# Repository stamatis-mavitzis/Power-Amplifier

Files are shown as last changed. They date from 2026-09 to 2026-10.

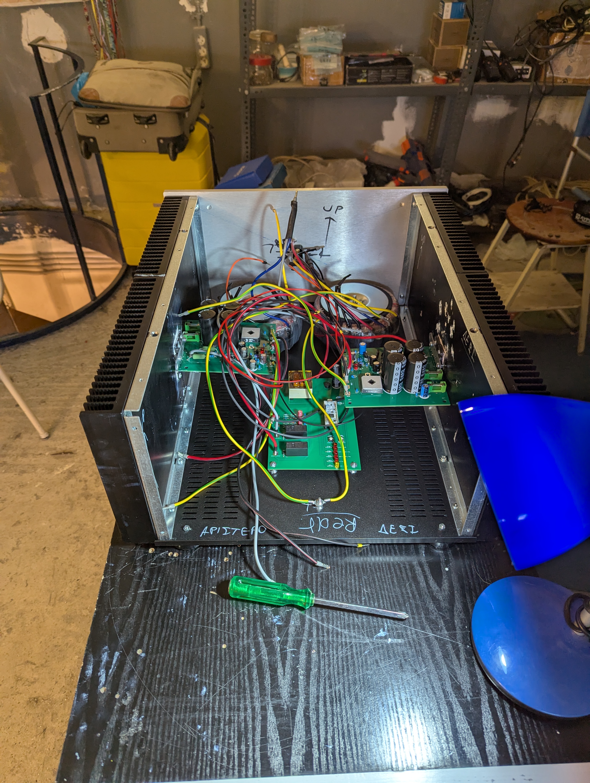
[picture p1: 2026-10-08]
Images/PXL_20261008_074426405.MP.jpg

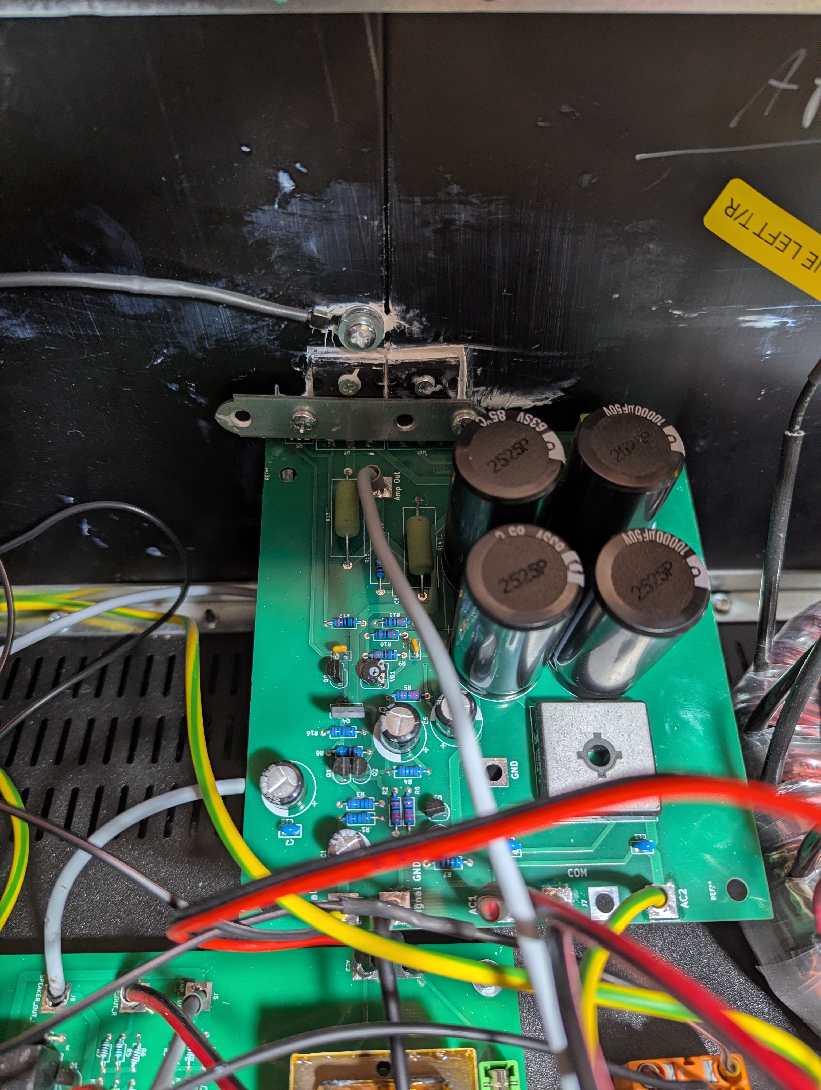
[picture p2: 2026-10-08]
Images/PXL_20261008_150713797.jpg

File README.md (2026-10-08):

<div align="center">

# Hi‑Fi Class‑AB Power Amplifier

### Stereo discrete power amplifier with dual 500 VA supplies, STM32 speaker protection, thermal monitoring, KiCad hardware, firmware, and measured prototype validation

**KiCad · Discrete Class‑AB · ≈±34.5 V Idle Rails · STM32G031K8 · Speaker Protection · Thermal Monitoring**






</div>

---

## Overview

This repository contains the design, implementation, firmware, fabrication files, and measured validation of a two-channel discrete **Hi‑Fi Class‑AB power amplifier** developed in **KiCad**.

The power-amplifier stage is based on the design principles of **Rod Elliott's Elliott Sound Products (ESP) Project 3A**. This implementation expands that reference design into a complete stereo amplifier system with:

- one dedicated **500 VA transformer per audio channel**;
- independent high-current rectification and filtering for the left and right channels;
- custom amplifier and power-supply PCBs;
- **MJL21193G / MJL21194G** complementary output devices;
- a dedicated **STM32G031K8 speaker-protection controller**;
- independent left/right DC monitoring;
- dual heatsink-temperature monitoring;
- relay-controlled speaker outputs;
- firmware for startup delay, fault handling, thermal protection, and status indication;
- measured electrical validation of the completed prototype.

The repository is intended to document the project from schematic design and PCB layout through assembly, firmware, bring-up, and bench testing.

---

## Project Status

The amplifier has progressed beyond the design-only stage.

Current status:

- amplifier PCBs assembled;
- power-supply hardware assembled;
- dual-transformer stereo supply implemented;
- STM32 protection system programmed and tested;
- left and right amplifier channels operational;
- speaker relays and protection functions tested;
- DC operating points measured;
- quiescent bias measured cold and warm;
- rail voltages measured at idle and under 8 Ω load;
- rail ripple measured under load;
- frequency-response checks completed;
- upper −3 dB point measured;
- final bench-test results recorded.

The project should therefore be described as a **built and functionally validated prototype**, not only as a planned or fabrication-ready design.

---

## Table of Contents

- [Key Features](#key-features)
- [Technical Summary](#technical-summary)
- [Measured Performance](#measured-performance)
- [System Architecture](#system-architecture)
- [Power Amplifier](#power-amplifier)
- [Power Supply](#power-supply)
- [STM32 Protection Controller](#stm32-protection-controller)
- [Protection Logic](#protection-logic)
- [Thermal Management](#thermal-management)
- [PCB Design Strategy](#pcb-design-strategy)
- [Grounding Strategy](#grounding-strategy)
- [Major Components](#major-components)
- [Test Equipment](#test-equipment)
- [Repository Structure](#repository-structure)
- [Manufacturing Files](#manufacturing-files)
- [Bring-Up and Validation](#bring-up-and-validation)
- [Measurement Limitations](#measurement-limitations)
- [Safety](#safety)
- [Design Tools](#design-tools)
- [Reference Design and Credits](#reference-design-and-credits)
- [Author](#author)

---

## Key Features

### Audio Power Stage

- Two-channel discrete **Class‑AB** architecture
- One amplifier PCB per channel
- Complementary bipolar output stage
- **MJL21193G / MJL21194G** complementary output transistor pair
- **BD139 / BD140** driver stage
- **0.33 Ω / 5 W** emitter resistors
- Through-hole power devices for serviceability and heatsink mounting
- Dedicated external heatsink for each amplifier channel
- On-board **3 A** positive- and negative-rail fuses

### Main Power Supply

- **2 × 500 VA transformers**
- One transformer dedicated to the **left channel**
- One transformer dedicated to the **right channel**
- Nominal dual low-voltage secondary windings
- Measured transformer secondary voltages of approximately **25.5–25.7 VRMS per half-secondary**
- High-current bridge rectification
- **KBPC3506WP** bridge rectifier in the power-supply design
- Four **4700 µF** reservoir capacitors on the power-supply schematic
- Measured idle rails of approximately **+34.5 V / −34.5 V**
- Measured loaded rails of approximately **±33.5 to ±33.7 V** with an 8 Ω load

### Protection and Monitoring

- **ST NUCLEO‑G031K8**
- **STM32G031K8** microcontroller
- Independent left/right amplifier-output monitoring
- Independent left/right heatsink-temperature monitoring
- 10 kΩ NTC thermistors
- Startup speaker delay
- Persistent-DC fault detection
- Overtemperature shutdown
- Sensor-fault handling
- Latched fault handling and reset
- Relay-controlled left/right speaker outputs
- Front-panel status indication

### Mechanical and Thermal Design

- Large external heatsinks
- Passive natural-convection cooling
- Power transistors positioned near PCB edges for heatsink mounting
- Electrical insulation between power-transistor tabs and heatsink where required
- Metal-chassis integration
- Star-ground implementation
- Chassis protective-earth bonding
- High-current speaker and supply wiring separated from low-level input wiring

---

## Technical Summary

| Parameter | Final implementation |
|---|---|
| Amplifier topology | Discrete Class‑AB |
| Number of channels | 2 |
| Main transformers | **2 × 500 VA**, one per channel |
| Measured secondary voltage | ≈25.5–25.7 VRMS from each outer secondary lead to center tap |
| Measured idle rails | ≈+34.5 V / −34.5 V |
| Measured rails under 8 Ω test load | ≈±33.5 to ±33.7 V |
| Output devices | **MJL21194G (NPN) / MJL21193G (PNP)** |
| Output-device package | **TO‑264, through-hole** |
| Driver devices | **BD139 / BD140** |
| Output emitter resistors | **R13 / R14 = 0.33 Ω, 5 W** |
| Amplifier rail fuses | **3 A** |
| Protection controller | ST NUCLEO‑G031K8 |
| MCU | STM32G031K8 |
| Speaker relays | 2 × Omron G2RL‑1A‑E‑DC12 |
| Relay driver | BC337 NPN |
| Temperature sensing | 2 × 10 kΩ NTC |
| Cooling | External heatsinks, passive natural convection |
| Audio inputs | RCA |
| Speaker outputs | Chassis-mounted binding terminals |
| PCB CAD | KiCad |

---

# Measured Performance

The following values were measured on the completed prototype. They are reported as **bench-test results**, not as guaranteed production specifications.

## Transformer Secondary Voltages

Measured from each AC secondary lead to the center tap:

| Measurement | Left | Right |
|---|---:|---:|
| AC1 → center tap | 25.652 VRMS | 25.628 VRMS |
| AC2 → center tap | 25.631 VRMS | 25.516 VRMS |

The measurements show good agreement between the two transformer channels.

## DC Supply Rails

### Idle

| Rail | Left | Right |
|---|---:|---:|
| Positive | +34.521 V | +34.566 V |
| Negative | −34.532 V | −34.522 V |

### Under 8 Ω Amplifier Load

| Rail | Left | Right |
|---|---:|---:|
| Positive | +33.534 V | +33.678 V |
| Negative | −33.560 V | −33.701 V |

The measured rail reduction under the recorded load condition is approximately 0.8–1.0 V compared with idle.

## Rail Ripple Under 8 Ω Load

Recorded ripple values:

| Rail | Left | Right |
|---|---:|---:|
| Positive rail | 1.5 V | 1.4 V |
| Negative rail | 1.6 V | 1.4 V |

These values are reproduced as recorded in the measurement log. They should not be interpreted as a different RMS or peak-to-peak quantity unless the oscilloscope measurement mode used during the test is also specified.

## Quiescent Bias

Bias was measured as the voltage across **R13 + R14**.

Because each emitter resistor is **0.33 Ω**, the combined resistance is **0.66 Ω**.

| Channel | Cold voltage | Approx. cold current | Warm voltage | Approx. warm current |
|---|---:|---:|---:|---:|
| Left | 41.700 mV | 63.2 mA | 52.55 mV | 79.6 mA |
| Right | 41.730 mV | 63.2 mA | 55.71 mV | 84.4 mA |

The increase from cold to warm operation is documented so that bias thermal behaviour remains traceable.

## DC Output Offset

Initial recorded DC-offset measurements:

| Channel | DC offset |
|---|---:|
| Left | −54.54 mV |
| Right | −28.203 mV |

A later no-signal measurement recorded:

| Channel | Amplifier output |
|---|---:|
| Left | +42.300 mV |
| Right | −23.764 mV |

Because these measurements were taken at different points in the test sequence, they are retained separately rather than combined into a single nominal value.

## Frequency Response and Voltage Gain

With:

- input signal: **1.2 V peak-to-peak**;
- sine-wave test;
- test frequencies: **20 Hz, 50 Hz, 100 Hz, 500 Hz, 1 kHz, 5 kHz, 10 kHz, 20 kHz**;

the recorded output was approximately:

- Left: **22.6 V peak-to-peak**
- Right: **22.6 V peak-to-peak**

This corresponds to:

- voltage gain: **18.83 V/V**
- voltage gain: **25.50 dB**

No significant amplitude reduction was recorded over the tested **20 Hz to 20 kHz** audio band.

The recorded **upper −3 dB frequency** is approximately:

**250 kHz**

The protection controller may interpret very-low-frequency content below approximately **15 Hz** as a DC-like condition. This is a **protection-system behaviour**, not the amplifier's measured low-frequency −3 dB cutoff.

## 8 Ω Loaded Signal Test

With an **8 Ω load** and **Vin = 1.2 V peak-to-peak**:

| Channel | Vout | Gain V/V | Gain dB | Approx. power into 8 Ω |
|---|---:|---:|---:|---:|
| Left | 27.2 Vpp | 22.67 | 27.11 dB | 11.56 W |
| Right | 26.6 Vpp | 22.17 | 26.91 dB | 11.06 W |

The right-channel gain is **26.91 dB** from the recorded 26.6 Vpp / 1.2 Vpp values.

This test point is **not** the maximum unclipped output-power rating of the amplifier. It only documents the specific load and signal level used during that measurement.

## Protection-System Measurements

Healthy amplifier outputs produced the following DC-sense ADC voltages:

| Channel | ADC sense voltage |
|---|---:|
| Left | 1.6014 V |
| Right | 1.5969 V |

Relay-driver base voltage with relays ON:

| Channel | Base voltage |
|---|---:|
| Left | 3.2932 V |
| Right | 3.2931 V |

Relay-coil voltage with relays ON:

| Channel | Coil voltage |
|---|---:|
| Left | 11.723 V |
| Right | 11.735 V |

NTC room-temperature readings:

| Sensor | Voltage |
|---|---:|
| NTC 1 | 1.1230 V |
| NTC 2 | 1.1225 V |

The remaining protection-system functional tests were recorded as **passed**.

---

## System Architecture

The complete amplifier is divided into three main functional paths:

1. **Audio path**
2. **Power path**
3. **Protection path**

### Audio Path

```text
RCA INPUT
    │
    ▼
┌───────────────────────┐
│  Discrete Class‑AB    │
│  Power Amplifier      │
│                       │
│  • Input stage        │
│  • Voltage gain stage │
│  • Bias network       │
│  • Driver stage       │
│  • Output stage       │
└───────────┬───────────┘
            │
            ▼
┌───────────────────────┐
│  Speaker Protection   │
│  Relay                │
└───────────┬───────────┘
            │
            ▼
       SPEAKER OUT
```

### Power Path

```text
                         230 VAC MAINS
                               │
               ┌───────────────┴───────────────┐
               ▼                               ▼
      500 VA TRANSFORMER #1           500 VA TRANSFORMER #2
           LEFT CHANNEL                    RIGHT CHANNEL
               │                               │
               ▼                               ▼
       RECTIFIER + FILTER              RECTIFIER + FILTER
               │                               │
               ▼                               ▼
        LEFT ±34 V RAILS                RIGHT ±34 V RAILS
               │                               │
               ▼                               ▼
        LEFT AMPLIFIER                  RIGHT AMPLIFIER
```

Each channel therefore has its own transformer and power-supply path, reducing shared supply impedance between the two amplifier channels.

### Protection Path

```text
Left Amp Output  ─────► DC Sense ───────┐
Right Amp Output ─────► DC Sense ───────┤
Left Heatsink NTC ────► Temp Sense ─────┤
Right Heatsink NTC ───► Temp Sense ─────┤
                                         ▼
                              ┌────────────────────┐
                              │   STM32G031K8      │
                              │                    │
                              │ • ADC acquisition  │
                              │ • Startup delay    │
                              │ • Fault logic      │
                              │ • Thermal logic    │
                              └─────────┬──────────┘
                                        │
                                  Relay drivers
                                        │
                                  ┌─────┴─────┐
                                  ▼           ▼
                              Left relay  Right relay
                                  │           │
                                  ▼           ▼
                              Left spk.   Right spk.
```

---

## Power Amplifier

The audio section uses a conventional **discrete Class‑AB power-amplifier topology** based on the principles of ESP Project 3A.

Functional stages include:

1. **Input stage** — accepts the low-level audio signal.
2. **Voltage-amplification stage** — provides the main voltage gain.
3. **Bias network** — establishes Class‑AB idle current.
4. **Driver stage** — provides base drive for the power output devices.
5. **Complementary output stage** — supplies current to the loudspeaker.

### Output Devices

| Reference | Device | Polarity | Package |
|---|---|---|---|
| Q7 | **MJL21193G** | PNP | TO‑264 |
| Q8 | **MJL21194G** | NPN | TO‑264 |

The output devices are mounted close to the PCB edge so that they can be attached directly to the external heatsink.

Electrical isolation hardware and thermal-interface material must be used where required by the mechanical installation.

### Driver Stage

The amplifier uses complementary **BD139 / BD140** driver transistors.

### Output Emitter Resistors

- **R13 = 0.33 Ω / 5 W**
- **R14 = 0.33 Ω / 5 W**

These resistors are also used as convenient measurement points for the output-stage quiescent current.

### Rail Protection

Each amplifier board includes:

- **3 A fuse in the positive rail**
- **3 A fuse in the negative rail**

These fuses protect the amplifier board but do not replace the required mains-side transformer protection.

---

## Power Supply

The final stereo implementation uses a **dual-mono-style power architecture**:

- one **500 VA transformer** for the left channel;
- one **500 VA transformer** for the right channel.

Each transformer has a center-tapped secondary arrangement and feeds its own rectifier/filter path.

Measured secondary voltages are approximately **25.5–25.7 VRMS from each outer secondary lead to the center tap**.

After rectification and reservoir filtering, the measured idle rails are approximately:

```text
+34.5 V
  0 V
−34.5 V
```

Under the recorded 8 Ω load test, the rails remained approximately **±33.5 to ±33.7 V**.

### Rectification and Filtering

The power-supply schematic uses:

- **Diotec KBPC3506WP** bridge rectifier;
- four **4700 µF** reservoir capacitors;
- local bypass capacitors;
- heavy-current connections for the DC rails and common return.

### Power-Supply Design Priorities

- short transformer-to-rectifier wiring;
- short rectifier-to-reservoir-capacitor paths;
- adequate conductor cross-section;
- deliberate star grounding;
- high-current speaker returns separated from input ground;
- secure protective-earth bonding;
- mains-rated switchgear, wiring, insulation, and fuse protection;
- independent left/right channel supply paths.

---

## STM32 Protection Controller

Speaker protection is implemented with an **ST NUCLEO‑G031K8** carrying the **STM32G031K8** microcontroller.

The controller supervises both amplifier channels and only connects the loudspeakers when the monitored conditions are safe.

### ADC Inputs

The controller monitors:

| Signal | MCU pin / ADC input |
|---|---|
| TEMP1 | PA0 / A0 |
| TEMP2 | PA1 / A1 |
| DC_LEFT | PA4 / A2 |
| DC_RIGHT | PA5 / A3 |

The firmware uses ADC averaging to improve measurement stability.

### Protection Timing and Thermal Thresholds

Current firmware configuration includes:

- startup delay: **3 s**
- periodic protection sampling
- overtemperature trip: approximately **100 °C**
- thermal reset threshold: approximately **90 °C**
- latched fault handling where applicable
- manual fault-reset support

### Controlled Outputs

The controller operates:

- left speaker relay;
- right speaker relay;
- status and fault LEDs;
- relay drivers through BC337 transistors.

---

## Protection Logic

### Startup Delay

At power-up, the loudspeakers remain disconnected while the MCU initializes and checks the monitored conditions.

```text
POWER ON
   │
   ▼
MCU INITIALIZATION
   │
   ▼
ADC + GPIO INITIALIZATION
   │
   ▼
VERIFY SENSOR / DC CONDITIONS
   │
   ▼
3 s STARTUP DELAY
   │
   ▼
ENABLE SPEAKER RELAYS
```

If a fault exists, the speaker relays remain disabled.

### DC Protection

The left and right amplifier outputs are independently monitored through conditioned ADC inputs.

A persistent abnormal positive or negative DC component causes the controller to disable the associated speaker connection.

```text
ABNORMAL DC
     │
     ▼
STM32 FAULT DECISION
     │
     ▼
RELAY DRIVER OFF
     │
     ▼
SPEAKER DISCONNECTED
```

The healthy operating point of the DC-sense channels is approximately **1.6 V**, allowing the circuit to detect excursions in either direction.

### Very-Low-Frequency Behaviour

The implemented protection logic may classify signals below approximately **15 Hz** as DC-like.

This should not be confused with the amplifier's audio-band frequency response.

### Temperature Protection

Each channel uses a **10 kΩ NTC thermistor** attached to the thermal system.

```text
LEFT HEATSINK  ──► NTC ──► ADC
RIGHT HEATSINK ──► NTC ──► ADC
```

The controller can disconnect the loudspeakers when the thermal trip threshold is reached.

### Relay Drive

The STM32 does not energize the relay coils directly.

Each channel uses:

```text
STM32 GPIO
    │
    ▼
Base resistor
    │
    ▼
BC337 NPN
    │
    ▼
12 V relay coil
    │
    └── Flyback diode
```

Measured relay-coil voltage in the ON state is approximately **11.7 V**.

### Speaker Relays

Two **Omron G2RL‑1A‑E‑DC12** relays are used:

- one for the left channel;
- one for the right channel.

---

## Thermal Management

The amplifier is designed for passive cooling using external chassis heatsinks.

The thermal design includes:

- one external heatsink per amplifier channel;
- direct mounting of the TO‑264 power transistors;
- electrical insulation where required;
- thermal compound / thermal interface material;
- NTC sensing;
- firmware-based overtemperature protection;
- natural-convection airflow;
- no fan dependency.

The output-stage bias was measured both cold and after thermal stabilization to document thermal drift.

---

## PCB Design Strategy

The PCB layout was developed with audio performance, current handling, serviceability, and manufacturability in mind.

### High-Current Paths

High-current paths include:

- rectifier connections;
- reservoir-capacitor charging loops;
- ± rail distribution;
- output-stage supply paths;
- speaker-output routing;
- speaker-return current;
- relay contacts.

These paths should be kept short and wide.

### Small-Signal Paths

Sensitive nodes include:

- RCA input;
- input-stage circuitry;
- feedback network;
- bias-related nodes;
- low-level signal ground.

These are kept away from rectifier, relay-coil, transformer, and speaker-current paths as much as practical.

### Serviceability

Through-hole components are used extensively so that stressed devices, connectors, relays, drivers, and power transistors can be replaced during repair or development.

---

## Grounding Strategy

The final system uses a deliberate **star-ground approach**.

Both transformer center taps are brought to the central high-current ground reference, together with the appropriate power-supply returns.

The grounding strategy distinguishes between:

```text
SENSITIVE SIGNAL GROUND
         │
         ▼
CENTRAL / STAR REFERENCE
         ▲
         │
HIGH-CURRENT POWER GROUND
```

Design goals:

- prevent rectifier charging current from flowing through input-signal ground;
- keep feedback references electrically quiet;
- keep speaker return as a high-current path;
- avoid long shared ground traces;
- minimize hum and channel interaction;
- keep protection-controller current from disturbing the analog signal reference.

The metal chassis protective earth is treated separately from the audio star-ground function and must remain securely bonded for safety.

---

## Major Components

| Function | Selected component / specification |
|---|---|
| NPN output transistor | **MJL21194G** |
| PNP output transistor | **MJL21193G** |
| Driver transistors | **BD139 / BD140** |
| Output emitter resistors | **0.33 Ω / 5 W** |
| Amplifier rail fuses | **3 A** |
| Main transformers | **2 × 500 VA**, one per channel |
| Main bridge rectifier | **Diotec KBPC3506WP** |
| Reservoir capacitors | **4 × 4700 µF** on the power-supply schematic |
| Protection development board | **ST NUCLEO‑G031K8** |
| MCU | **STM32G031K8** |
| Speaker relays | **Omron G2RL‑1A‑E‑DC12** |
| Relay driver | **BC337** |
| Temperature sensors | **10 kΩ NTC** |
| Audio input | RCA |
| Speaker output | Chassis-mounted binding terminals |
| Cooling | External passive heatsinks |

---

## Test Equipment

The completed amplifier was tested using the following bench instruments:

| Instrument | Model | Use |
|---|---|---|
| Oscilloscope | **UNI‑T UPO1202** | Waveform, amplitude, ripple, frequency-response and output measurements |
| Function / signal generator | **OWON DGE1030** | Sine-wave test-signal generation |
| Digital multimeter | **OWON XDM2041** | DC rails, bias, offsets, relay voltages, sensor voltages and continuity checks |

Measurement results in this README should be interpreted together with the stated load, signal amplitude, and test condition.

---

## Repository Structure

```text
Power-Amplifier/
│
├── Firmware/
│   └── STM32/
│
├── Images/
│
├── KiCad/
│
├── Libraries/
│
├── Manufacturing/
│
├── PDF/
│
├── Schematics/
│
└── README.md
```

### Directory Overview

| Path | Contents |
|---|---|
| `Firmware/STM32/` | STM32 source, configuration, project files, and protection-controller firmware |
| `Images/` | Project photographs, PCB renders, diagrams, and screenshots |
| `KiCad/` | Editable KiCad schematic and PCB project files |
| `Libraries/` | Project-specific KiCad symbols and footprints |
| `Manufacturing/` | Gerber and drill outputs for PCB fabrication |
| `PDF/` | PDF exports and project documentation |
| `Schematics/` | Exported schematic drawings |
| `README.md` | Main project overview and measured validation summary |

---

## Manufacturing Files

The fabrication package contains the files required by a typical PCB manufacturer.

### Gerber Outputs

Typical exported layers include:

- copper;
- solder mask;
- silkscreen;
- board outline / `Edge.Cuts`;
- other fabrication layers required by the board.

### Drill Outputs

The project distinguishes between:

- **PTH** — plated through holes;
- **NPTH** — non-plated mechanical holes, where present.

Gerber files and drill files are both required for a complete PCB manufacturing package.

---

## Bring-Up and Validation

The completed hardware was commissioned using a staged validation procedure.

### 1. Visual and Assembly Inspection

- verify transistor orientation and pinout;
- verify MJL21193G / MJL21194G mounting;
- verify insulation from heatsink where required;
- verify electrolytic polarity;
- verify diode and relay orientation;
- inspect solder joints and high-current connections.

### 2. Unpowered Electrical Checks

- continuity;
- rail-to-ground short checks;
- transistor junction checks;
- ground-path verification;
- output-stage connection verification.

### 3. Power-Supply Validation

- verify transformer secondaries;
- verify bridge-rectifier polarity;
- measure positive and negative rails;
- compare left and right channels;
- measure rail behaviour under load.

### 4. Controlled Amplifier Power-Up

- loudspeakers disconnected initially;
- monitor DC offset;
- monitor bias voltage;
- monitor transistor temperature;
- verify no uncontrolled rail current.

### 5. Protection Validation

- startup delay;
- DC monitoring;
- relay operation;
- NTC sensing;
- thermal handling;
- sensor-fault behaviour;
- fault indication;
- reset behaviour.

### 6. Signal Validation

- apply a known sine-wave input;
- observe the amplifier output on the oscilloscope;
- test with a suitable resistive load;
- verify operation across the audio-frequency range;
- progressively increase signal level while monitoring rails and temperature.

---

## Measurement Limitations

The current measurement set documents successful functional operation and several important electrical characteristics.

The following values have **not** been established as formal amplifier specifications and should not be claimed without additional controlled measurements:

- THD / THD+N;
- signal-to-noise ratio;
- channel separation / crosstalk;
- maximum continuous output power;
- maximum unclipped output voltage at clipping;
- full thermal-rise curve versus continuous output power;
- damping factor;
- slew rate.

Because no additional measurements are currently available, this README reports only the values that were actually recorded or that can be directly calculated from those recorded values.

---

## Safety

> This project interfaces with **230 VAC mains voltage** and contains high-current circuitry and large energy-storage capacitors. Incorrect construction or testing can cause electric shock, fire, equipment damage, or component failure.

Important safety requirements include:

- correctly rated mains fuse protection;
- protective-earth bonding to the metal chassis;
- mains-rated switch and wiring;
- suitable insulation;
- correct conductor cross-section;
- strain relief;
- secure transformer mounting;
- adequate creepage and clearance;
- insulated exposed mains connections;
- safe transistor/heatsink insulation;
- awareness that reservoir capacitors retain stored energy after shutdown.

**Never service, modify, or probe the mains section while the unit is energized.**

---

## Design Tools

| Tool / source | Purpose |
|---|---|
| **KiCad** | Schematic capture, PCB design, footprints, and fabrication outputs |
| **STM32CubeMX** | STM32 peripheral and project configuration |
| **STM32CubeIDE** | STM32 firmware development, programming, and debugging |
| **Mouser Electronics** | Component sourcing |
| **Manufacturer datasheets** | Electrical, thermal, package, and footprint verification |
| **Git / GitHub** | Version control and repository documentation |

---

## Reference Design and Credits

The core amplifier topology is based on:

**Rod Elliott — Elliott Sound Products (ESP), Project 3A Power Amplifier**

Reference:

https://sound-au.com/project3a.htm

Credit for the original amplifier topology belongs to **Rod Elliott / Elliott Sound Products**.

This repository documents the project-specific implementation around that topology, including:

- PCB implementation;
- component selection;
- dual 500 VA transformer architecture;
- power-supply integration;
- STM32 protection controller;
- DC monitoring;
- temperature monitoring;
- relay control;
- firmware;
- grounding;
- chassis integration;
- fabrication files;
- prototype assembly;
- measured validation.

---

## Engineering Goals

The project was developed around the following objectives:

- reliable discrete Class‑AB amplification;
- independent left/right power delivery;
- speaker protection against persistent DC;
- temperature monitoring and shutdown;
- low-noise PCB layout;
- deliberate grounding;
- practical current handling;
- serviceable construction;
- sourceable components;
- reproducible PCB fabrication;
- embedded protection firmware;
- measured bench validation;
- clear engineering documentation.

---

## Author

**Stamatis Mavitzis**  
Electrical & Computer Engineering

Designed in **KiCad**.

---

<div align="center">

### Hi‑Fi Power Amplifier · Engineering Project

*Discrete Class‑AB audio amplification, dual 500 VA power supplies, STM32 protection, PCB design, firmware, manufacturing files, and measured prototype validation.*

</div>

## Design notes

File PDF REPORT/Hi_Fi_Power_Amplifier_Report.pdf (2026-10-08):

# Hi-Fi Power Amplifier

## Final Design, Protection and Measurement Report

### Discrete Class-AB Stereo Power Amplifier with STM32-Based Loudspeaker Protection

Author: | Stamatis Mavitzis
Reference topology: Rod Elliott Project 3A
PCB design: | KiCad
Protection MCU: | STM32G031K8
Final main PSU: | Two dedicated 500 VA transformers
Report edition: | Final measurement edition
Date: | October 2026

### Engineering Construction, Commissioning and Verification Report

# Contents

Abstract | v
1 Project Overview and Final Configuration | 1
2 Power Amplifier Design and Operation | 3
3 Main Power Supply, Grounding and Thermal Design | 5
4 STM32 Loudspeaker Protection Controller | 7
5 Construction and Commissioning | 9

i

Hi-Fi Power Amplifier | Final Engineering Report
6 Measurement Equipment and Method | 10
7 Final Measurement Results | 11
8 Discussion of Results | 16
9 Troubleshooting and Engineering Corrections | 18
10 Conclusion | 19
A Instrumentation Record | 20
B Design Source Files | 21
C Original Measurement Log (Transcribed) | 22

ii

iii

# List of Tables

1.1 Final system configuration | | 2
6.1 Measurement instruments used for final verification | | 10
7.1 Measured transformer secondary voltages | | 11
7.2 Measured DC rail voltages | | 11
7.3 Recorded rail ripple under 8 W load | | 12
7.4 Measured bias voltage and calculated quiescent current | | 12
7.5 Measured initial amplifier output DC offset | | 13
7.6 Measured audio-band frequency response | | 13
7.7 Calculated quantities from the recorded 8 W loaded output test | | 14
7.8 Measured protection-controller voltages | | 15
C.1 Recorded transformer and supply voltages | | 22
C.2 Original bias and DC observations | | 23
C.3 Original controller voltage entries | | 23

iv

# Abstract

This report documents the design, construction, protection system, commissioning and final available measurements of a stereo discrete Class-AB audio power amplifier derived from Rod Elliott’s Project 3A. The completed system uses two identical amplifier channels, each supplied from its own 500 VA, 24–0–24 VRMS transformer and local rectifier/filter section. A separate STM32G031K8-based controller supervises both amplifier outputs, two heatsink NTC sensors and the loudspeaker relays.

The final measurement record includes transformer secondary voltages, positive and negative DC rails at idle and under an 8 W load, supply ripple, cold and warm quiescent-current readings, DC offset, audio-band frequency response, upper −3 dB bandwidth, a defined 8 W loaded output operating point, and protection-controller voltages. The measured audio-band response from 20 Hz to 20 kHz remained at 22.6 Vpp for a recorded 1.2 Vpp input, corresponding to 18.83 V/V or 25.50 dB. The measured upper −3 dB frequency was approximately 250 kHz.

No additional measurements are available. Therefore this report deliberately does not invent maximum unclipped output power, THD, SNR, damping factor, or other unrecorded quantities. Where a numerical result is derived from a recorded measurement, it is explicitly identified as calculated rather than directly measured.

v

# Chapter 1

# Project Overview and Final Configuration

## 1.1 Project Objective

The objective of the project was to implement a complete stereo Hi-Fi power amplifier rather than only an isolated amplifier circuit. The final system integrates the analogue power stage, high-current power supply, thermal management, grounding, PCB construction and a dedicated loudspeaker-protection controller.

The analogue amplifier is based on Rod Elliott’s Project 3A and uses a conventional discrete Class-AB topology with global negative feedback. The protection controller is physically and functionally separate from the audio signal path. It monitors DC conditions and temperature and controls normally-open loudspeaker relays.

## 1.2 Final Hardware Architecture

The final main-power arrangement is dual-mono at transformer level: one 500 VA, 24–0– 24 VRMS transformer is dedicated to the left channel and a second identical transformer is dedicated to the right channel. Each amplifier channel therefore has its own high-current AC source and rectified DC rails. The centre-tap/power-ground returns are brought to the system star-ground arrangement.

This final configuration supersedes the earlier single-transformer concept that appeared in preliminary design notes. The measured left and right transformer secondary values in Chapter 7 confirm the two-channel supply arrangement.

Table 1.1: Final system configuration.

Item | Final implementation
Amplifier | Discrete stereo Class-AB, Project 3A-derived
Main transformers | Two 500 VA transformers, one per channel
Secondary voltage | Nominal 24–0–24 VRMS per transformer
Rectification | High-current bridge rectifier per channel supply
Filter capacitance | Two 4700 µF capacitors in parallel per rail, 9400 µF effective per rail
Output devices | MJL21193G (PNP) and MJL21194G (NPN)
Drivers | BD139 / BD140
Emitter resistors | 0.33 W each (R13, R14)
Protection MCU | STM32G031K8 on NUCLEO-G031K8
Temperature sensing | Two 10 kW NTC thermistors
Speaker relays | Normally-open 12 V coils
Cooling | Passive heatsinks, no fan

## 1.3 System Signal and Power Paths

The audio path is

Input → Power Amplifier → Protection Relay → Loudspeaker.

The main energy path is

Mains → Transformer → Bridge Rectifier → Filter Capacitors → ±VS → Amplifier.

The protection controller operates in parallel with the audio path. It senses the slowly varying/DC component of each output and the two heatsink sensors, but it does not process the audio signal itself.

# Chapter 2

# Power Amplifier Design and Operation

## 2.1 Topology

Each channel contains an input network, differential input stage, voltage-amplification stage, bias/driver circuitry and a complementary high-current output stage. Global negative feedback returns a fraction of the output to the inverting input so that the amplifier corrects the difference between the requested and actual output:

Verror = Vinput − Vfeedback.

The differential stage provides the error signal, the voltage-amplification stage develops the required internal voltage swing, and the driver/output devices provide the load current required by the loudspeaker.

## 2.2 Nominal Closed-Loop Gain

The nominal feedback network is approximately

R5 = 22 kΩ, R4 = 1 kΩ.

The ideal non-inverting closed-loop gain is therefore
Av ≈ 1 + | R5 R4 = 23,

or
Av,dB = 20 log10(23) ≈ 27.2 dB.

This is a design value, not a substitute for measured gain. The final measured values are reported separately in Chapter 7.

## 2.3 Class-AB Bias

The two emitter resistors are R13 = R14 = 0.33 Ω.

When the voltage is measured across both resistors together,

R13 + R14 = 0.66 Ω,

and the corresponding quiescent current is calculated as

IQ =

VR13+R14
0.66 Ω .

A 50 mA nominal reference would correspond to approximately

VR13+R14 = 33 mV.

The actual final cold and warm values were higher than this nominal reference and are reported without alteration in Section 7.4.

## 2.4 Output Stage and Load Current

The final output pair is MJL21193G (PNP) and MJL21194G (NPN), manufactured by onsemi. The output devices are driven by BD139/BD140 transistors and are heatsink mounted.

For a resistive load,

IRMS =

VRMS
RL

, Pout =

V

2
RMS
RL

A 4 W load requires twice the current of an 8 W load at the same output voltage, so it is a more severe test of the transistors, emitter resistors, PCB copper, supply and thermal system. No quantitative 4 W output-power measurement is available in the final record, so no measured 4 W power claim is made.

## 2.5 Output Stability Network

The output includes an RC Zobel/Boucherot network to present a more predictable high-frequency load. This is important because a loudspeaker and its cable are reactive rather than purely resistive, and the global-feedback amplifier must remain stable when driving practical loads.

# Chapter 3

# Main Power Supply, Grounding and Thermal Design

## 3.1 Rectified Rail Voltage

For a nominal 24 VRMS half-secondary,
Vpeak = 24√
2 ≈ 33.94 V.

The real no-load value can be slightly higher because of transformer regulation, while loaded rails fall because of winding resistance, rectifier loss, capacitor ESR, wiring and capacitor discharge between charging peaks.

The final recorded idle rails were approximately ±34.5 V, in good agreement with the expected range for the selected transformer voltage.

## 3.2 Smoothing Capacitors and Ripple

Two 4700 µF capacitors are paralleled on each rail, giving

Crail = 9400 µF.

At 50 Hz mains frequency, full-wave rectification produces a principal charging/ripple frequency of approximately 100 Hz. A first-order estimate is

∆V ≈

I
fC ,

although the real waveform depends on the pulsed charging current and the audio load.

## 3.3 Grounding Strategy

The amplifier contains both low-level signal references and high-current return paths. The design therefore distinguishes signal ground, amplifier power ground, loudspeaker return, rectifier/filter return, protection-controller ground and protective earth.

High-current loudspeaker and capacitor-charging currents are returned to the main power-ground/star region instead of being allowed to flow through the input reference path. The metal chassis is bonded to protective earth independently of any audio-ground strategy.

## 3.4 Thermal Management

The output transistors are mounted to external passive heatsinks with appropriate electrical insulation and thermal interface material. The relevant thermal path can be expressed as

TJ = TA + PD (RθJC + RθCS + RθSA).

The warm quiescent-current data show a clear increase relative to the cold condition, which is why final bias should always be assessed after thermal stabilisation rather than only at switch-on.

# Chapter 4

# STM32 Loudspeaker Protection Controller

## 4.1 Functions

The STM32G031K8-based controller provides the following functions:

- approximately 3 s startup delay;
- left and right DC-output monitoring;
- two NTC temperature channels;
- sensor-plausibility/fault detection;
- relay control for left and right loudspeaker outputs;
- status/fault LED indication.

The normally-open relay arrangement is fail-safe with respect to loss of relay drive: if controller power or GPIO drive disappears, the loudspeaker is disconnected.

## 4.2 DC-Sense Interface

The power-amplifier output cannot be connected directly to a 0 V–3.3 V ADC input. The implemented sensing network attenuates and biases the amplifier output. Its approximate static relationship is
VADC ≈ 1.597 + 0.03226VAMP,

where VAMP is the slowly varying/DC component of the amplifier output.

Therefore a healthy amplifier output close to 0 V should appear near 1.6 V at the ADC, while positive or negative persistent DC shifts the ADC voltage above or below this centre value.

The sensing network also includes analogue low-pass filtering. This is essential because the controller should respond to persistent DC rather than the instantaneous audio waveform. The final measurement notes record that signals below approximately 15 Hz are treated by the protection system as DC-like input. This system behaviour limited the possibility of measuring a lower -3 dB cutoff below that region.

## 4.3 Temperature Monitoring

Each heatsink uses a 10 kW NTC thermistor. The resistance decreases with increasing temperature and can be approximated by

R(T) = R25 exp [︃
B

(︃

1
T

−

1

T25

)︃]︃ .

The firmware uses an approximate 100 °C over-temperature trip threshold. Sensor values outside the configured plausible range are also treated as faults so that a disconnected thermistor cannot be interpreted as a safe temperature.

## 4.4 Relay Drivers

Each 12 V relay coil is driven by a BC337 low-side transistor. The STM32 GPIO therefore supplies only the transistor base current, not the relay-coil current. Flyback diodes across the coils absorb the inductive current when the drivers switch off.

The final measured relay-driver and coil voltages are presented in Section 7.9.

# Chapter 5

# Construction and Commissioning

## 5.1 Pre-Power Verification

Before first power-up, polarity-sensitive components and transistor pinouts were checked, the supply rails were checked for shorts to ground, heatsink insulation was verified, and the speaker output was kept disconnected. The bridge rectifier and electrolytic capacitor polarities were treated as critical checks because an error in this area can cause immediate high-current failure.

## 5.2 Progressive Power-Up

Commissioning was performed progressively: supply verification, no-load amplifier operation, bias adjustment, DC-offset checks, protection-board testing and finally loaded testing. This approach reduces the chance that a single wiring or component error can damage the output stage or loudspeaker.

## 5.3 Troubleshooting During Development

The construction required several debugging iterations involving output-stage connections, driver bias, fuse operation, floating protection inputs and grounding. The final working configuration was obtained by verifying transistor health, checking DC operating points, grounding the audio input during diagnosis, correcting protection behaviour for floating DC-sense inputs and rechecking the amplifier after each hardware change.

The troubleshooting process is part of the engineering result: successful operation was not inferred only from schematic correctness or firmware compilation but verified on the assembled hardware.

# Chapter 6

# Measurement Equipment and Method

## 6.1 Laboratory Instruments

The final measurement campaign used the following main instruments:

Table 6.1: Measurement instruments used for final verification.

Instrument | Model | Main use in this project
Oscilloscope | UNI-T UPO1202 | Output waveform, peak-to-peak voltage, frequency response, ripple and clipping observation
Signal generator | OWON DGE1030 | Sine-wave excitation for gain and frequency-response tests
Digital multimeter | OWON XDM2041 | DC rails, offset, bias voltage, ADC/relay voltages and general commissioning

## 6.2 Measurement Conventions

Peak-to-peak and RMS quantities are not interchangeable. For a sinusoidal waveform,

VRMS =

Vpp
2

√
2

Voltage gain is calculated using like-for-like amplitude definitions:

Av =

Vout

Vin

, Av,dB = 20 log10(Av).

When output power is derived from a recorded sinusoidal voltage across a resistive load,

Pout =

V

2
RMS
RL

Derived values in this report are calculated only from recorded measurements; they are not additional measurements.

# Chapter 7

# Final Measurement Results

## 7.1 Transformer Secondary Measurements

The two dedicated transformers were measured from each outer secondary lead to the centre tap.

Table 7.1: Measured transformer secondary voltages.

Measurement | Left channel Right channel
AC1 to centre tap | 25.652 VRMS | 25.628 VRMS
AC2 to centre tap | 25.631 VRMS | 25.516 VRMS
Calculated outer-to-outer sum 51.283 VRMS | 51.144 VRMS

The outer-to-outer values above are calculated by summing the two measured half-secondary magnitudes; they were not separately recorded as direct measurements.

## 7.2 DC Rails at Idle and Under an 8 Ohm Load

Table 7.2: Measured DC rail voltages.

Condition | Left channel Right channel
Positive rail, idle | 34.521 V | 34.566 V
Negative rail, idle | −34.532 V | −34.522 V
Positive rail, 8 W load | 33.534 V | 33.678 V
Negative rail, 8 W load | −33.560 V | −33.701 V

The calculated positive-rail sag was 0.987 V (2.86 %) for the left channel and 0.888 V (2.57 %) for the right channel. The negative-rail magnitude decreased by 0.972 V (2.81 %) on the left and 0.821 V (2.38 %) on the right.

## 7.3 Rail Ripple Under Load

The recorded ripple values under the 8 W load condition were:

Table 7.3: Recorded rail ripple under 8 W load.

Rail | Left channel Right channel
Positive rail | 1.5 V | 1.4 V
Negative rail | 1.6 V | 1.4 V

The original measurement sheet records only the ripple magnitude in volts and does not separately state whether the displayed oscilloscope quantity was peak-to-peak or another amplitude statistic. The values are therefore reproduced exactly without relabelling them as Vpp or VRMS.

## 7.4 Quiescent Current and Thermal Stabilisation

The measured voltage across R13+R14 was converted to quiescent current using

IQ =

VR13+R14
0.66 Ω .

Table 7.4: Measured bias voltage and calculated quiescent current.

Cold | Warm / stabilised
Channel | VR13+R14 | IQ | VR13+R14 | IQ
Left | 41.700 mV 63.18 mA 52.55 mV 79.62 mA
Right | 41.730 mV 63.23 mA 55.71 mV 84.41 mA

The warm current increased by approximately 26.0 % on the left channel and 33.5 % on the right relative to the cold readings. Both final warm values are above the earlier 50 mA nominal reference. Because no additional adjustment measurement is available, the report records the stabilised values as built rather than replacing them with the nominal design target.

## 7.5 DC Offset

The initial DC-offset measurements were:

Table 7.5: Measured initial amplifier output DC offset.

Channel Initial DC offset

Left | −54.54 mV
Right | −28.203 mV

These are small compared with the supply rails and do not represent a dangerous loudspeaker DC condition.

A later no-signal measurement in the same record produced 42.300 mV on the left channel and −23.764 mV on the right. Because the two measurement sets were taken under different undocumented timing/operating conditions, they are treated as separate snapshots rather than averaged together.

## 7.6 Audio-Band Frequency Response and Gain

The recorded frequency-response test used

Vin = 1.2 Vpp.

At every recorded frequency from 20 Hz through 20 kHz, both channels produced 22.6 Vpp.

Table 7.6: Measured audio-band frequency response.

Frequency Left output Right output

20 Hz | 22.6 Vpp | 22.6 Vpp
50 Hz | 22.6 Vpp | 22.6 Vpp
100 Hz | 22.6 Vpp | 22.6 Vpp
500 Hz | 22.6 Vpp | 22.6 Vpp
1 kHz | 22.6 Vpp | 22.6 Vpp
5 kHz | 22.6 Vpp | 22.6 Vpp
10 kHz | 22.6 Vpp | 22.6 Vpp
20 kHz | 22.6 Vpp | 22.6 Vpp

The measured voltage gain over this sweep is therefore

Av =

22.6
1.2

= 18.83 V/V,

which corresponds to
Av,dB = 20 log10(18.83) = 25.50 dB.

The response is flat to the resolution of the recorded data across the complete 20 Hz–20 kHz audio band.

## 7.7 Upper -3 dB Bandwidth

The measured upper −3 dB frequency was approximately

fH = 250 kHz.

For the 22.6 Vpp mid-band reference, the −3 dB voltage level is

V−3 dB = 0.707 × 22.6 ≈ 15.98 Vpp.

The lower −3 dB cutoff was not established. The system-level measurement was limited by the protection controller, which interprets frequencies below approximately 15 Hz as DC-like input. However, the measured 20 Hz point showed no attenuation relative to the rest of the recorded audio-band sweep.

## 7.8 8 Ohm Loaded Output Operating Point

With an 8 W load and 1.2 Vpp input, the recorded outputs were 27.2 Vpp on the left channel and 26.6 Vpp on the right.

Table 7.7: Calculated quantities from the recorded 8 W loaded output test.

Quantity | Left | Right
Measured output | 27.2 Vpp | 26.6 Vpp
Calculated gain | 22.67 V/V | 22.17 V/V
Calculated gain | 27.11 dB | 26.91 dB
Calculated output | 9.617 VRMS | 9.405 VRMS
Calculated power into 8 W | 11.56W | 11.06W

The raw record lists 27.23 dB for the right-channel loaded gain. Recalculation from its recorded 26.6 Vpp output and 1.2 Vpp input gives 26.91 dB; the recalculated value is used here while the original entry is transcribed in Appendix C.

This was a defined loaded operating point, not a recorded maximum-unclipped-output test. Consequently, 11.56W and 11.06W are powers at the measured test point and must not be interpreted as the maximum capability of the amplifier.

## 7.9 Protection Controller Measurements

Table 7.8: Measured protection-controller voltages.

Measurement | Left / Channel 1 Right / Channel 2
Healthy DC-sense ADC voltage | 1.6014 V | 1.5969 V
Relay-driver base voltage, ON | 3.2932 V | 3.2931 V
Relay-coil voltage, ON | 11.723 V | 11.735 V
NTC channel at room temperature | 1.1230 V | 1.1225 V

The healthy ADC readings are centred very close to the predicted approximately 1.6 V value of the DC-sense network. Relay-driver base voltages are essentially the STM32 3.3 V logic level, and the relay coils receive approximately 11.7 V in the energised state.

The measurement record states that all other protection-system tests passed. This includes the functional fault and relay behaviour exercised during commissioning. Detailed numerical timing and trip-point traces were not separately preserved, so only the pass result is claimed here.

# Chapter 8

# Discussion of Results

## 8.1 Power-Supply Performance

The measured transformer half-secondary values are around 25.5 VRMS–25.7 VRMS, slightly above the nominal 24 VRMS rating as expected under light loading. The resulting idle DC rails of approximately ±34.5 V are consistent with this secondary voltage after rectification and filtering.

Under the recorded 8 W load test, the rail magnitude fell only about 2.4 %–2.9 %. The left/right and positive/negative rails also remained closely symmetrical. This indicates good supply stiffness at the specific test operating point.

## 8.2 Bias Behaviour

The cold quiescent current was about 63 mA on both channels, showing good channel-to-channel agreement immediately after startup. The warm values increased to approximately 80 mA and 84 mA. The increase confirms the importance of thermal stabilisation when setting a Class-AB bias network.

The report does not claim that these warm currents are an optimum universal bias target; they are simply the final measured stabilised values. No later adjustment measurement is available.

## 8.3 Gain and Frequency Response

The audio-band sweep showed no recorded change in output amplitude between 20 Hz and 20 kHz. The measured sweep gain of 25.50 dB is somewhat below the simple nominal feedback-network estimate of about 27.2 dB. The separate loaded 8 W operating point gave gains around 27 dB. Because the test conditions were not identical, these results are presented as separate measurement sets rather than forced into a single number.

The upper −3 dB point at approximately 250 kHz is far above the audio band and shows substantial high-frequency bandwidth. The lower cutoff cannot be claimed because the protection system prevents a clean system-level test below approximately 15 Hz; nevertheless, the 20 Hz result remained at the mid-band level.

## 8.4 DC Offset and Speaker Safety

All recorded normal-operation output offsets are in the tens of millivolts, far below the dangerous multi-volt DC conditions the protection controller is designed to detect. The measured DC-sense ADC centres also agree closely with the analytical approximately 1.597 V healthy value, supporting correct biasing of the protection inputs.

## 8.5 What the Available Data Do Not Establish

Because no further measurements can be performed, the following quantities are intentionally not reported as measured performance specifications:

- maximum unclipped continuous output power;
- quantitative 4 W maximum output power;
- total harmonic distortion (THD or THD+N);
- signal-to-noise ratio and residual noise floor;
- damping factor / output impedance;
- slew rate;
- channel crosstalk;
- exact lower −3 dB cutoff;
- detailed thermal trip curve versus heatsink temperature.

This limitation does not invalidate the measurements that were obtained; it only defines the boundary of what can be claimed from the available evidence.

# Chapter 9

# Troubleshooting and Engineering Corrections

## 9.1 Output-Stage Debugging

During commissioning, one amplifier channel required extensive diagnosis of driver/output-stage connections, fuse operation and DC operating points. Output transistors and drivers were checked independently, and the amplifier was repeatedly tested with the input grounded so that a floating input could not be mistaken for an internal amplifier fault.

The final hardware operated correctly after the relevant connection and bias issues were resolved. This experience reinforced the importance of checking the exact pinout of each semiconductor against its datasheet rather than relying on package appearance.

## 9.2 Protection-Input Debugging

Floating protection-controller DC-sense inputs initially produced an apparent DC-fault condition because the ADC nodes sat near their internally biased centre even when no amplifier source was connected. Firmware/logic handling was adjusted so that the practical system no longer produced the false fault observed during commissioning.

## 9.3 Grounding and Load Diagnosis

A hum/oscillation symptom was observed with one particular 4 W loudspeaker but not with an 8 W resistor or other speakers. This indicated that the symptom was load/system-specific rather than a universal no-load amplifier failure. High-current grounding, speaker wiring and reactive-load behaviour were therefore treated separately from basic DC stability.

# Chapter 10

# Conclusion

The project resulted in a complete working stereo Class-AB amplifier system with inde-pendent high-current transformers for the two channels and an STM32-based loudspeaker-protection controller. The final system architecture addresses not only voltage gain but also power delivery, grounding, thermal behaviour, startup sequencing and fault isolation.

The recorded main-supply measurements show approximately ±34.5 V idle rails with only a few percent sag at the documented 8 W operating point. Quiescent-current measurements are closely matched when cold and rise after warm-up to approximately 79.6 mA and 84.4 mA. Normal output DC offsets remained in the tens of millivolts.

The measured 20 Hz–20 kHz sweep was flat at 22.6 Vpp output for 1.2 Vpp input, corresponding to 25.50 dB gain under that measurement condition. The upper −3 dB point was approximately 250 kHz. A separate 8 W loaded test at 1.2 Vpp input produced 27.2 Vpp left and 26.6 Vpp right, corresponding to calculated powers of approximately 11.56W and 11.06W at that specific operating point.

The protection-controller ADC, relay-driver, relay-coil and NTC readings were all consistent with normal operation, and the remaining protection tests were recorded as passed. These results verify the functional operation of the assembled amplifier and protection system within the scope of the measurements that were actually captured.

No maximum-power, distortion or noise specification is invented in this final report. The documented measurements are the complete final measurement set available for this build.

# Appendix A

# Instrumentation Record

The principal instruments used to obtain the final results were:

- UNI-T UPO1202 digital oscilloscope, used for waveform, amplitude, frequency-response and ripple observation;
- OWON DGE1030 signal generator, used as the sine-wave source;
- OWON XDM2041 digital multimeter, used for DC rails, bias, offset and protection-controller voltage measurements.

These model numbers are included so that the measurement environment can be reproduced or compared against future verification work.

# Appendix B

# Design Source Files

The final project source set associated with this report includes KiCad design files for the power amplifier, power supply and related system boards. The design authority for component connections and PCB implementation remains the KiCad project files, while this report documents system operation and the final available verification data.

Relevant supplied source filenames include:

- power_amplifier.kicad_sch;
- Power Amplifier Rod Elliot Project 3A.kicad_pcb;
- Power Amplifier Rod Elliot Project 3A.kicad_sch;
- power_supply.kicad_sch.

# Appendix C

# Original Measurement Log (Transcribed)

This appendix provides a readable transcription of the values supplied in the original three-page measurement sheet. Units, channel assignments, and test conditions are preserved; the derived and corrected values are discussed in Chapter 7. The original worksheet is supplied separately in the source package, not embedded as an image.

## C.1 Transformer and Supply Measurements

Table C.1: Recorded transformer and supply voltages.

Measurement | Left | Right
Transformer AC1 to centre tap (V RMS) | 25.652 | 25.628
Transformer AC2 to centre tap (V RMS) | 25.631 | 25.516
Positive rail at idle (V DC) | 34.521 | 34.566
Negative rail at idle (V DC) | -34.532 -34.522
Positive rail, 8-ohm load (V DC) | 33.534 | 33.678
Negative rail, 8-ohm load (V DC) | -33.560 -33.701
Positive rail ripple, 8-ohm load (V, recorded) | 1.5 | 1.4
Negative rail ripple, 8-ohm load (V, recorded) | 1.6 | 1.4

## C.2 Bias and DC Offset Log

Table C.2: Original bias and DC observations.

Measurement | Left | Right
R13 + R14 cold (mV) | 41.700 | 41.730
R13 + R14 warm/stabilised (mV) | 52.55 | 55.71
Initial DC offset (mV) | -54.54 -28.203
Output with no signal input (mV) | 42.300 -23.764
C.3 | Frequency Response and Loaded Test Log

The source log specifies an input of 1.2 Vpp and the following eight frequency points, at each of which both outputs were reported as 22.6 Vpp: 20, 50, 100, 500, 1000, 5000, 10000, and 20 000 Hz. It reports an upper −3 dB point of 250 kHz and notes that the protection system interprets input frequencies below about 15 Hz as DC.

With an 8 W load and a recorded 1.2 Vpp input, the log states 27.2 Vpp (left) and 26.6 Vpp (right). The original recorded gain entries were 27.11 dB and 27.23 dB, respectively. The right-channel gain is recomputed in the main text from the recorded input/output voltages; the original entry is preserved here as written.

## C.4 Protection-Controller Log

Table C.3: Original controller voltage entries.

Measurement | Left | Right
Healthy DC-sense ADC input (V) | 1.6014 1.5969
Relay-driver base, relay ON (V) | 3.2932 3.2931
Relay coil, relay ON (V) | 11.723 11.735
NTC channel voltage at room temperature (V) 1.1230 1.1225

The original sheet states: “ALL OTHER PROTECTION SYSTEM TEST ARE PASSED.” No individual measurements, event timestamps, or waveforms were supplied for those additional tests. This summary is therefore retained as an operator-reported result rather than independently quantified evidence.

# Bibliography

[1] Rod Elliott, Project 3A - 60-100 W Power Amplifier, Elliott Sound Products.
[2] STMicroelectronics, STM32G031K8 Datasheet and Reference Documentation.
[3] onsemi, MJL21193G PNP Audio Power Transistor Datasheet.
[4] onsemi, MJL21194G NPN Audio Power Transistor Datasheet.

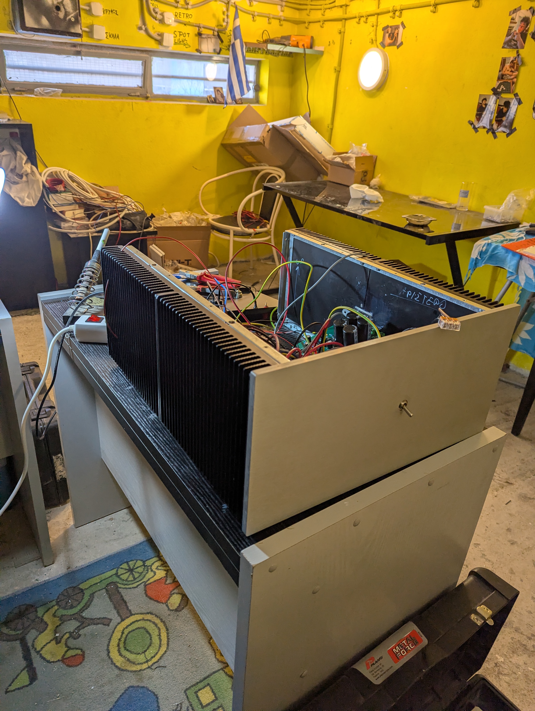
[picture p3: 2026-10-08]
Images/PXL_20261008_083112835.MP.jpg

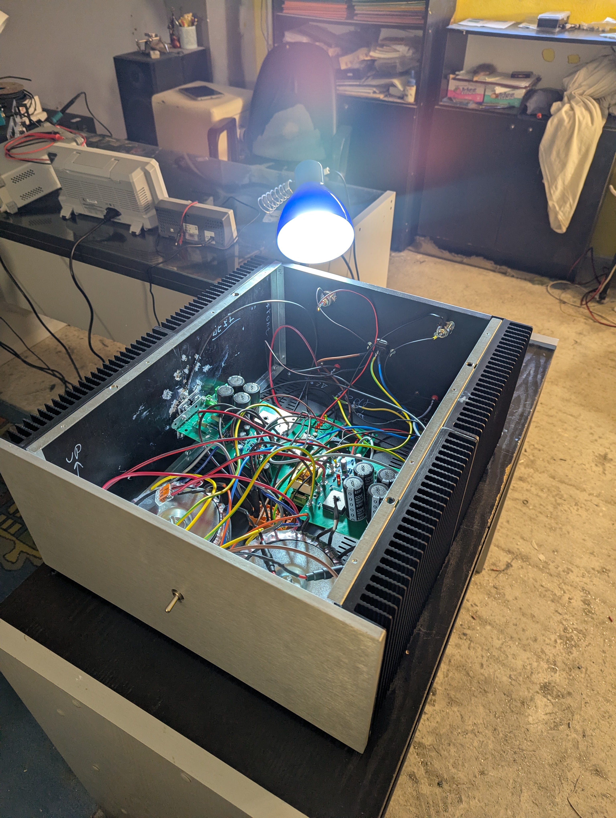
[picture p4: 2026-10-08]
Images/PXL_20261008_091902993.MP.jpg

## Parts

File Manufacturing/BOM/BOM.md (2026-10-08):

# Power Amplifier Bill of Materials

This BOM is generated from the KiCad **power amplifier** and **power supply** schematics. It represents one complete channel board, with an additional quantity column for a stereo build using two identical boards.

## Scope

- Included: `power_amplifier.kicad_sch` and `power_supply.kicad_sch`.
- Cross-checked against: `Power Amplifier Rod Elliot Project 3A.kicad_pcb`.
- Excluded: preamplifier, STM32 protection controller, chassis hardware, transformers, heatsinks, external RCA/speaker terminals, and cabling.
- Power/ground symbols and KiCad power flags are excluded from the BOM.

## BOM

| Category | Description | Value / Part | Qty / Channel | Qty Stereo | References / Board | Footprint | Notes |
|---|---|---:|---:|---:|---|---|---|
| Resistor | Through-hole resistor | 0R33 | 2 | 4 | R13, R14 | `Resistor_THT:R_Axial_Power_L25.0mm_W9.0mm_P30.48mm` |  |
| Resistor | Through-hole resistor | 10 | 1 | 2 | R15 | `Resistor_THT:R_Axial_DIN0516_L15.5mm_D5.0mm_P20.32mm_Horizontal` |  |
| Resistor | Through-hole resistor | 1K | 4 | 8 | R1, R3, R4, R16 | `Resistor_THT:R_Axial_DIN0207_L6.3mm_D2.5mm_P10.16mm_Horizontal` |  |
| Resistor | Through-hole resistor | 220 | 1 | 2 | R12 | `Resistor_THT:R_Axial_DIN0207_L6.3mm_D2.5mm_P10.16mm_Horizontal` |  |
| Resistor | Through-hole resistor | 22K | 3 | 6 | R2, R5, R8 | `Resistor_THT:R_Axial_DIN0207_L6.3mm_D2.5mm_P10.16mm_Horizontal` |  |
| Resistor | Through-hole resistor | 3K3 | 3 | 6 | R9, R10, R11 | `Resistor_THT:R_Axial_DIN0207_L6.3mm_D2.5mm_P10.16mm_Horizontal` |  |
| Resistor | Through-hole resistor | 560 | 2 | 4 | R6, R7 | `Resistor_THT:R_Axial_DIN0207_L6.3mm_D2.5mm_P10.16mm_Horizontal` |  |
| Capacitor | Through-hole capacitor | 100n | 5 | 10 | C7, C8, C12, C13, C18 | `Capacitor_THT:C_Disc_D5.0mm_W2.5mm_P2.50mm` |  |
| Capacitor | Through-hole capacitor | 100p | 3 | 6 | C2, C4, C6 | `Capacitor_THT:C_Disc_D5.0mm_W2.5mm_P2.50mm` |  |
| Capacitor | Polarized electrolytic capacitor | 100u | 4 | 8 | C3, C5, C10, C11 | `Capacitor_THT:CP_Radial_D13.0mm_P5.00mm` | Capacitor voltage rating is not specified in the schematic. |
| Capacitor | Polarized electrolytic capacitor | 4.7u | 1 | 2 | C1 | `Capacitor_THT:CP_Radial_D10.0mm_P3.50mm` | Capacitor voltage rating is not specified in the schematic. |
| Capacitor | Polarized electrolytic capacitor | 4700u | 4 | 8 | C14, C15, C16, C17 | `Capacitor_THT:CP_Radial_D25.0mm_P10.00mm_SnapIn` | Current power-supply schematic value is 4700 µF; voltage rating is not specified in the source. |
| Trimmer | 2 kΩ vertical trimmer potentiometer | 2K | 1 | 2 | VR1 | `Potentiometer_THT:Potentiometer_Runtron_RM-065_Vertical` |  |
| Transistor | Small-signal BJT | BC546 | 4 | 8 | Q1, Q2, Q3, Q9 | `Package_TO_SOT_THT:TO-92_Inline` |  |
| Transistor | Driver / bias-stage BJT | BD139 MJE15034 | 1 | 2 | Q5 | `Package_TO_SOT_THT:TO-126-3_Vertical` | KiCad value contains alternative transistor names; the assigned footprint is TO-126. Choose one device and verify its pinout/package before assembly. |
| Transistor | Driver / bias-stage BJT | BD140 MJE15035 | 2 | 4 | Q4, Q6 | `Package_TO_SOT_THT:TO-126-3_Vertical` | KiCad value contains alternative transistor names; the assigned footprint is TO-126. Choose one device and verify its pinout/package before assembly. |
| Transistor | Power output BJT | MJL21193G | 1 | 2 | Q7 | `Package_TO_SOT_THT:TO-264-3_Vertical` |  |
| Transistor | Power output BJT | MJL21194G | 1 | 2 | Q8 | `Package_TO_SOT_THT:TO-264-3_Vertical` |  |
| LED / Diode | 5 mm through-hole LED | LED | 1 | 2 | D1 | `LED_THT:LED_D5.0mm` | LED color is not specified in the schematic. |
| Bridge Rectifier | KBPC3506WP bridge rectifier | Diotec KBPC3506WP | 1 | 2 | BR1 | `Diode_THT:Diode_Bridge_28.6x28.6x7.3mm_P18.0mm_P11.6mm` |  |
| Fuse | 3 A fuse position with PCB 5×20 mm holder footprint | 3A | 2 | 4 | F1, F2 | `Fuse:Fuseholder_Cylinder-5x20mm_Stelvio-Kontek_PTF78_Horizontal_Open` | Fit a 3 A fuse in the 5×20 mm PCB fuse holder. |
| Wire Connection | PCB solder-wire connection | +35V | 2 | 4 | J3, J10 | `Connector_Wire:SolderWire-0.127sqmm_1x01_D0.48mm_OD1mm` | This is a solder-wire PCB connection, not a separate plug/socket component. |
| Wire Connection | PCB solder-wire connection | -35V | 2 | 4 | J4, J11 | `Connector_Wire:SolderWire-0.127sqmm_1x01_D0.48mm_OD1mm` | This is a solder-wire PCB connection, not a separate plug/socket component. |
| Wire Connection | PCB solder-wire connection | AUDIO IN | 1 | 2 | J1 | `Connector_Wire:SolderWire-6sqmm_1x01_D3.5mm_OD7mm` | This is a solder-wire PCB connection, not a separate plug/socket component. |
| Wire Connection | PCB solder-wire connection | COM | 1 | 2 | J7 | `Connector_Wire:SolderWire-6sqmm_1x01_D3.5mm_OD7mm` | This is a solder-wire PCB connection, not a separate plug/socket component. |
| Wire Connection | PCB solder-wire connection | GND | 2 | 4 | J2, Jw1 | `Connector_Wire:SolderWire-6sqmm_1x01_D3.5mm_OD7mm` | This is a solder-wire PCB connection, not a separate plug/socket component. |
| Wire Connection | PCB solder-wire connection | GND | 1 | 2 | J9 | `Connector_Wire:SolderWire-0.127sqmm_1x01_D0.48mm_OD1mm` | This is a solder-wire PCB connection, not a separate plug/socket component. |
| Wire Connection | PCB solder-wire connection | SPEAKER OUT | 1 | 2 | J5 | `Connector_Wire:SolderWire-6sqmm_1x01_D3.5mm_OD7mm` | This is a solder-wire PCB connection, not a separate plug/socket component. |
| Wire Connection | PCB solder-wire connection | V+ | 1 | 2 | J6 | `Connector_Wire:SolderWire-6sqmm_1x01_D3.5mm_OD7mm` | This is a solder-wire PCB connection, not a separate plug/socket component. |
| Wire Connection | PCB solder-wire connection | V- | 1 | 2 | J8 | `Connector_Wire:SolderWire-6sqmm_1x01_D3.5mm_OD7mm` | This is a solder-wire PCB connection, not a separate plug/socket component. |

## Validation Notes

- Schematic component count per channel board: **59** populated schematic items (excluding power symbols/flags).
- Stereo schematic count: **118** items before separating fuse inserts from holders or adding off-board hardware.
- PCB reference check: the PCB contains duplicate annotated reference(s): `J7`. The BOM follows the schematic quantity, not the duplicated PCB reference.
- The PCB also contains **4** unannotated `REF**` footprint(s); these are not included because they are not defined as schematic BOM items.
- `Q4/Q6` are labelled `BD140 MJE15035` and `Q5` is labelled `BD139 MJE15034` in KiCad. Those fields contain alternatives, while the assigned footprints are TO-126; verify the exact chosen transistor and pinout before ordering/assembly.
- Capacitor voltage ratings and most resistor power ratings are not encoded in the current schematics, so they are intentionally not invented in this BOM.
- `F1` and `F2` use PCB 5×20 mm fuse-holder footprints with a schematic value of 3 A; the physical build needs both the holders and appropriate 3 A fuse inserts.

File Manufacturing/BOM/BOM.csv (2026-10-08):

Section | Category | Description | Value / Part | Qty per channel board | Qty stereo (2 boards) | References per board | Footprint | Notes
Power Amplifier | Resistor | Through-hole resistor | 0R33 | 2 | 4 | R13, R14 | Resistor_THT:R_Axial_Power_L25.0mm_W9.0mm_P30.48mm
Power Amplifier | Resistor | Through-hole resistor | 10 | 1 | 2 | R15 | Resistor_THT:R_Axial_DIN0516_L15.5mm_D5.0mm_P20.32mm_Horizontal
Power Amplifier | Resistor | Through-hole resistor | 1K | 4 | 8 | R1, R3, R4, R16 | Resistor_THT:R_Axial_DIN0207_L6.3mm_D2.5mm_P10.16mm_Horizontal
Power Amplifier | Resistor | Through-hole resistor | 220 | 1 | 2 | R12 | Resistor_THT:R_Axial_DIN0207_L6.3mm_D2.5mm_P10.16mm_Horizontal
Power Amplifier | Resistor | Through-hole resistor | 22K | 3 | 6 | R2, R5, R8 | Resistor_THT:R_Axial_DIN0207_L6.3mm_D2.5mm_P10.16mm_Horizontal
Power Amplifier | Resistor | Through-hole resistor | 3K3 | 3 | 6 | R9, R10, R11 | Resistor_THT:R_Axial_DIN0207_L6.3mm_D2.5mm_P10.16mm_Horizontal
Power Amplifier | Resistor | Through-hole resistor | 560 | 2 | 4 | R6, R7 | Resistor_THT:R_Axial_DIN0207_L6.3mm_D2.5mm_P10.16mm_Horizontal
Power Amplifier + Power Supply | Capacitor | Through-hole capacitor | 100n | 5 | 10 | C7, C8, C12, C13, C18 | Capacitor_THT:C_Disc_D5.0mm_W2.5mm_P2.50mm
Power Amplifier | Capacitor | Through-hole capacitor | 100p | 3 | 6 | C2, C4, C6 | Capacitor_THT:C_Disc_D5.0mm_W2.5mm_P2.50mm
Power Amplifier | Capacitor | Polarized electrolytic capacitor | 100u | 4 | 8 | C3, C5, C10, C11 | Capacitor_THT:CP_Radial_D13.0mm_P5.00mm | Capacitor voltage rating is not specified in the schematic.
Power Amplifier | Capacitor | Polarized electrolytic capacitor | 4.7u | 1 | 2 | C1 | Capacitor_THT:CP_Radial_D10.0mm_P3.50mm | Capacitor voltage rating is not specified in the schematic.
Power Supply | Capacitor | Polarized electrolytic capacitor | 4700u | 4 | 8 | C14, C15, C16, C17 | Capacitor_THT:CP_Radial_D25.0mm_P10.00mm_SnapIn | Current power-supply schematic value is 4700 µF; voltage rating is not specified in the source.
Power Amplifier | Trimmer | 2 kΩ vertical trimmer potentiometer | 2K | 1 | 2 | VR1 | Potentiometer_THT:Potentiometer_Runtron_RM-065_Vertical
Power Amplifier | Transistor | Small-signal BJT | BC546 | 4 | 8 | Q1, Q2, Q3, Q9 | Package_TO_SOT_THT:TO-92_Inline
Power Amplifier | Transistor | Driver / bias-stage BJT | BD139 MJE15034 | 1 | 2 | Q5 | Package_TO_SOT_THT:TO-126-3_Vertical | KiCad value contains alternative transistor names; the assigned footprint is TO-126. Choose one device and verify its pinout/package before assembly.
Power Amplifier | Transistor | Driver / bias-stage BJT | BD140 MJE15035 | 2 | 4 | Q4, Q6 | Package_TO_SOT_THT:TO-126-3_Vertical | KiCad value contains alternative transistor names; the assigned footprint is TO-126. Choose one device and verify its pinout/package before assembly.
Power Amplifier | Transistor | Power output BJT | MJL21193G | 1 | 2 | Q7 | Package_TO_SOT_THT:TO-264-3_Vertical
Power Amplifier | Transistor | Power output BJT | MJL21194G | 1 | 2 | Q8 | Package_TO_SOT_THT:TO-264-3_Vertical
Power Amplifier | LED / Diode | 5 mm through-hole LED | LED | 1 | 2 | D1 | LED_THT:LED_D5.0mm | LED color is not specified in the schematic.
Power Supply | Bridge Rectifier | KBPC3506WP bridge rectifier | Diotec KBPC3506WP | 1 | 2 | BR1 | Diode_THT:Diode_Bridge_28.6x28.6x7.3mm_P18.0mm_P11.6mm
Power Amplifier | Fuse | 3 A fuse position with PCB 5×20 mm holder footprint | 3A | 2 | 4 | F1, F2 | Fuse:Fuseholder_Cylinder-5x20mm_Stelvio-Kontek_PTF78_Horizontal_Open | Fit a 3 A fuse in the 5×20 mm PCB fuse holder.
Power Amplifier + Power Supply | Wire Connection | PCB solder-wire connection | +35V | 2 | 4 | J3, J10 | Connector_Wire:SolderWire-0.127sqmm_1x01_D0.48mm_OD1mm | This is a solder-wire PCB connection, not a separate plug/socket component.
Power Amplifier + Power Supply | Wire Connection | PCB solder-wire connection | -35V | 2 | 4 | J4, J11 | Connector_Wire:SolderWire-0.127sqmm_1x01_D0.48mm_OD1mm | This is a solder-wire PCB connection, not a separate plug/socket component.
Power Amplifier | Wire Connection | PCB solder-wire connection | AUDIO IN | 1 | 2 | J1 | Connector_Wire:SolderWire-6sqmm_1x01_D3.5mm_OD7mm | This is a solder-wire PCB connection, not a separate plug/socket component.
Power Supply | Wire Connection | PCB solder-wire connection | COM | 1 | 2 | J7 | Connector_Wire:SolderWire-6sqmm_1x01_D3.5mm_OD7mm | This is a solder-wire PCB connection, not a separate plug/socket component.
Power Amplifier | Wire Connection | PCB solder-wire connection | GND | 2 | 4 | J2, Jw1 | Connector_Wire:SolderWire-6sqmm_1x01_D3.5mm_OD7mm | This is a solder-wire PCB connection, not a separate plug/socket component.
Power Supply | Wire Connection | PCB solder-wire connection | GND | 1 | 2 | J9 | Connector_Wire:SolderWire-0.127sqmm_1x01_D0.48mm_OD1mm | This is a solder-wire PCB connection, not a separate plug/socket component.
Power Amplifier | Wire Connection | PCB solder-wire connection | SPEAKER OUT | 1 | 2 | J5 | Connector_Wire:SolderWire-6sqmm_1x01_D3.5mm_OD7mm | This is a solder-wire PCB connection, not a separate plug/socket component.
Power Supply | Wire Connection | PCB solder-wire connection | V+ | 1 | 2 | J6 | Connector_Wire:SolderWire-6sqmm_1x01_D3.5mm_OD7mm | This is a solder-wire PCB connection, not a separate plug/socket component.
Power Supply | Wire Connection | PCB solder-wire connection | V- | 1 | 2 | J8 | Connector_Wire:SolderWire-6sqmm_1x01_D3.5mm_OD7mm | This is a solder-wire PCB connection, not a separate plug/socket component.

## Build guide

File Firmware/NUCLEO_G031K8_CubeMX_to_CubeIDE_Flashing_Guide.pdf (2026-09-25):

# STM32 NUCLEO-G031K8 Protection Controller

# From Standalone STM32CubeMX Configuration to STM32CubeIDE Build and Flash

### Exact project workflow for protection_controller

Target: NUCLEO-G031K8 / STM32G031K8T6 Power Amplifier Speaker Protection Controller
25 September 2026

### PHASE A - STM32CubeMX

Select the MCU, assign pins, configure ADC/GPIO, set the 64 MHz clock, choose STM32CubeIDE as the generator, then generate the project.

### PHASE B - STM32CubeIDE

Open the generated project, add the protection firmware, build it, then flash the Nucleo through the onboard ST-LINK USB interface.

NUCLEO-G031K8 Protection Controller - CubeMX to CubeIDE

Power Amplifier Project | Page 2

# 1. What we actually did

The important point is that we did not begin by writing firmware inside STM32CubeIDE. We first built the microcontroller hardware configuration in the standalone STM32CubeMX application and saved it as protection_controller.ioc. CubeMX defined the pins, ADC, GPIO behaviour, clocks, generated HAL initialization code, and created an STM32CubeIDE-compatible project. Only after that generation step did we move to CubeIDE to add the protection logic, compile, debug, and program the board.

Core principle: The .ioc file is the hardware configuration source of truth. If a pin or peripheral configuration must change, change it in CubeMX and regenerate; do not manually fight the generated initialization code in CubeIDE.

## 1.1 Final target

Item | Final project value
Development board | ST NUCLEO-G031K8
Microcontroller | STM32G031K8T6 (CubeMX project header may show STM32G031K8Tx)
CubeMX project name | protection_controller
Project location | C:\STProjects
Generated toolchain | STM32CubeIDE
Firmware package shown in saved project | STM32Cube_FW_G0 V1.6.3
CPU clock | 64 MHz
Programming interface | Onboard ST-LINK over USB, SWD
Flash image | Debug/protection_controller.elf

## 1.2 End-to-end workflow

1. Open standalone STM32CubeMX and create a new MCU project for STM32G031K8T6 / STM32G031K8Tx.
2. Configure the four ADC inputs, two buttons, two relay outputs, and status LED outputs.
3. Configure the system clock to 64 MHz using HSI16 and the PLL.
4. In Project Manager, select STM32CubeIDE as the toolchain and generate code.
5. Open the generated protection_controller project in STM32CubeIDE.
6. Add the custom protection .c and .h modules and connect them to main.c inside USER CODE regions.
7. Build the project and confirm a clean compile.
8. Connect the NUCLEO-G031K8 by USB to the onboard ST-LINK, then Run/Debug the STM32 C/C++ application.
9. Confirm that programming and verification succeed, then reset/power-cycle to run the firmware from internal Flash.

# 2. Phase A - Configure the MCU in standalone STM32CubeMX

This section reproduces the part that happened before CubeIDE. This is the step that turns a blank STM32 target into a generated project with the correct clocks, ADC channels, GPIO directions, pull resistors, startup states, and HAL initialization code.

## 2.1 Start a new MCU project - use the MCU selector

1. Launch STM32CubeMX as a standalone application.
2. Choose New Project, then MCU/MPU Selector.
3. Search for STM32G031K8T6. CubeMX may identify the project device generically as STM32G031K8Tx; this matches the saved protection_controller.ioc shown in the screenshots.
4. Create the project. Do not start by writing a bare main.c in CubeIDE; the purpose of CubeMX is to create the hardware initialization first.
5. Save the project as protection_controller.ioc.

## 2.2 Pinout & Configuration page

The saved project screenshots show the standalone CubeMX Pinout & Configuration workspace. GPIO and ADC1 are the important peripherals for this controller. We did not need an RTOS, networking stack, USB middleware, or other middleware package for the protection logic.

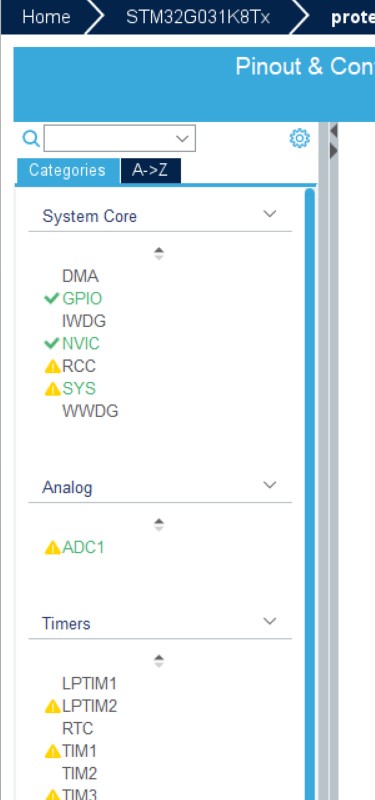
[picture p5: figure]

GPIO and ADC1 are the relevant hardware categories.

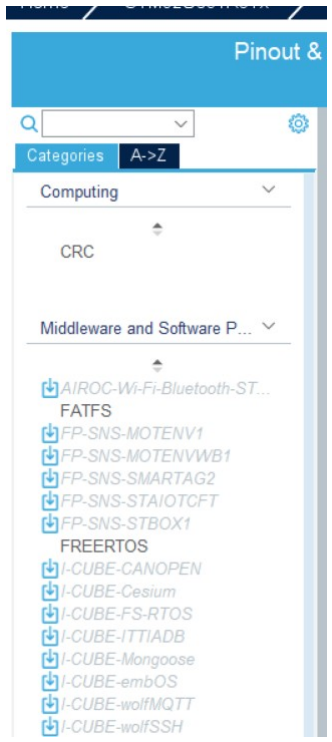
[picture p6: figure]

No middleware or RTOS is required for this project.

## 2.3 Final pin assignment

The following mapping is the final configuration we settled on. It includes the later corrections: the right relay is on PA9, PB9 is the TEMP2 failure LED, and PA15/D2 is intentionally not used.

MCU pin | CubeMX function | Project signal | Direction / startup
PA0 | ADC1_IN0 | TEMP1 | Analog input
PA1 | ADC1_IN1 | TEMP2 | Analog input
PA4 | ADC1_IN4 | DC_LEFT | Analog input
PA5 | ADC1_IN5 | DC_RIGHT | Analog input
PA8 | GPIO_Output | RELAY_L_CTRL | Output, initial LOW
PA9 | GPIO_Output | RELAY_R_CTRL | Output, initial LOW
PB8 | GPIO_Output | TEMP1_FAIL_LED | Output, initial LOW
PB9 | GPIO_Output | TEMP2_FAIL_LED | Output, initial LOW
PA11 | GPIO_Output | DC_FAULT_LED | Output, initial LOW
PA12 | GPIO_Output | WAIT_LED | Output, initial LOW
PB4 | GPIO_Output | OVERHEAT_LED | Output, initial LOW
PB0 | GPIO_Input | MUTE_ENABLE / ENABLE_MUTE | Input with pull-up; active LOW button
PB1 | GPIO_Input | FAULT_RESET | Input with pull-up; active LOW button
PA13 | SYS_SWDIO | ST-LINK debug | Reserved for SWD
PA14 | SYS_SWCLK | ST-LINK debug | Reserved for SWD
PA15 / D2 | Unused | Do not use | Nucleo D2 pin has the board jumper-to-GND consideration

Fail-safe startup: The relay-control GPIOs were configured to start LOW. That keeps the loudspeaker relays de-energised while the MCU is resetting and before the protection firmware has decided that conditions are safe.

## 2.4 How to assign each GPIO in CubeMX

1. On the package drawing, click the required pin and choose the function (for example GPIO_Output, GPIO_Input, or ADC1_IN0).
2. For outputs, open System Core > GPIO and select the row for that pin. Set Output Level = Low, GPIO mode = Output Push Pull, and normally use No pull unless the external circuit requires otherwise.
3. For PB0 and PB1, choose GPIO_Input and set Pull-up. The buttons therefore read logic 1 normally and logic 0 when pressed to ground.
4. Assign a clear User Label. CubeMX uses these labels to generate pin macros in main.h. The labels should match the project signal names shown in the table.
5. Leave PA13/PA14 available for SWD by setting System Core > SYS > Debug = Serial Wire.
6. Do not assign PA15/D2 to the protection logic in this design.

## 2.5 ADC1 configuration

Four analogue inputs are required: two NTC temperature channels and two DC-sense channels. The final ADC setup was deliberately simple and software controlled rather than free-running.

ADC setting | Value used | Reason
Resolution | 12-bit | 0 to 4095 raw code range for sensor and DC measurements.

ADC setting | Value used | Reason
Data alignment | Right aligned | Natural integer ADC values for the firmware.
Channels | IN0, IN1, IN4, IN5 | TEMP1, TEMP2, DC_LEFT, DC_RIGHT.
Conversion trigger | Software start | Firmware decides when each measurement occurs.
Continuous conversion | Disabled | No uncontrolled free-running conversions.
DMA continuous requests | Disabled | Measurements are handled directly by the firmware.
Scan / sequence behaviour | Single software-controlled conversions | The firmware reads the required channels as part of its sampling routine.
Common sampling time 1 | 160.5 ADC clock cycles | Long sampling period chosen for the divider/NTC sensing networks.
Common sampling time 2 | 160.5 ADC clock cycles | Same conservative sampling time for the other channel group.
ADC clock | SYSCLK source shown as 64 MHz; synchronous /2 in ADC setup | Effective ADC conversion clock about 32 MHz in the final setup.

Important: If the .ioc file is reopened later, the ADC and GPIO settings should be changed there and the project regenerated. Generated functions such as MX_ADC1_Init() and MX_GPIO_Init() should remain CubeMX-owned.

# 3. Clock configuration in CubeMX

The protection controller does not need an external crystal for its main CPU clock. We used the STM32 internal 16 MHz HSI oscillator and the PLL to generate a 64 MHz system clock.

## 3.1 Exact clock path

Clock stage | Setting | Result
HSI RC | 16 MHz internal oscillator | 16 MHz
PLL source | HSI | 16 MHz into PLL
PLL M | /1 | 16 MHz
PLL N | x8 | 128 MHz VCO-related stage
PLL R | /2 | 64 MHz PLL clock
System Clock Mux | PLLCLK | SYSCLK = 64 MHz
AHB prescaler | /1 | HCLK = 64 MHz
APB prescaler | /1 | PCLK = 64 MHz
Cortex / SysTick / FCLK | Derived from 64 MHz HCLK | 64 MHz
ADC kernel source | SYSCLK | 64 MHz shown on clock tree; ADC divider applied in ADC configuration

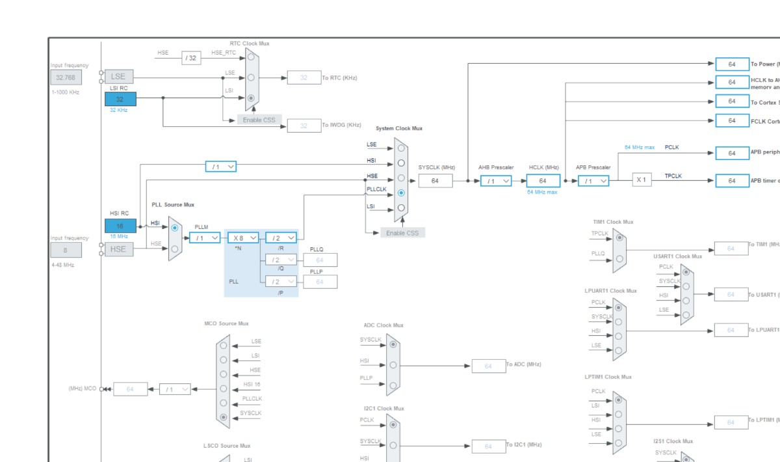
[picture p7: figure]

Figure 1 - Saved STM32CubeMX clock tree for protection_controller. HSI16 feeds the PLL and the system runs at 64 MHz.

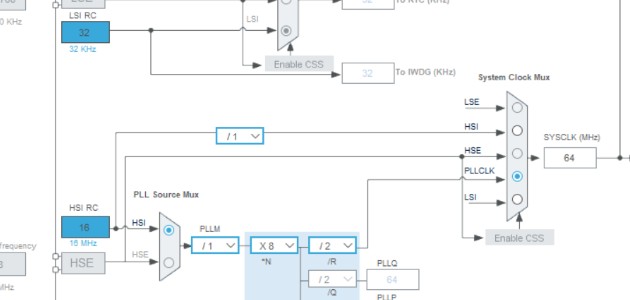
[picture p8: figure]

Figure 2 - PLL detail: HSI /1, x8, /2, with PLLCLK selected as SYSCLK.

## 3.2 What to verify before leaving Clock Configuration

- SYSCLK must read 64 MHz.
- HCLK must read 64 MHz.
- APB peripheral clock must read 64 MHz.
- The system clock source selector must be on PLLCLK.
- There should be no unresolved red clock error in the clock tree.
- Do not change the CPU frequency later in CubeIDE without updating timing-dependent assumptions; regenerate through CubeMX instead.

# 4. Project Manager - the step that hands the project to CubeIDE

This is the key bridge between the two applications. We configured everything in CubeMX first, then told CubeMX to generate an STM32CubeIDE project. The screenshot below is from the saved protection_controller.ioc and confirms the project-generation settings.

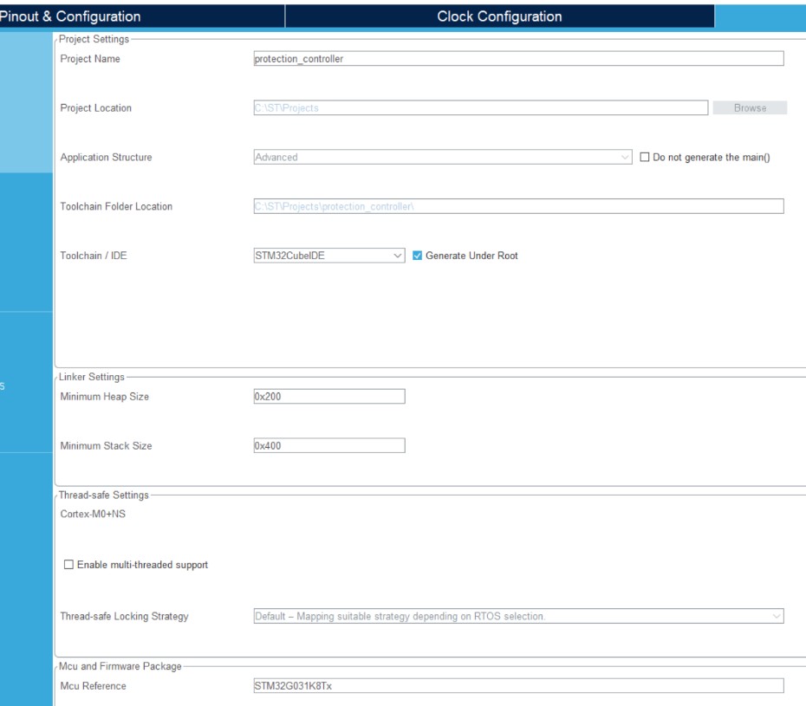
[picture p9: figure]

Figure 3 - Project Manager settings from the saved standalone CubeMX project.

## 4.1 Exact Project Manager values shown in the saved project

Field | Value
Project Name | protection_controller
Project Location | C:\STProjects
Application Structure | Advanced
Do not generate the main() | Not checked - CubeMX generates main.c
Toolchain Folder Location | C:\STProjects\protection_controller\
Toolchain / IDE | STM32CubeIDE
Generate Under Root | Checked
Minimum Heap Size | 0x200
Minimum Stack Size | 0x400

Field | Value
MCU Reference | STM32G031K8Tx
Firmware Package | STM32Cube_FW_G0 V1.6.3 in the saved screenshot
Use latest available version | Checked in the saved project
Default firmware location | Enabled

## 4.2 Generate the CubeIDE project

1. Save the .ioc file.
2. Click GENERATE CODE in the upper-right corner of STM32CubeMX.
3. CubeMX creates the project folder C:\STProjects\protection_controller\ together with Core, Drivers, the .ioc file, startup files, linker script, and CubeIDE project metadata.
4. When generation finishes, open the generated project in STM32CubeIDE. At this point the generated project already knows the MCU, HAL package, pin setup, ADC setup, and clock setup.
5. Keep protection_controller.ioc in the project. It is the file to reopen when hardware configuration changes are needed.

Why this matters: CubeIDE did not invent the pinout or clocks. CubeMX generated those parts first. CubeIDE was then used as the C/C++ editor, compiler, debugger, and flashing front end.

# 5. Phase B - Open the generated project in STM32CubeIDE

## 5.1 Generated project structure

After code generation, the STM32CubeIDE project contained the standard STM32 HAL structure. We then added the protection-controller modules into the generated Core folders.

protection_controller/
+-- protection_controller.ioc
+-- Core/
| | +-- Inc/
| | | | +-- main.h | [generated by CubeMX]
| | | | +-- protection.h | [our code]
| | | | +-- protection_config.h | [our code]
| | | | +-- protection_io.h | [our code]
| | | | +-- protection_pins.h | [our code]
| | | | +-- sensors.h | [our code]
| | +-- Src/
| | | +-- main.c | [generated + USER CODE calls]
| | | +-- protection.c | [our code]
| | | +-- protection_io.c | [our code]
| | | +-- sensors.c | [our code]
+-- Drivers/
| | +-- CMSIS/
| | +-- STM32G0xx_HAL_Driver/
+-- Debug/ | [created when building]
+-- protection_controller.elf

## 5.2 What each custom file does

File | Purpose
protection_config.h | Timing constants, ADC thresholds, temperature trip/reset values, averaging and debounce constants.
protection_pins.h | Project-level logical pin mapping/helpers used by the protection modules.
sensors.c / sensors.h | ADC acquisition, sensor validation, temperature/DC measurement handling.
protection_io.c / .h | Relay outputs, LED outputs, button input handling.
protection.c / protection.h | Main protection state machine: startup delay, fault latch, DC persistence, thermal checks, reset rules, mute/enable behaviour.
main.c | Generated application entry point. It initializes HAL/clock/GPIO/ADC, then calls our protection module.

## 5.3 Preserve CubeMX USER CODE sections

The generated main.c can be regenerated later. Therefore our additions must go inside CubeMX USER CODE regions so they survive regeneration.

/* USER CODE BEGIN Includes */ #include "protection.h"
/* USER CODE END Includes */

int main(void)
{
HAL_Init();

SystemClock_Config();

MX_GPIO_Init();
MX_ADC1_Init();

/* USER CODE BEGIN 2 */
Protection_Init();
/* USER CODE END 2 */

/* USER CODE BEGIN WHILE */ while (1)
{
/* USER CODE END WHILE */

/* USER CODE BEGIN 3 */
Protection_Task();
HAL_Delay(5);
}
/* USER CODE END 3 */
}

Do not move hardware initialization into our modules: SystemClock_Config(), MX_GPIO_Init(), and MX_ADC1_Init() are generated from the .ioc file. Our application code starts after those functions have configured the MCU.

## 5.4 Important protection constants used in the project

Constant | Value | Meaning
STARTUP_DELAY_MS | 3000 ms | Relays remain disconnected for 3 seconds after startup.
SAMPLE_INTERVAL_MS | 10 ms | Protection measurements are processed periodically.
BUTTON_DEBOUNCE_MS | 30 ms | Debounce interval for front-panel buttons.
ADC_AVERAGE_SAMPLES | 8 | ADC readings are averaged to reduce noise.
TEMP_TRIP_ADC | 261U | Approximate overtemperature trip point (~100 degC in the project calibration).
TEMP_RESET_ADC | 342U | Approximate reset-allowed temperature (~90 degC), providing hysteresis.

## 5.5 Build the firmware

1. In Project Explorer, select protection_controller.
2. Use Project > Build Project, Ctrl+B, or the hammer/build icon.
3. Watch the Console and Problems views. Resolve all compile/link errors before connecting the amplifier hardware.
4. A successful Debug build creates Debug/protection_controller.elf. This ELF file contains the program that CubeIDE sends to the MCU.

# 6. Phase C - Flash the NUCLEO-G031K8 through onboard ST-LINK

## 6.1 Hardware connection for the first programming test

The NUCLEO-G031K8 contains its own ST-LINK programmer/debugger. No external ST-LINK probe and no separate USB-to-serial adapter are required.
1. Leave the Nucleo disconnected from the protection PCB for the first flash if desired. It is safe to program the complete Nucleo development board with its I/O pins otherwise unconnected.
2. Connect a USB data cable from the PC to the Nucleo onboard ST-LINK USB connector.
3. The USB connection powers the Nucleo logic and provides the SWD programming/debug connection.
4. You do not need to hold BOOT0 or connect external programming wires for this normal ST-LINK/SWD method.
5. PA13 and PA14 must remain available as SWDIO and SWCLK. This is why SYS > Debug = Serial Wire is important in CubeMX.

Board-specific caution: PA15 corresponds to the Nucleo D2 position in this project context and was deliberately left unused because of the D2-to-GND jumper arrangement. Do not assign it to a protection output without first changing/understanding the board jumper configuration.

## 6.2 Start the flash from CubeIDE

1. Build the project first so Debug/protection_controller.elf is up to date.
2. With the Nucleo connected by USB, choose Run > Run As > STM32 C/C++ Application. Debug > Debug As > STM32 C/C++ Application can also be used when breakpoints/variable inspection are required.
3. CubeIDE launches the ST-LINK GDB server and STM32CubeProgrammer components automatically.
4. The connection uses SWD. In the successful session the SWD frequency was 4000 kHz and the board target voltage reported about 3.25 V.
5. CubeIDE erases/programs the required internal Flash sectors, writes the ELF image to the STM32 internal Flash at the normal application base around 0x08000000, and performs verification.
6. After verification, the MCU resets and begins executing the protection firmware.

## 6.3 What the successful programming session looked like

ST-LINK GDB server
Board | : NUCLEO-G031K8
Target | : STM32G03x / STM32G04x family
Target VDD : about 3.25 V
Interface | : SWD
SWD freq | : 4000 kHz

STM32CubeProgrammer
Flash | : 64 KB
Application : protection_controller.elf
Base | : 0x08000000
Result | : Download / programming verified successfully

## 6.4 After flashing

- The program is stored in the STM32 internal Flash; it remains there after the USB cable is removed.
- Pressing reset or powering the board again starts the flashed firmware automatically.
- The board does not need to remain attached to CubeIDE to operate.
- For standalone amplifier operation, install the programmed Nucleo on the protection PCB and power it using the intended board power arrangement.
- Before connecting valuable loudspeakers, verify ADC inputs, relay behaviour, fault LEDs, temperature sensing, and DC-fault handling with controlled tests.

# 7. What happens when the firmware starts

Once the MCU resets after programming, the generated HAL initialization executes first, followed by our protection state machine. The intended sequence is fail-safe: speakers begin disconnected and are only connected when the checks pass.
1. HAL and the 64 MHz system clock are initialized.
2. GPIOs are initialized. Relay control outputs begin LOW, so both speaker relays are OFF.
3. ADC1 is initialized for the temperature and DC-sense inputs.
4. Protection_Init() resets the protection state, timers, fault latches, and outputs.
5. The 3-second startup delay begins; WAIT indication is used while the speakers are intentionally disconnected.
6. Both temperature channels are checked for valid sensor readings. A missing/invalid sensor causes a fault and the relays remain OFF.
7. Left and right DC-sense inputs are monitored. A sustained dangerous DC condition raises a latched DC fault and disconnects the speakers.
8. Temperature is monitored continuously. Around the configured trip threshold (~100 degC), an overtemperature fault disconnects the relays. Reset is allowed only after cooling to around the reset threshold (~90 degC).
9. The ENABLE/MUTE button can intentionally control the connected state, while FAULT_RESET is accepted only when the monitored conditions are safe.

## 7.1 Fail-safe signal summary

Condition | Relay state | Indicator / action
Reset / MCU boot | OFF | Outputs start in safe LOW state.
Startup delay | OFF | WAIT indication active.
Normal, sensors valid, no DC, temperature safe | ON | Normal operation.
TEMP1 invalid | OFF | TEMP1_FAIL_LED; fault latched/handled.
TEMP2 invalid | OFF | TEMP2_FAIL_LED; fault latched/handled.
Dangerous left or right DC | OFF | DC_FAULT_LED; speakers isolated.
Overtemperature | OFF | OVERHEAT_LED; reset blocked until cooled.
Manual mute / disable | OFF | Relays intentionally de-energised.

# 8. Rebuild-from-zero checklist

Use this checklist if the project ever needs to be reconstructed on another PC or after deleting the generated project. It deliberately separates CubeMX work from CubeIDE work.

## A. CubeMX - before opening CubeIDE

☐ Create MCU project for STM32G031K8T6 / STM32G031K8Tx.
☐ Name it protection_controller and save the .ioc.
☐ Set SYS Debug = Serial Wire.
☐ Enable PA0=ADC1_IN0, PA1=ADC1_IN1, PA4=ADC1_IN4, PA5=ADC1_IN5.
☐ ADC: 12-bit, right aligned, software-triggered single conversions, continuous/DMA off, 160.5-cycle sampling.
☐ Outputs: PA8 relay L, PA9 relay R, PB8 TEMP1 fail, PB9 TEMP2 fail, PA11 DC fault, PA12 WAIT, PB4 overheat. ☐ Set all protection outputs to initial LOW; use push-pull outputs.
☐ Inputs: PB0 mute/enable and PB1 fault reset, both pull-up.
☐ Do not use PA15/D2.
☐ Clock: HSI16 -> PLL /1 x8 /2 -> SYSCLK 64 MHz; AHB /1, APB /1.
☐ Project Manager: Advanced structure, toolchain STM32CubeIDE, Generate Under Root checked, main() generated. ☐ Click GENERATE CODE.

## B. CubeIDE - after CubeMX has generated the project

☐ Open/import C:\STProjects\protection_controller\ in STM32CubeIDE. ☐ Add the custom headers under Core/Inc and sources under Core/Src.
☐ Include protection.h in main.c inside USER CODE Includes.
☐ Call Protection_Init() after MX_GPIO_Init() and MX_ADC1_Init().
☐ Call Protection_Task() repeatedly in the main loop with the 5 ms loop delay used in the project. ☐ Build and confirm Debug/protection_controller.elf is created.
☐ Connect NUCLEO-G031K8 to the PC by the onboard ST-LINK USB connector.
☐ Run as STM32 C/C++ Application (SWD).
☐ Confirm target detection, programming, and verification succeed.
☐ Reset/power-cycle and verify the firmware starts with both relays disconnected.

# 9. Troubleshooting

Symptom | Likely check / fix
CubeIDE cannot see the Nucleo | Use a USB data cable, reconnect the onboard ST-LINK USB connector, verify ST-LINK appears in the OS, then retry.
ST-LINK connects but cannot program | Make sure PA13/PA14 are not repurposed; set SYS Debug = Serial Wire in CubeMX and regenerate.
Firmware builds but wrong pins switch | Do not patch main.h manually. Open protection_controller.ioc, correct the CubeMX pin assignment/user labels, and regenerate.
Relay energises briefly during reset | Confirm relay GPIO initial output level is LOW in CubeMX and check the external transistor/relay driver polarity.
Buttons behave backwards | PB0/PB1 use pull-ups and are active LOW; pressed = 0.
ADC readings unstable | Verify the sensing-divider wiring/ground, 160.5-cycle sampling time, averaging, and the expected 0-3.3 V ADC range.
Temperature fault appears immediately | Check both NTC sensors and their 10 kOhm divider/pull-up networks; firmware intentionally treats invalid sensors as unsafe.
Flashing succeeds but code seems not to run | Press reset, ensure the correct Debug/protection_controller.elf was built, and check that execution did not remain halted at a debugger breakpoint.
Regeneration deletes hand edits | Keep application changes only in CubeMX USER CODE sections and in separate custom .c/.h files.
PA15/D2 does not behave as expected | Leave it unused for this design unless the Nucleo D2 jumper arrangement is intentionally changed and re-verified.

## 9.1 The most important recovery rule

If hardware configuration is wrong: Return to protection_controller.ioc in STM32CubeMX, fix the pin/peripheral/clock setting there, save, regenerate, rebuild in CubeIDE, and flash again. This keeps the generated HAL code consistent with the hardware design.

# Appendix A - Reference screenshots from the saved CubeMX project

These screenshots were supplied from the actual protection_controller.ioc project and are included as visual references for the standalone CubeMX configuration used before CubeIDE.

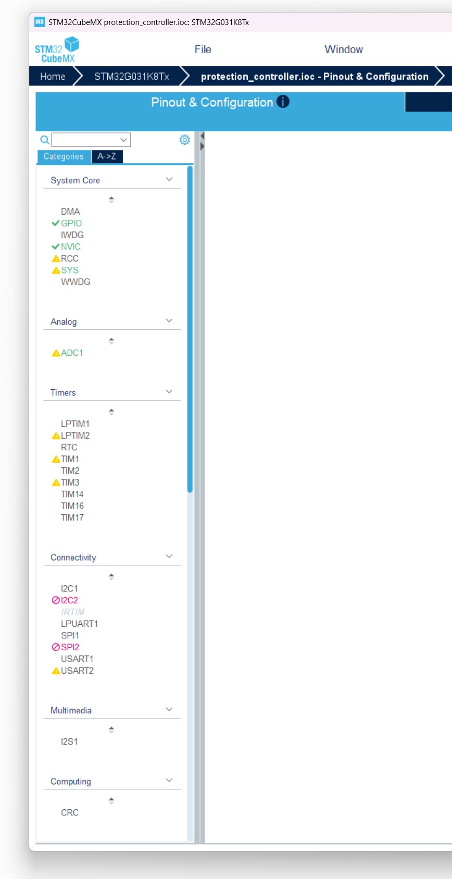
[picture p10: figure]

A1 - Pinout & Configuration categories; GPIO and ADC1 are present in the project.

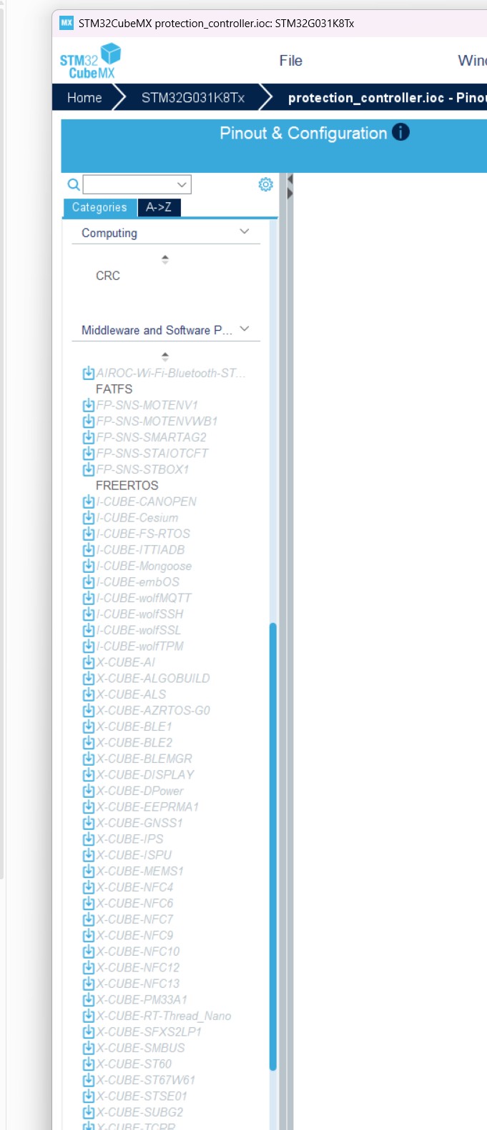
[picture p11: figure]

A2 - Middleware list. No RTOS or middleware package was required for the protection controller.

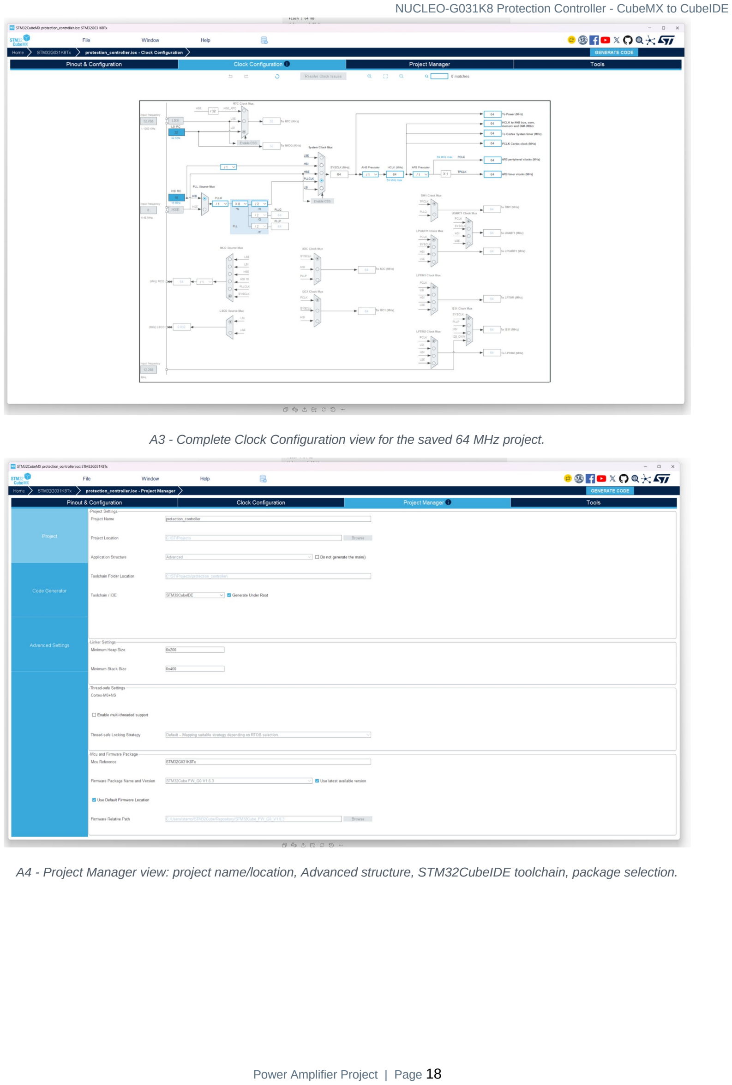
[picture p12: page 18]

A3 - Complete Clock Configuration view for the saved 64 MHz project.

A4 - Project Manager view: project name/location, Advanced structure, STM32CubeIDE toolchain, package selection.

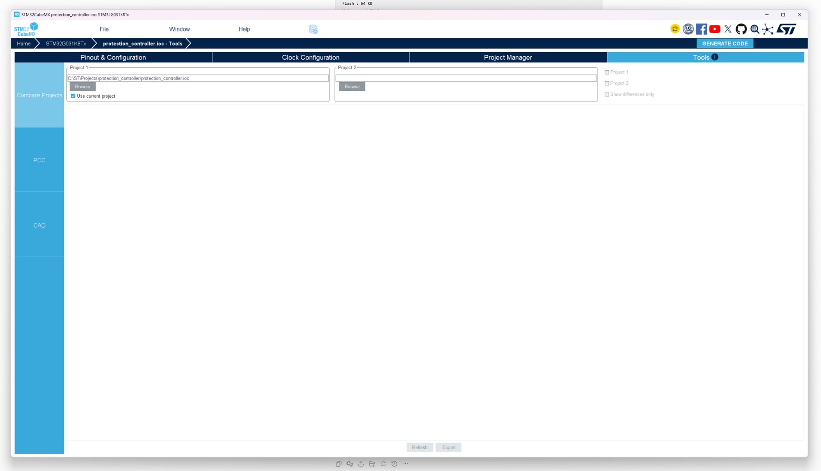
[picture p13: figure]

A5 - CubeMX Tools page showing the current protection_controller.ioc project path.

# Appendix B - One-page configuration cheat sheet

Category | Exact setting
Target | NUCLEO-G031K8 / STM32G031K8T6; CubeMX file target STM32G031K8Tx
ADC | PA0 IN0 TEMP1; PA1 IN1 TEMP2; PA4 IN4 DC_LEFT; PA5 IN5 DC_RIGHT; 12-bit; 160.5 cycles; software controlled
Relays | PA8 RELAY_L_CTRL; PA9 RELAY_R_CTRL; push-pull; initial LOW
LEDs | PB8 TEMP1_FAIL; PB9 TEMP2_FAIL; PA11 DC_FAULT; PA12 WAIT; PB4 OVERHEAT
Buttons | PB0 MUTE_ENABLE and PB1 FAULT_RESET; input pull-up; active LOW
Debug | SYS = Serial Wire; PA13 SWDIO; PA14 SWCLK
Avoid | PA15 / Nucleo D2 is unused in this design
Clock | HSI16 -> PLL /1 x8 /2 -> 64 MHz; AHB /1; APB /1
CubeMX project | protection_controller; C:\STProjects; Advanced; STM32CubeIDE; Generate Under Root
CubeIDE custom files | protection.*, protection_config.h, protection_io.*, protection_pins.h, sensors.*
main.c | MX_GPIO_Init(); MX_ADC1_Init(); then Protection_Init(); main loop Protection_Task(); HAL_Delay(5);
Build/flash | Build -> Debug/protection_controller.elf -> onboard ST-LINK USB -> SWD 4000 kHz -> program/verify -> reset

Remember: CubeMX defines the hardware. CubeIDE builds and flashes the generated project plus our application logic. Keeping that separation is what makes the project reproducible.

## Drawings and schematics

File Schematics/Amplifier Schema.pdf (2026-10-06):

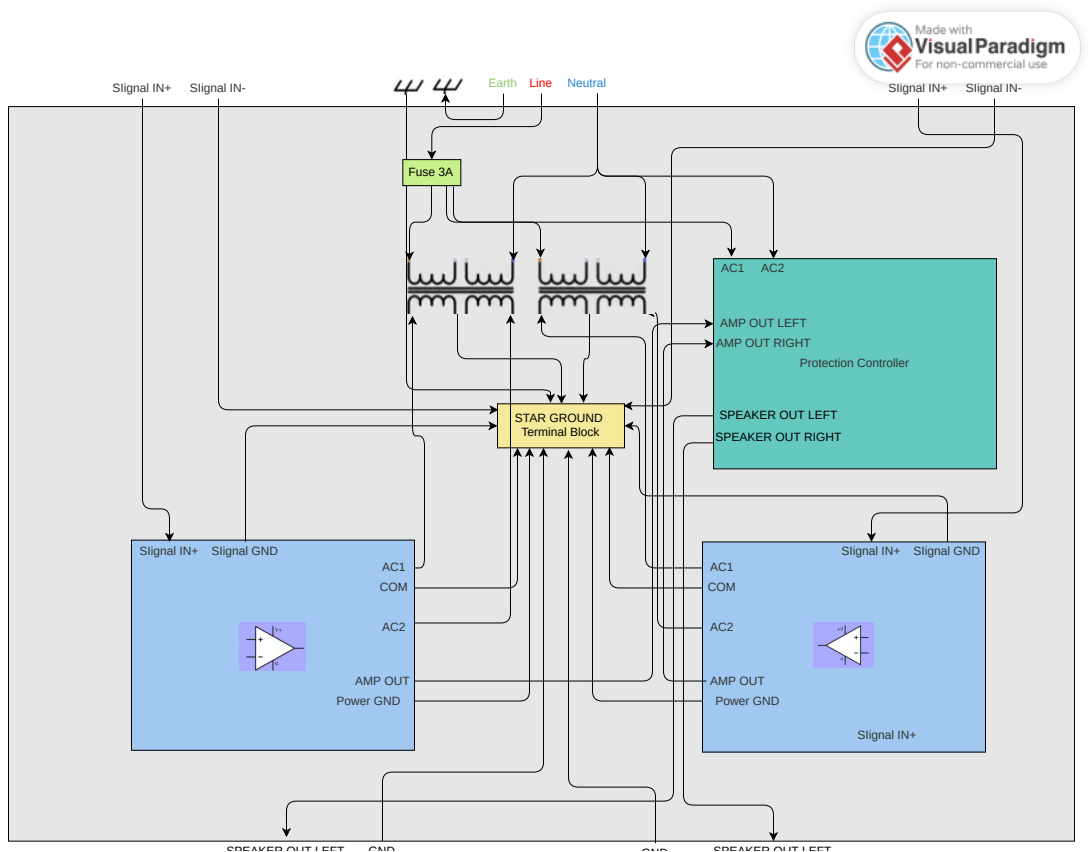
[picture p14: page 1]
Fuse 3A; STAR GROUND Terminal Block; COM; Protection Controller; AMP OUT; Power GND; SIignal IN+; SIignal IN-; SIignal IN+ SIignal GND; SIignal GND; SPEAKER OUT LEFT; GND

Earth Line Neutral

AMP OUT LEFT
AMP OUT RIGHT

SPEAKER OUT LEFT
SPEAKER OUT RIGHT

SPEAKER OUT LEFT | GND | GND | SPEAKER OUT LEFT

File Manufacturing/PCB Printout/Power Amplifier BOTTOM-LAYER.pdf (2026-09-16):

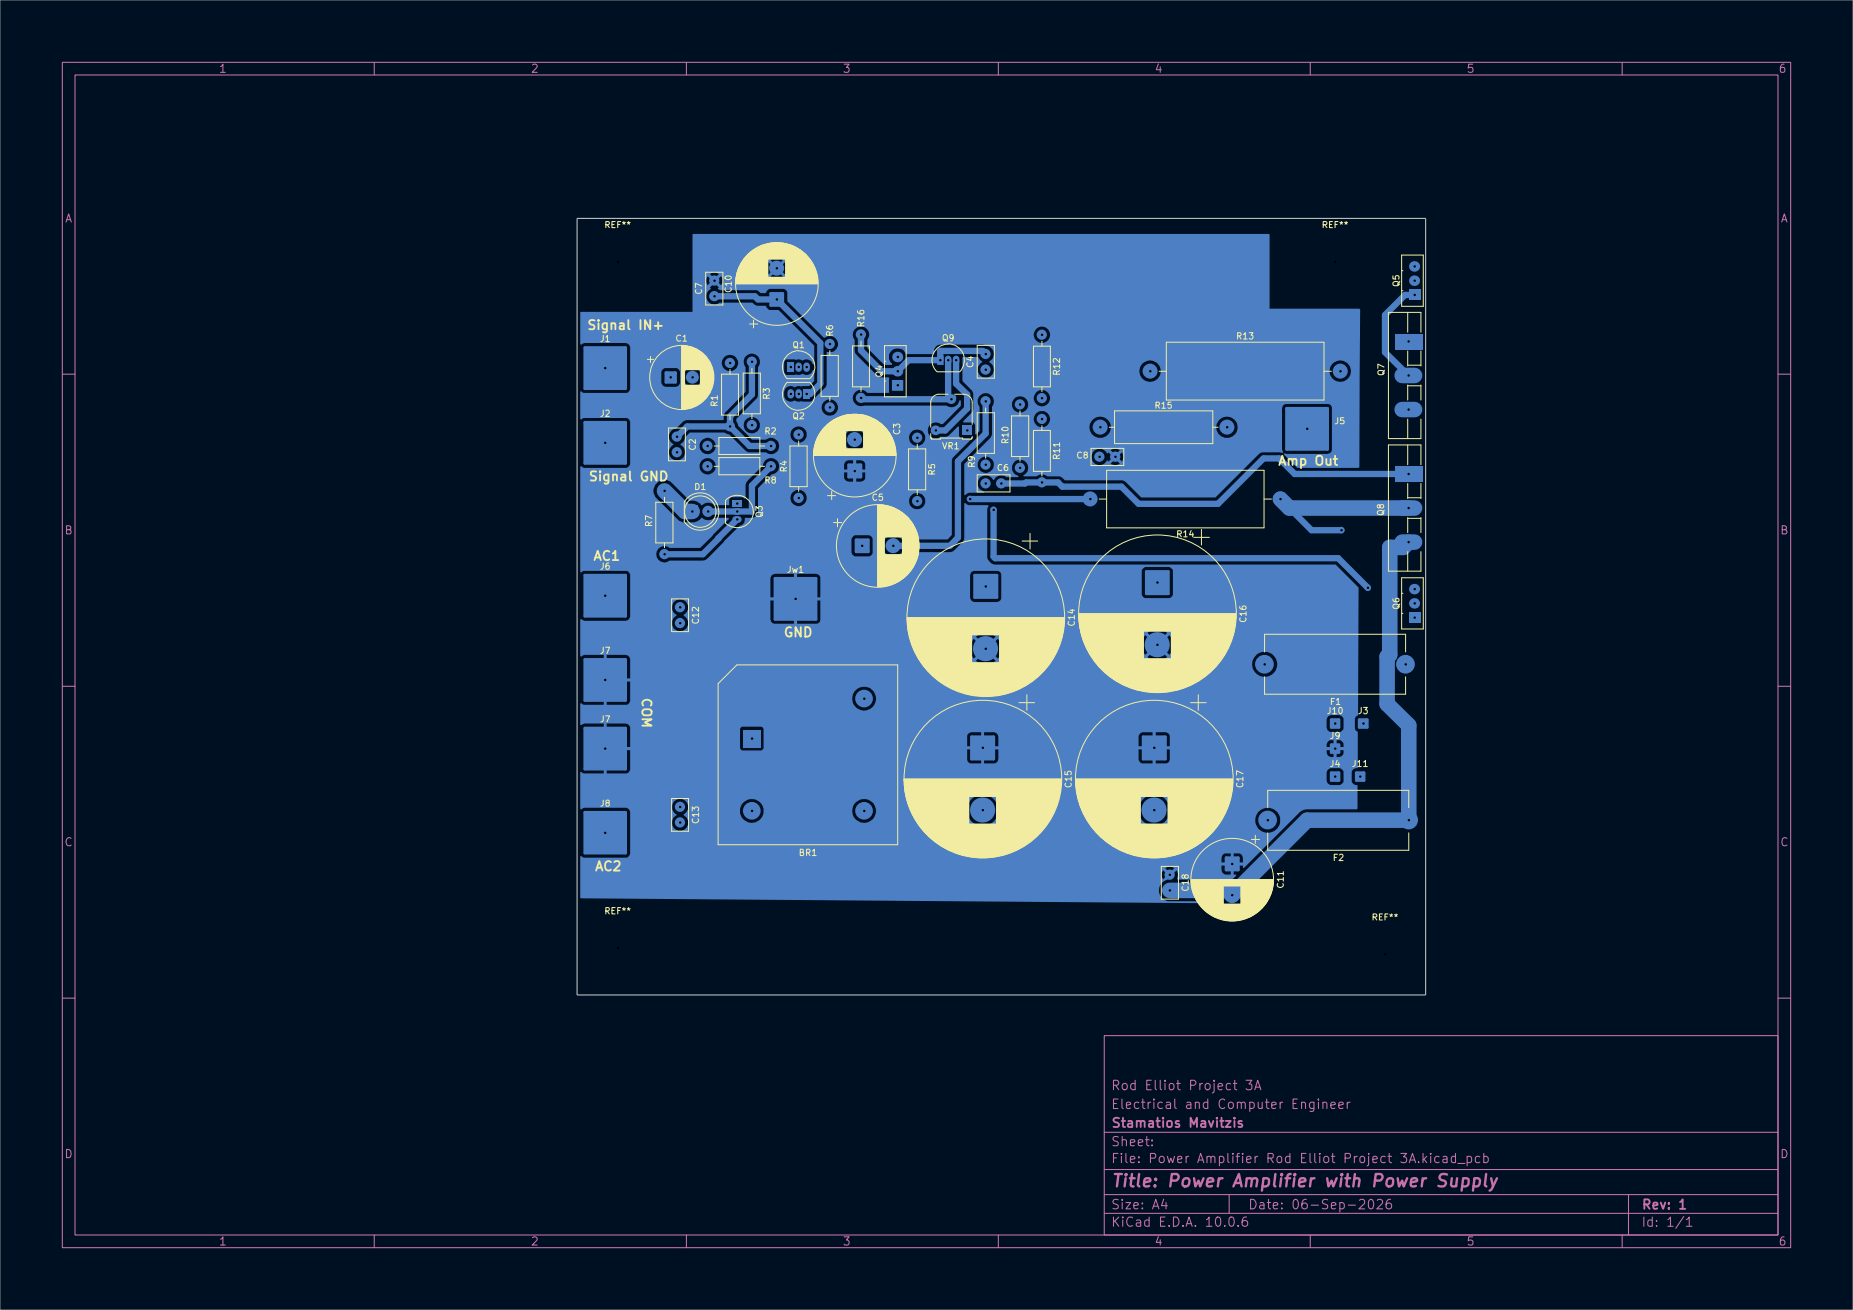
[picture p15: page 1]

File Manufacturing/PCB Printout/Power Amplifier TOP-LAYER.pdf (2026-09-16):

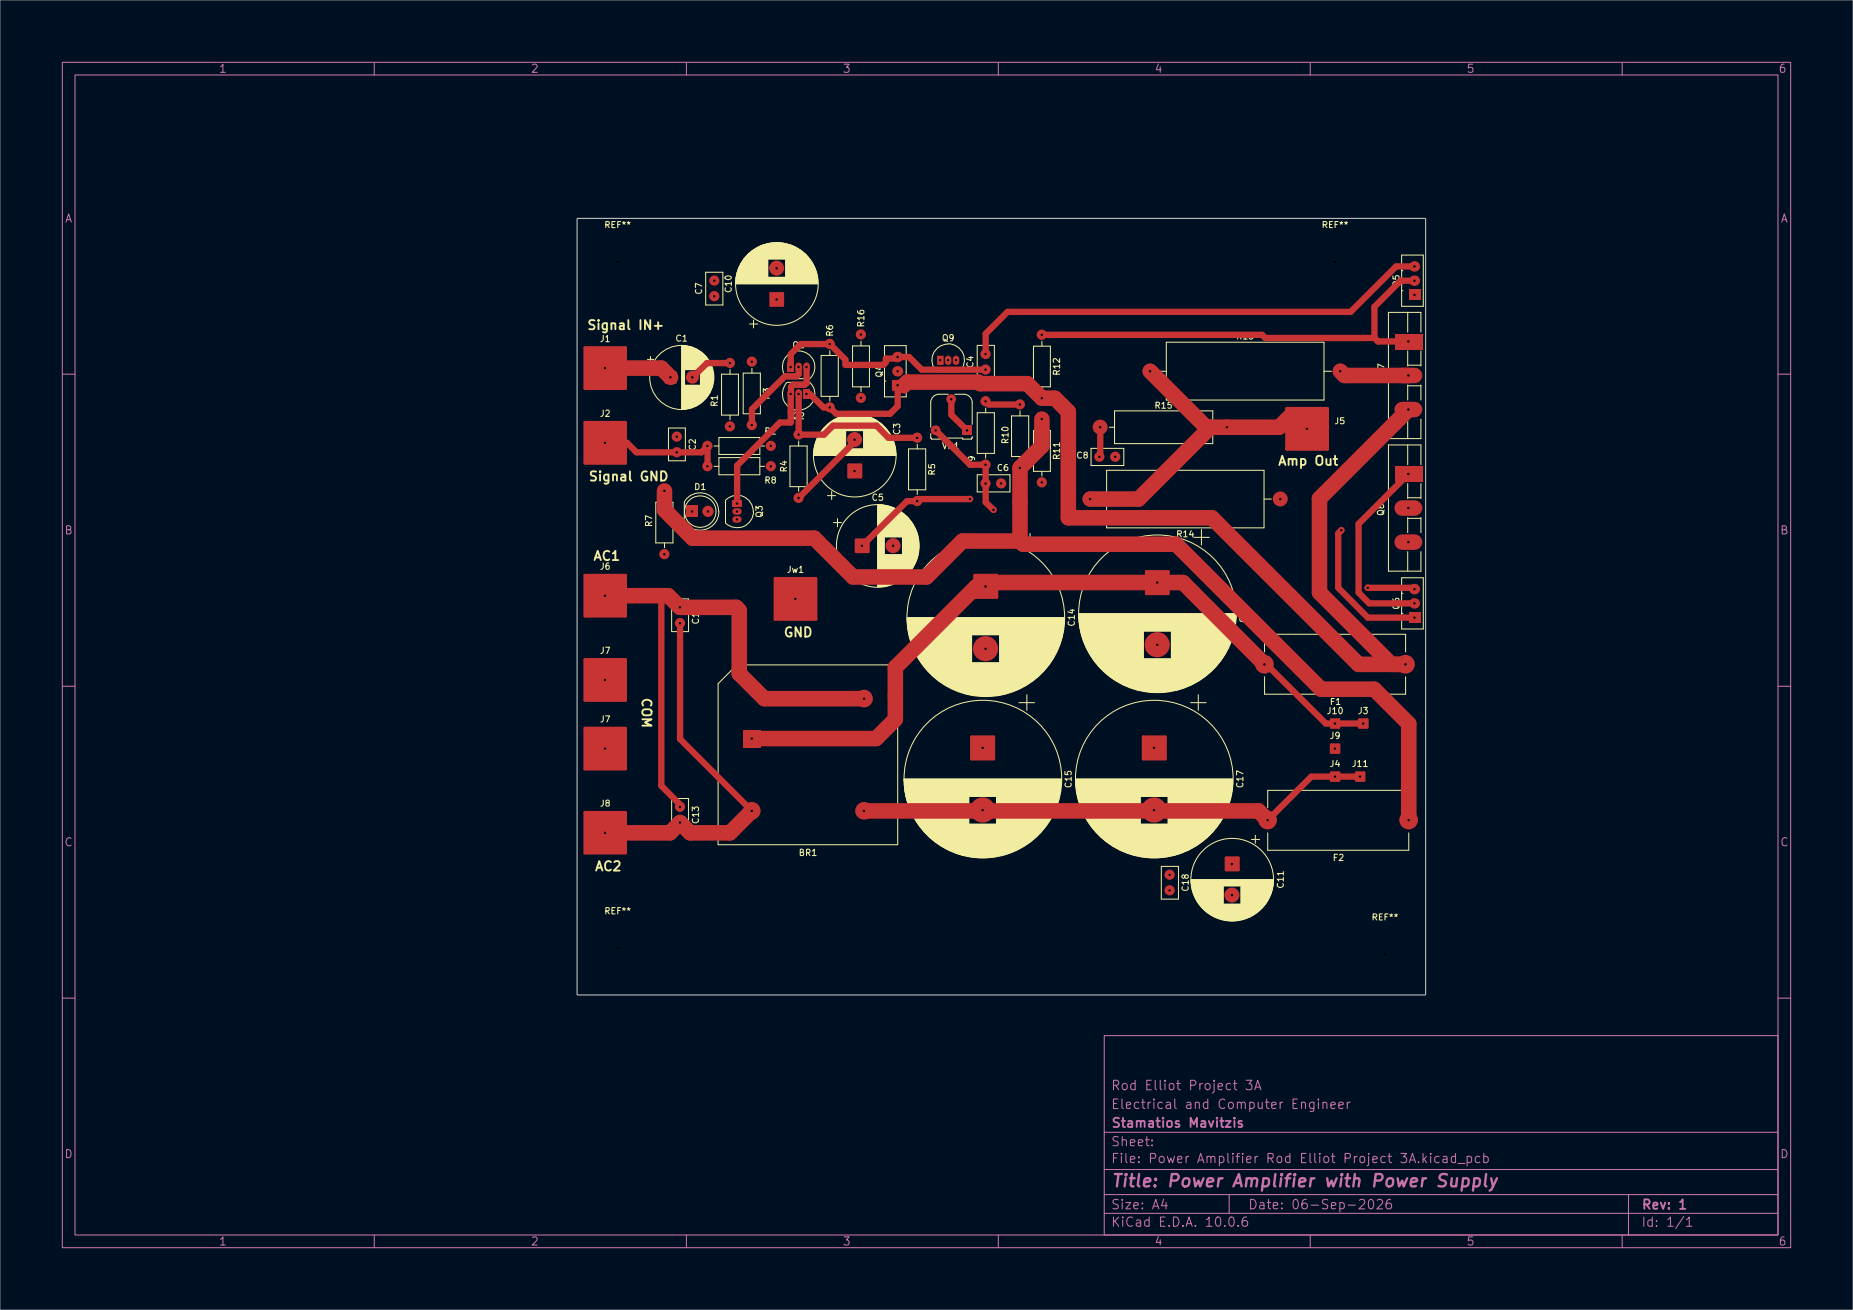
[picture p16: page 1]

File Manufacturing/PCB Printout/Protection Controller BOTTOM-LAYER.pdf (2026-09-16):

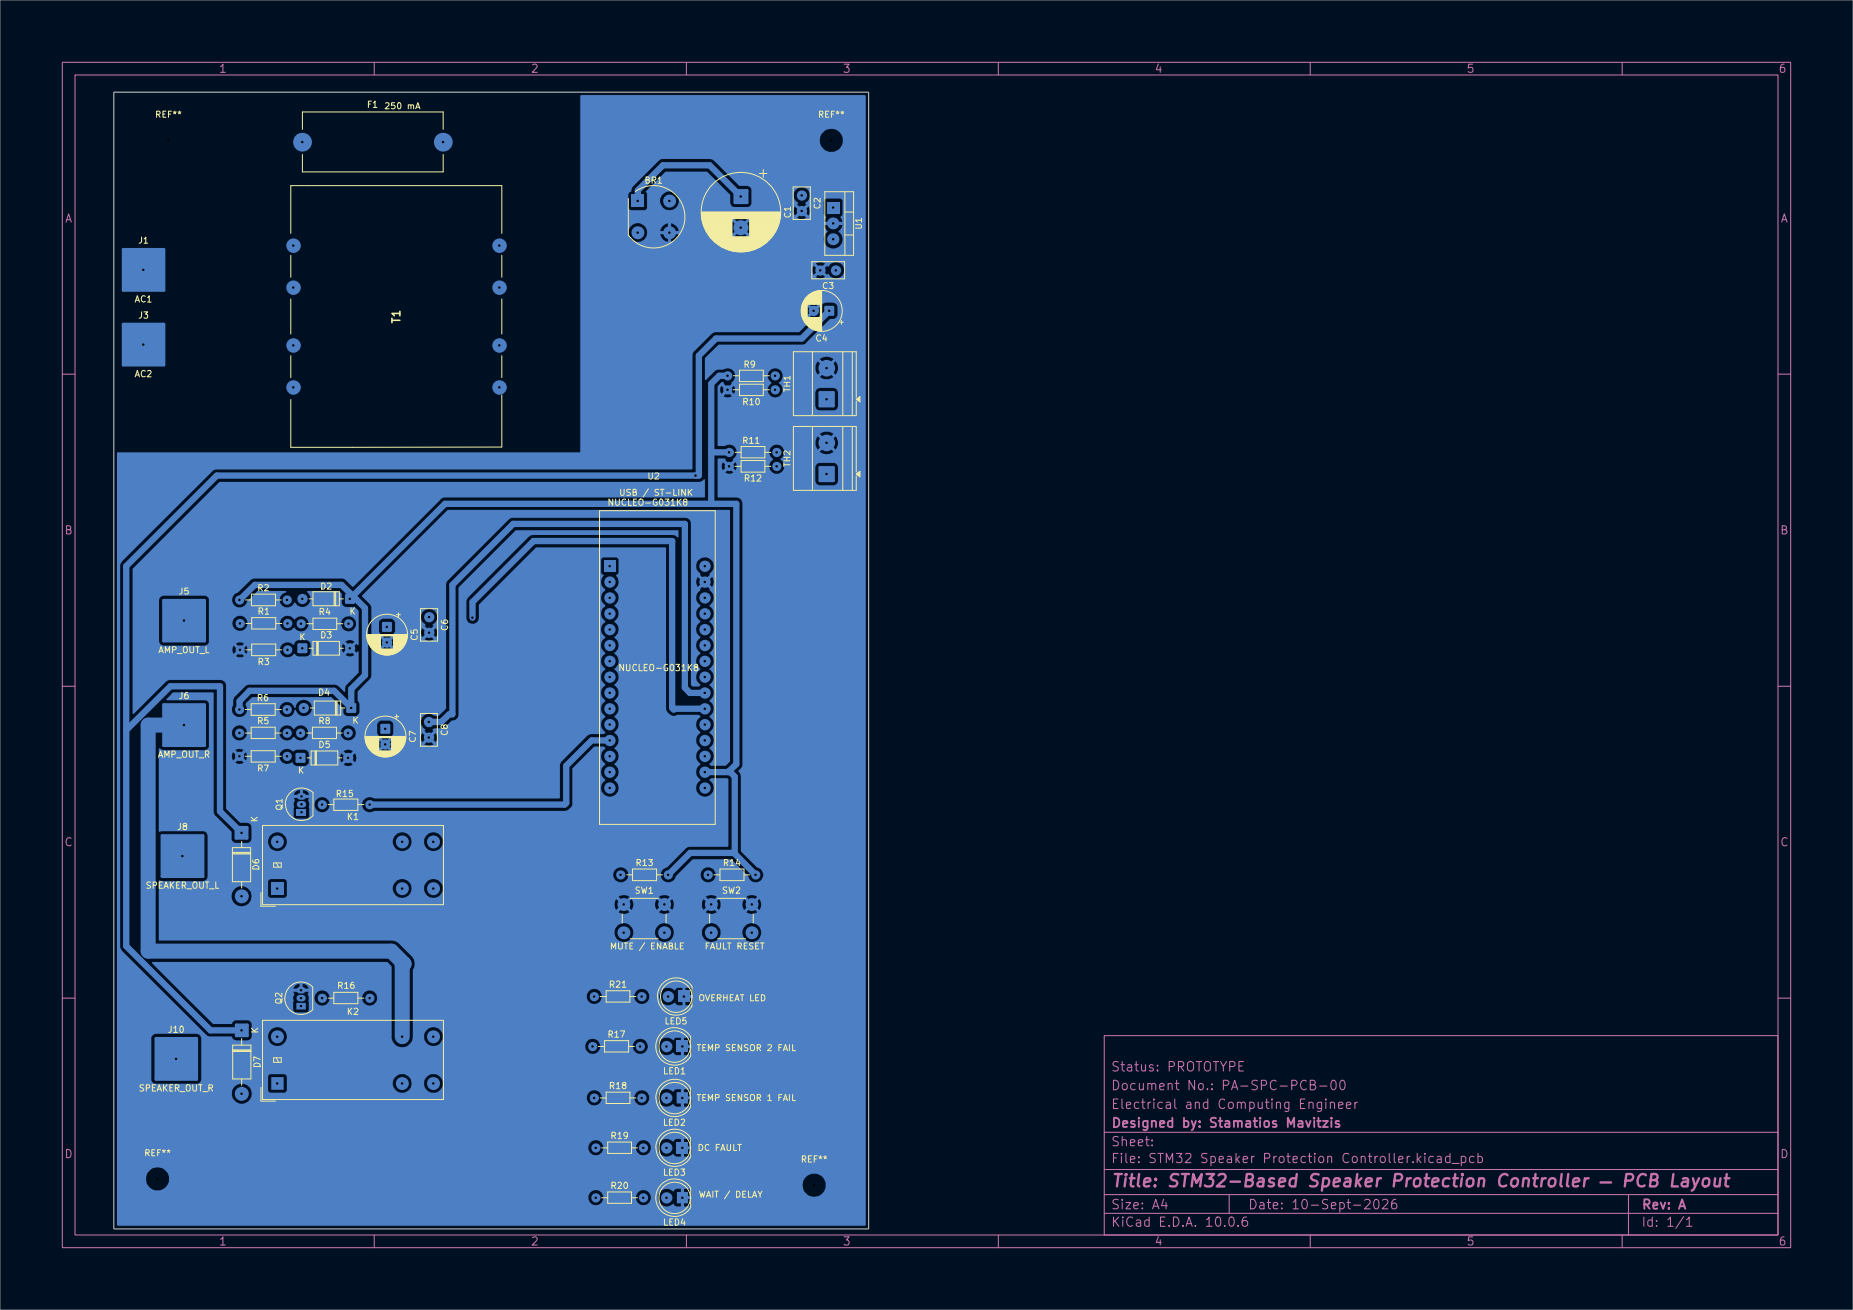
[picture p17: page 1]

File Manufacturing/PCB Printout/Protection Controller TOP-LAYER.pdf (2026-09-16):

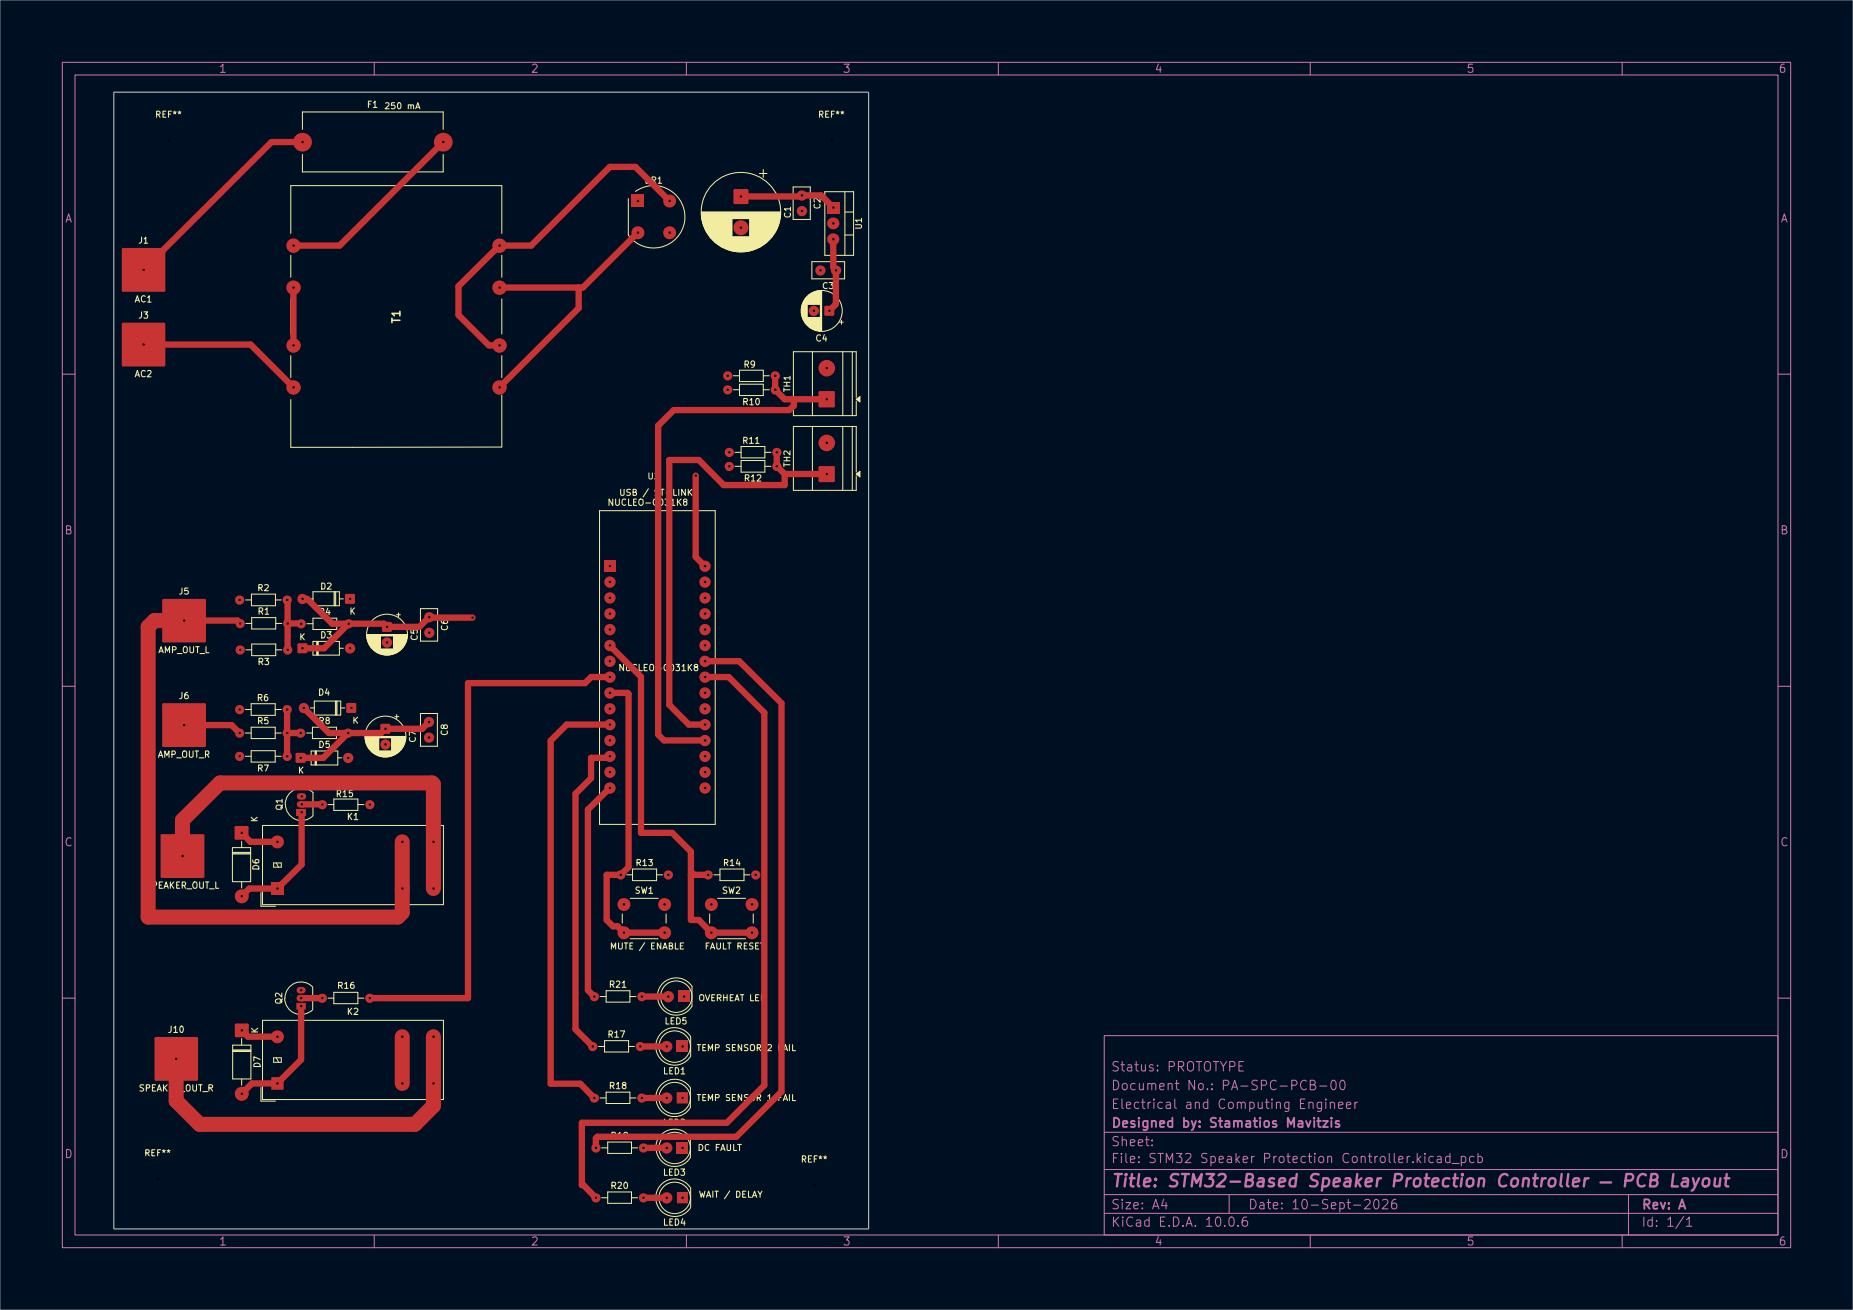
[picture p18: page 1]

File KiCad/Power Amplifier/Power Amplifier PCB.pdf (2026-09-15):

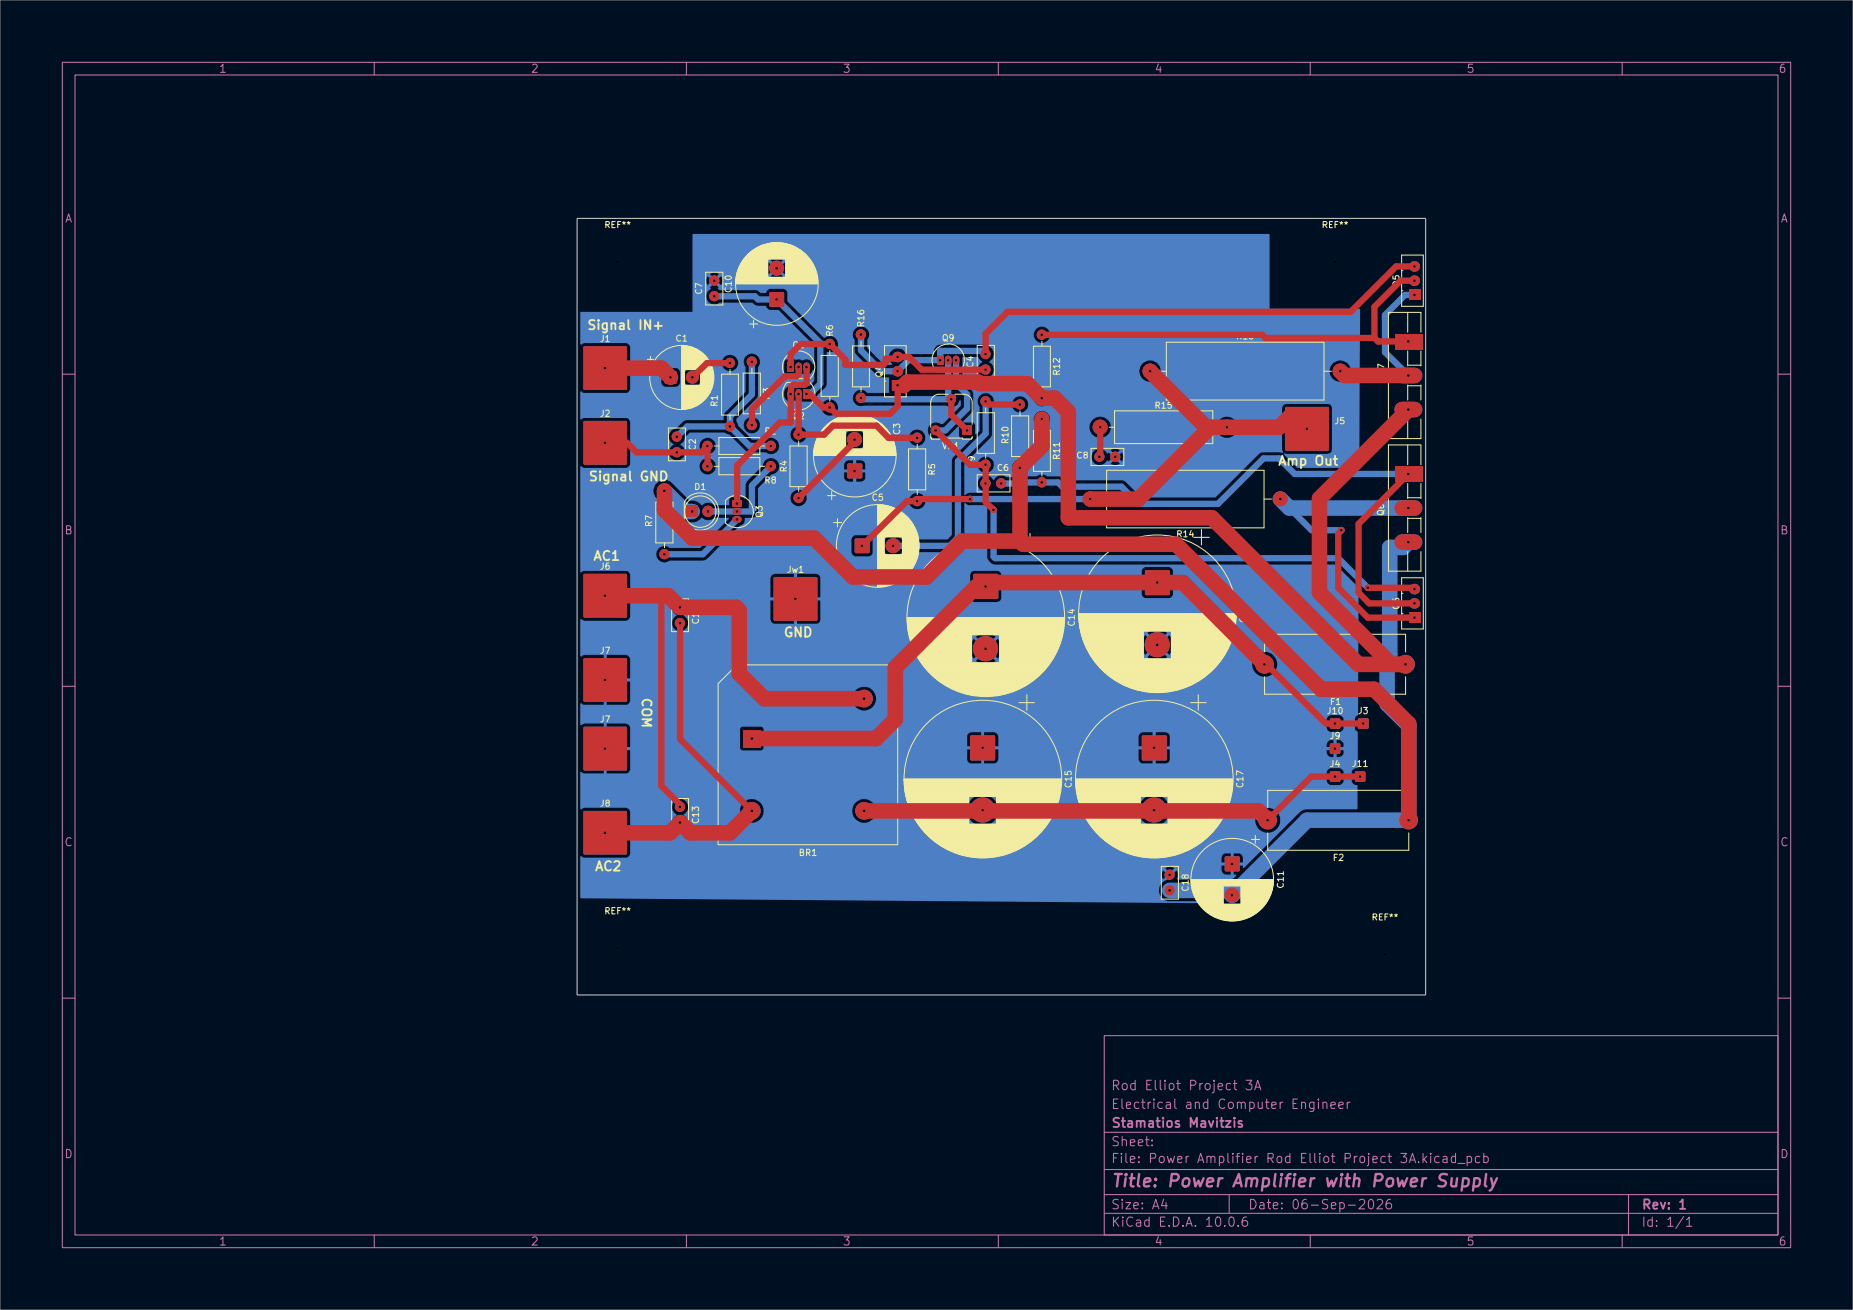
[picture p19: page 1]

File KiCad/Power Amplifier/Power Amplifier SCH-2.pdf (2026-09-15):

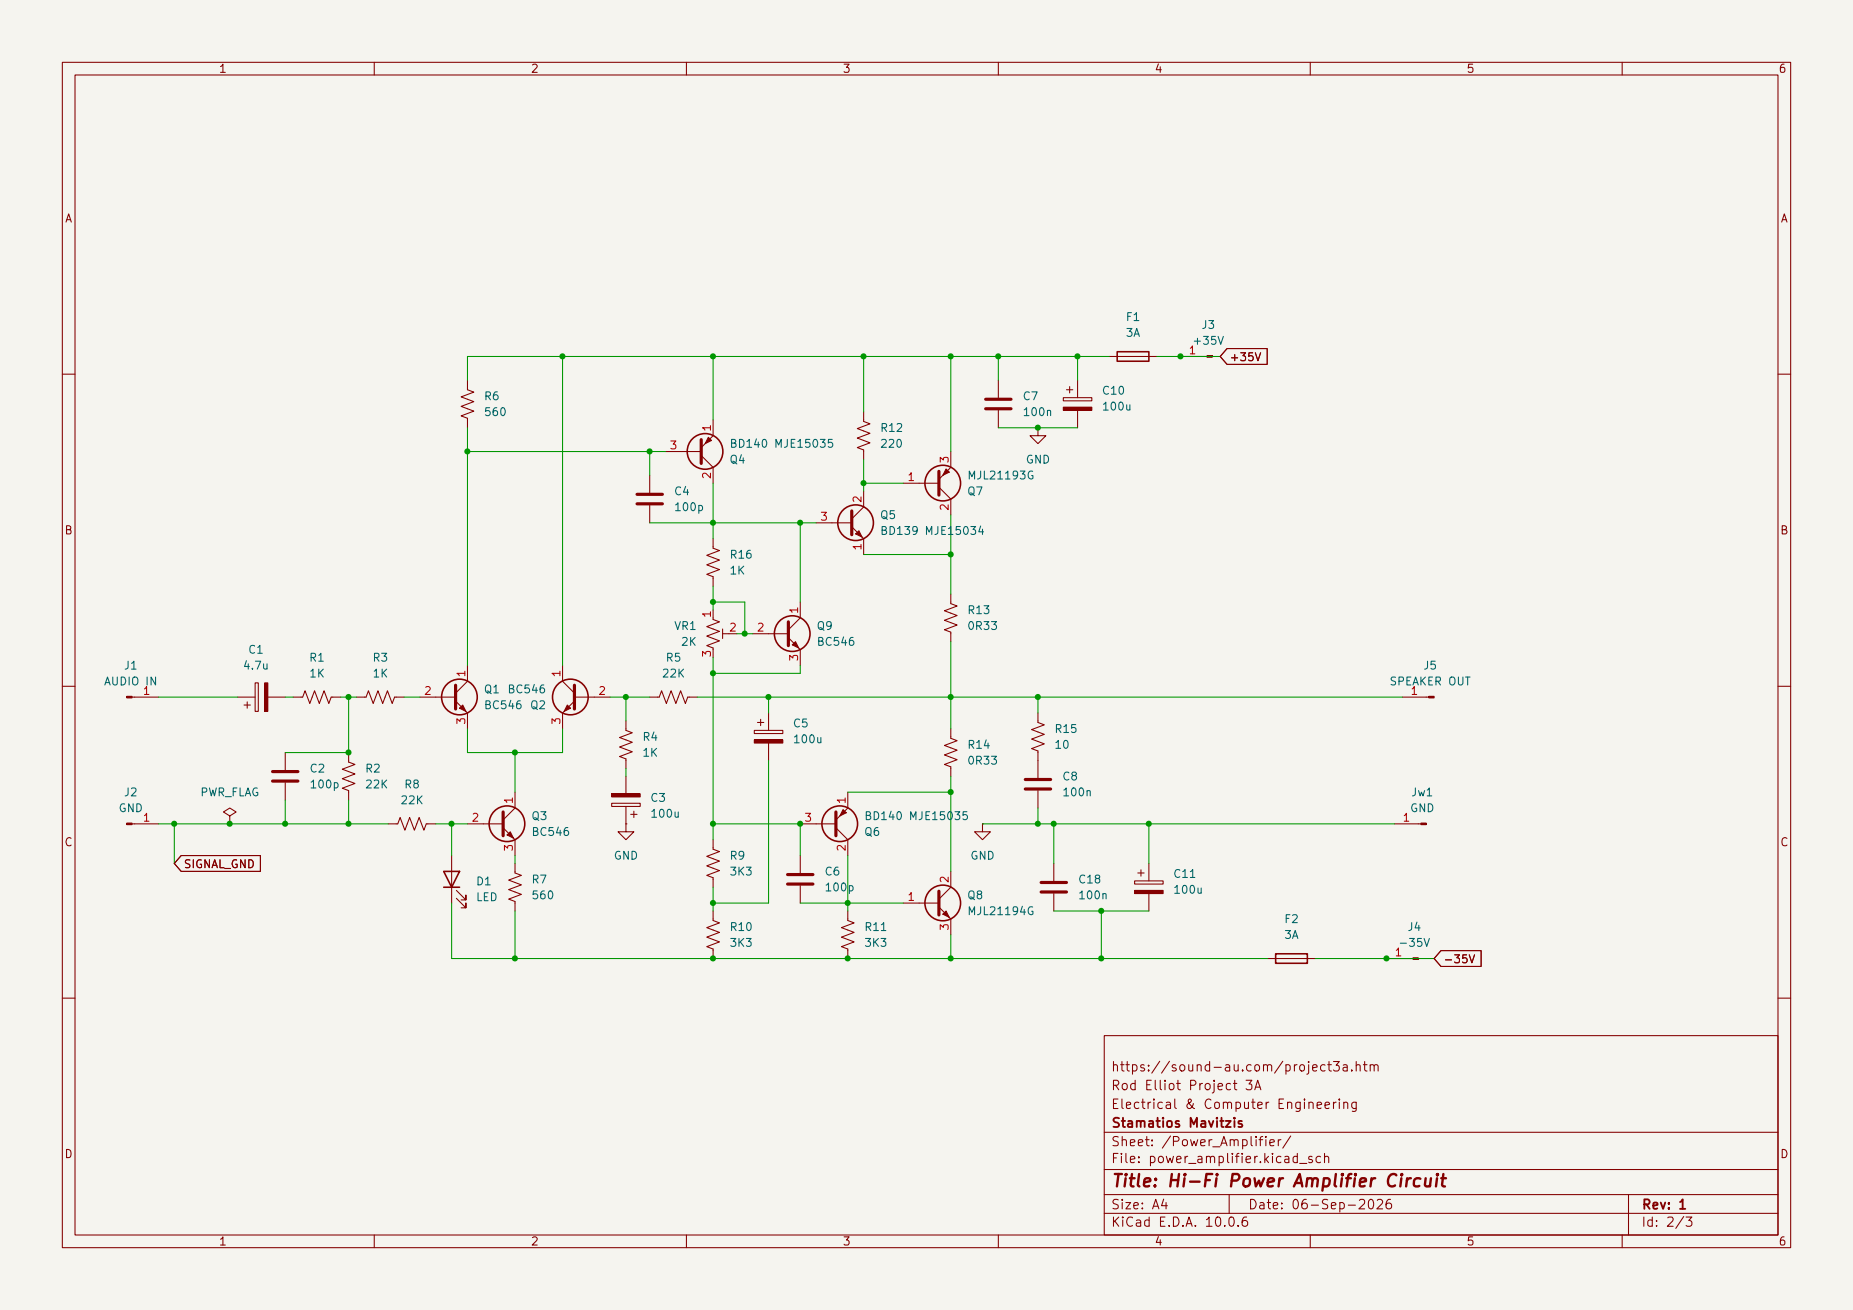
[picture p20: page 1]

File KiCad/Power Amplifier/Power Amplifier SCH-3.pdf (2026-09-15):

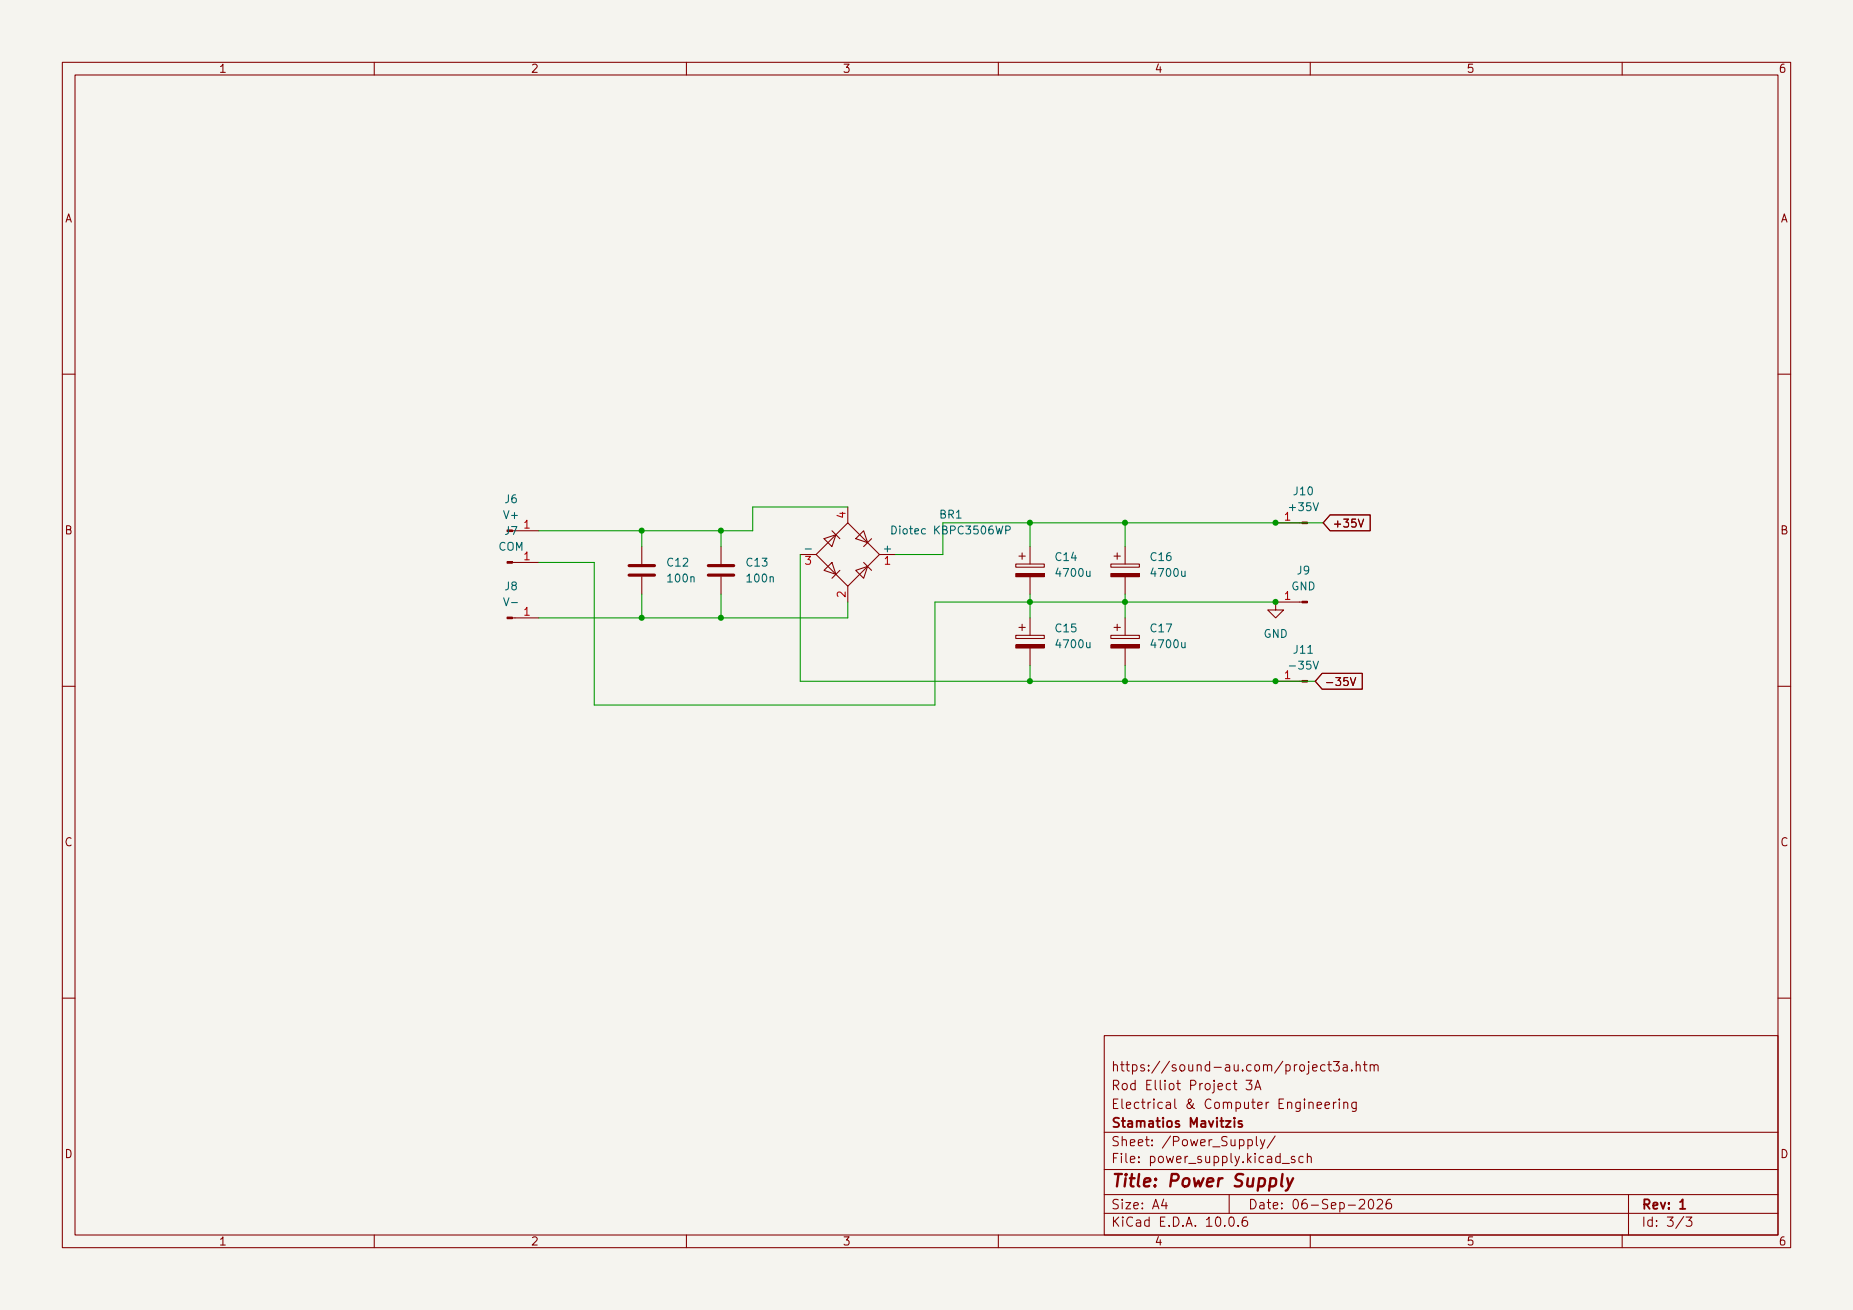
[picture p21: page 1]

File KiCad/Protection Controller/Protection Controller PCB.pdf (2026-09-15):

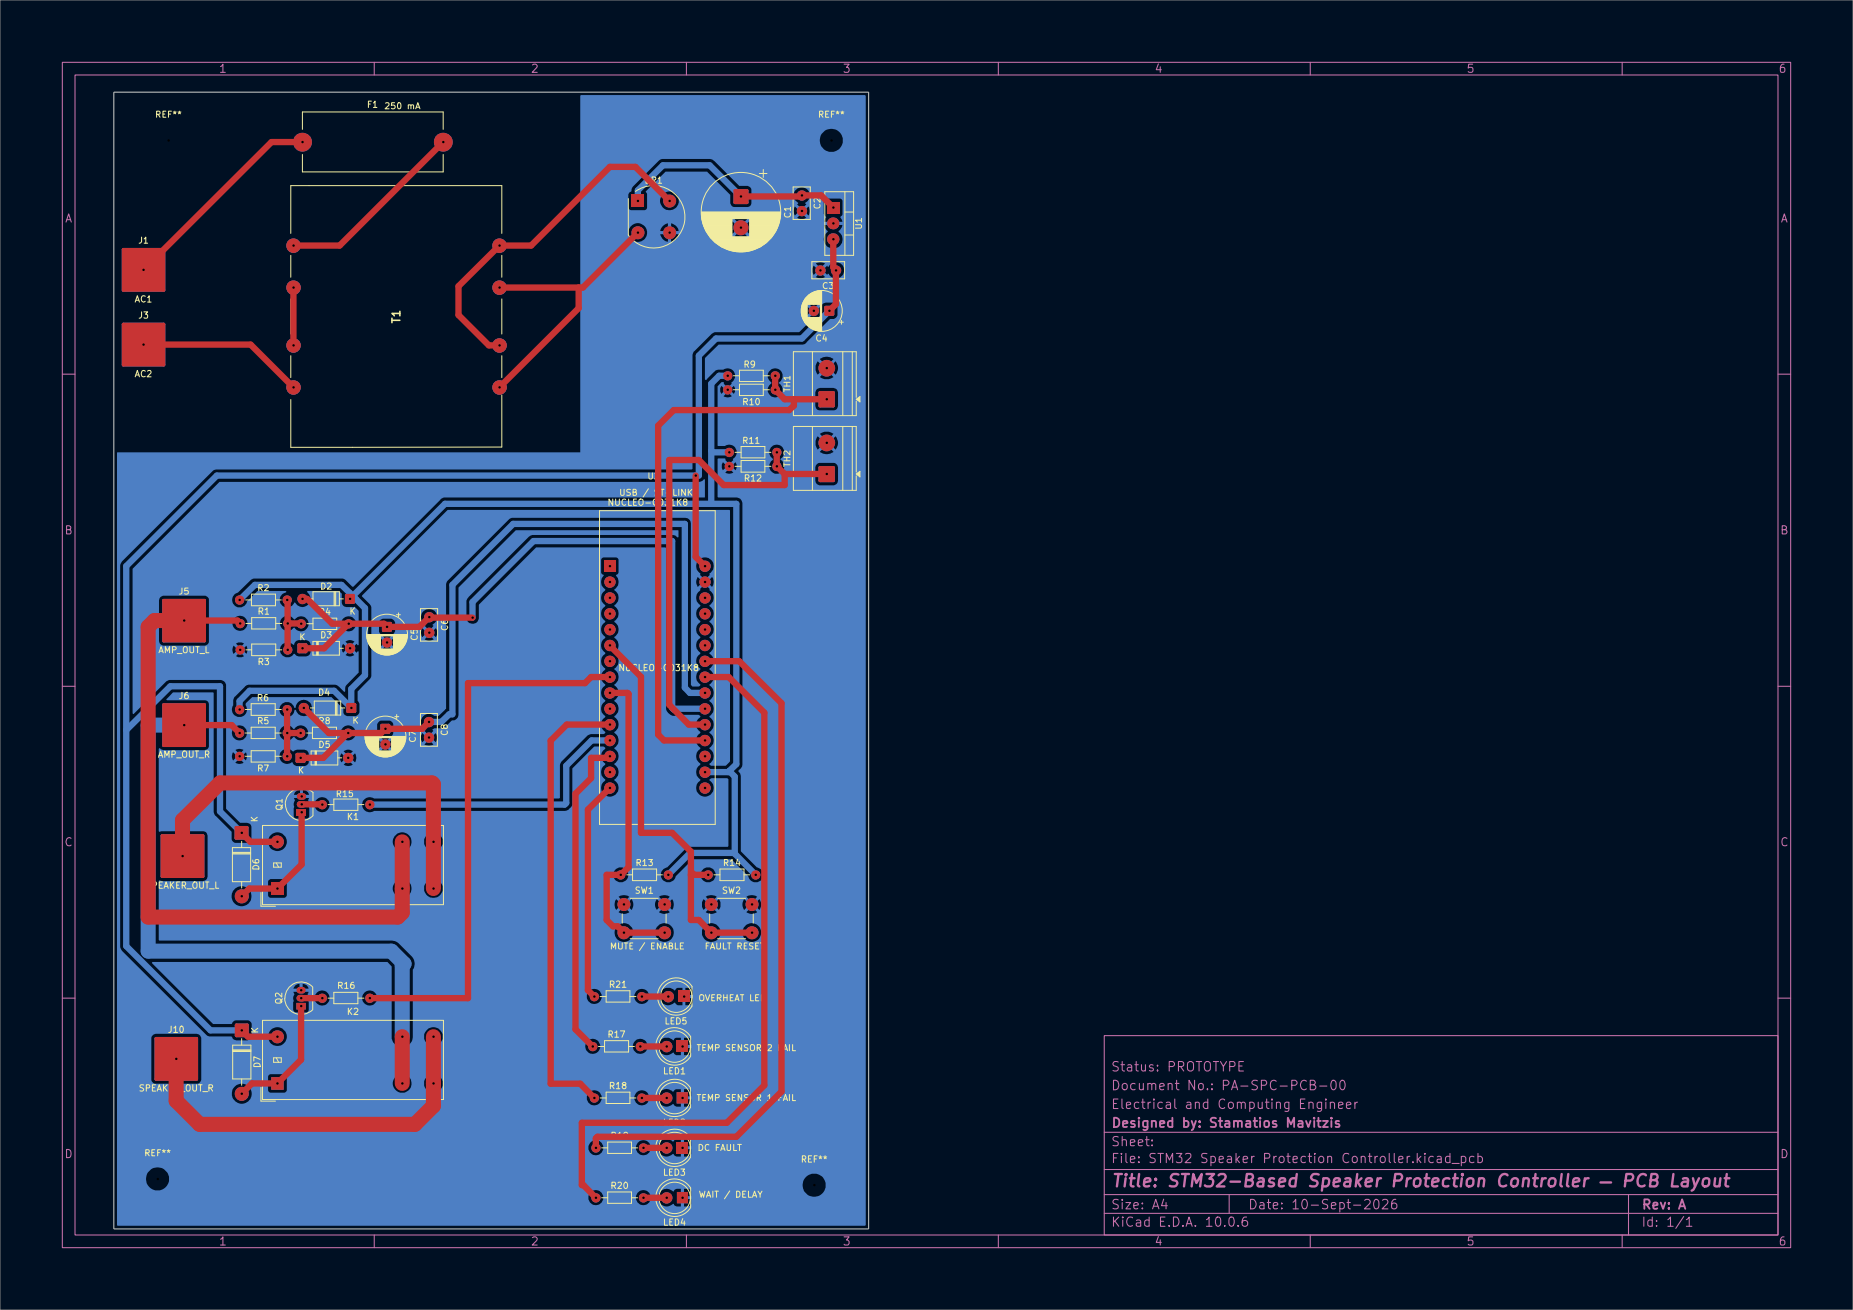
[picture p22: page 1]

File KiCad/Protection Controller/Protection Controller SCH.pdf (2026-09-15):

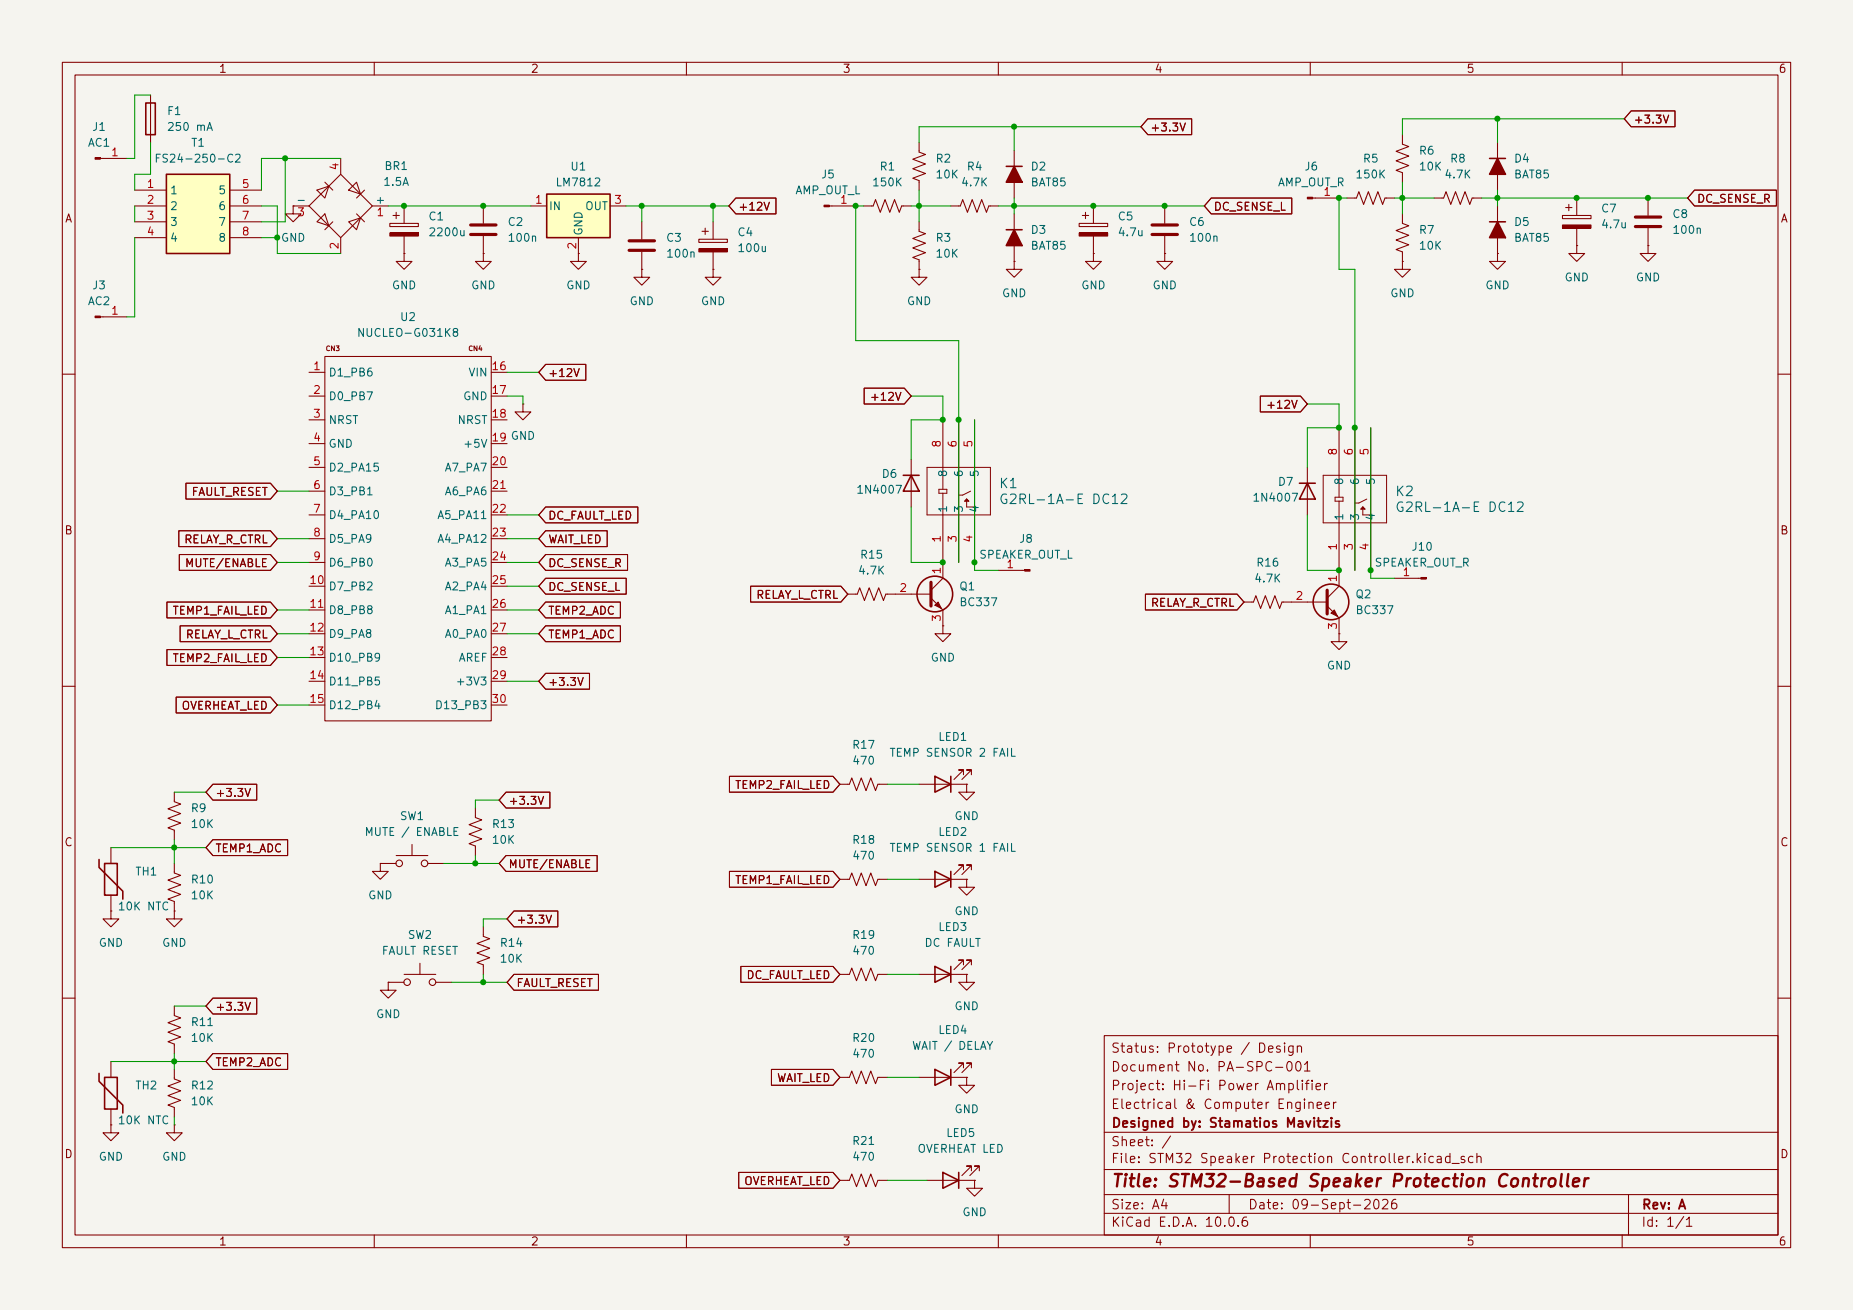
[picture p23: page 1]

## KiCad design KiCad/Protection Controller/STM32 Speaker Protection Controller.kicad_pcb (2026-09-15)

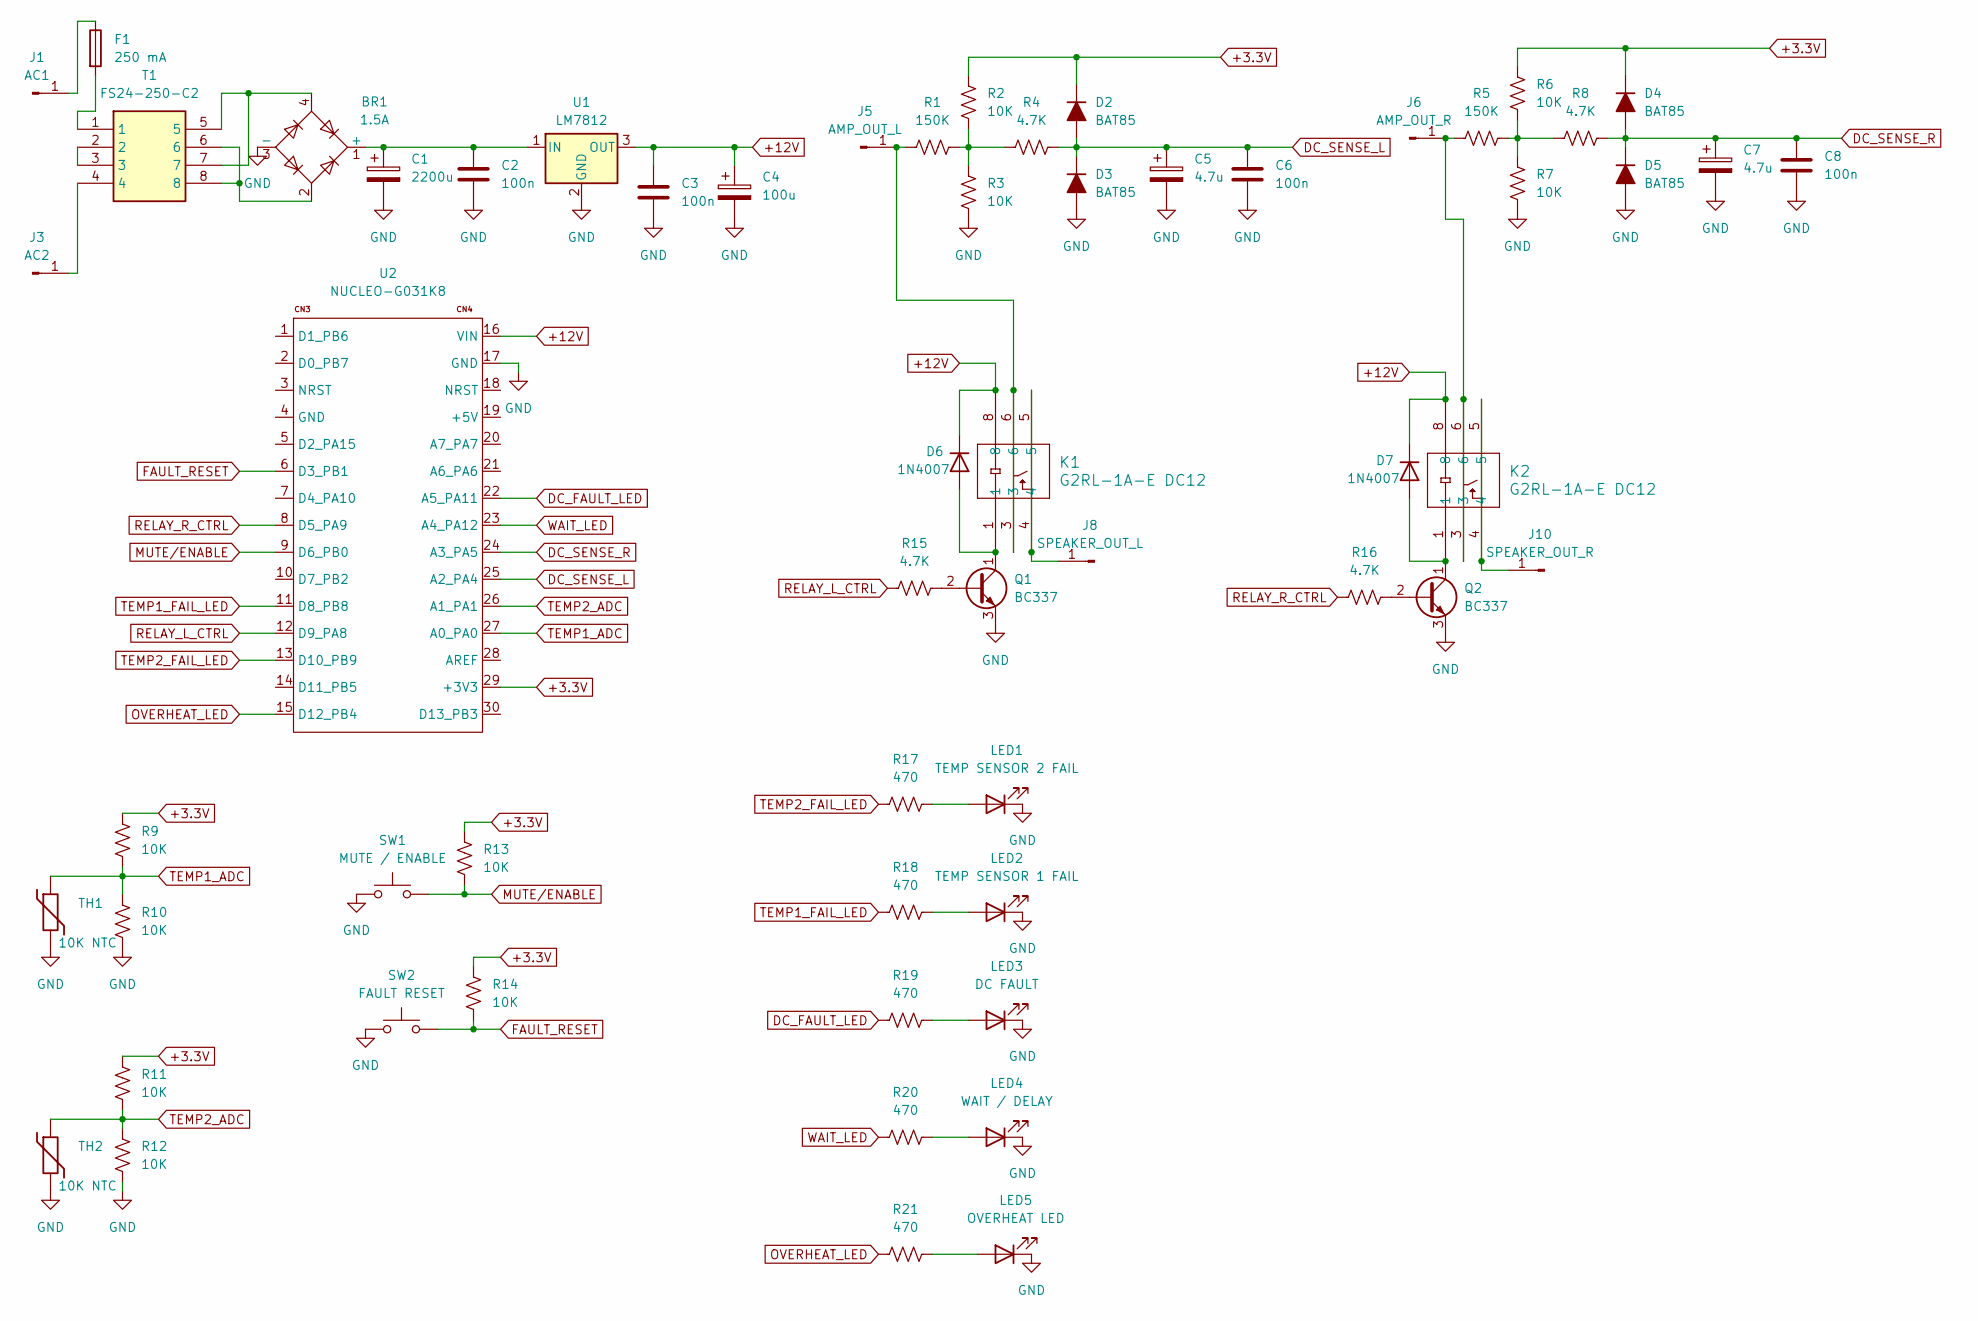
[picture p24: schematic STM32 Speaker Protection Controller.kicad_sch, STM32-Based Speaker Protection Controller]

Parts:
BR1: 1.5A; Diode_Bridge_Round_D9.8mm
C1: 2200u; CP_Radial_D12.5mm_P5.00mm
C2, C3, C6, C8: 100n; C_Disc_D5.0mm_W2.5mm_P2.50mm
C4: 100u; CP_Radial_D6.3mm_P2.50mm
C5, C7: 4.7u; CP_Radial_D6.3mm_P2.50mm
D2, D3, D4, D5: BAT85; D_DO-35_SOD27_P7.62mm_Horizontal
D6, D7: 1N4007; D_DO-41_SOD81_P10.16mm_Horizontal
F1: 250 mA; Fuseholder_Cylinder-5x20mm_Stelvio-Kontek_PTF78_Horizontal_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
J1: AC1; SolderWire-6sqmm_1x01_D3.5mm_OD7mm
J3: AC2; SolderWire-6sqmm_1x01_D3.5mm_OD7mm
J5: AMP_OUT_L; SolderWire-6sqmm_1x01_D3.5mm_OD7mm
J6: AMP_OUT_R; SolderWire-6sqmm_1x01_D3.5mm_OD7mm
J8: SPEAKER_OUT_L; SolderWire-6sqmm_1x01_D3.5mm_OD7mm
J10: SPEAKER_OUT_R; SolderWire-6sqmm_1x01_D3.5mm_OD7mm
K1, K2: G2RL-1A-E DC12; Relay_SPST_Omron_G2RL-1A-E
LED1: TEMP SENSOR 2 FAIL; LED_D5.0mm
LED2: TEMP SENSOR 1 FAIL; LED_D5.0mm
LED3: DC FAULT; LED_D5.0mm
LED4: WAIT / DELAY; LED_D5.0mm
LED5: OVERHEAT LED; LED_D5.0mm
Q1, Q2: BC337; TO-92_Inline
R1, R5: 150K; R_Axial_DIN0204_L3.6mm_D1.6mm_P7.62mm_Horizontal
R2, R3, R6, R7, R9, R10, R11, R12, R13, R14: 10K; R_Axial_DIN0204_L3.6mm_D1.6mm_P7.62mm_Horizontal
R4, R8, R15, R16: 4.7K; R_Axial_DIN0204_L3.6mm_D1.6mm_P7.62mm_Horizontal
R17, R18, R19, R20, R21: 470; R_Axial_DIN0204_L3.6mm_D1.6mm_P7.62mm_Horizontal
SW1: MUTE / ENABLE; SW_PUSH_6mm_H5mm
SW2: FAULT RESET; SW_PUSH_6mm_H5mm
T1: FS24-250-C2; FS24250C2; Manufacturer_Part_Number FS24-250-C2; Mouser Part Number 553-FS24-250-C2
TH1, TH2: 10K NTC; TerminalBlock_Phoenix_MKDS-1,5-2_1x02_P5.00mm_Horizontal
U1: LM7812; TO-220-3_Vertical
U2: NUCLEO-G031K8

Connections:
+3.3V: D2.1 (K), D4.1 (K), R2.1, R6.1, R9.1, R11.1, R13.2, R14.2, U2.29 (+3V3)
+12V: C3.1, C4.1, D6.1 (K), D7.1 (K), K1.8, K2.8, U1.3 (OUT), U2.16 (VIN)
DC_FAULT_LED: R19.1, U2.22 (A5_PA11)
DC_SENSE_L: C5.1, C6.1, D2.2 (A), D3.1 (K), R4.2, U2.25 (A2_PA4)
DC_SENSE_R: C7.1, C8.1, D4.2 (A), D5.1 (K), R8.2, U2.24 (A3_PA5)
FAULT_RESET: R14.1, SW2.2, U2.6 (D3_PB1)
GND: BR1.3 (-), C1.2, C2.2, C3.2, C4.2, C5.2, C6.2, C7.2, C8.2, D3.2 (A), D5.2 (A), LED1.1 (K), LED2.1 (K), LED3.1 (K), LED4.1 (K), LED5.1 (K), Q1.3 (E), Q2.3 (E), R3.2, R7.2, R10.2, R12.2, SW1.1, SW2.1, TH1.2, TH2.2, U1.2 (GND), U2.17 (GND)
MUTE/ENABLE: R13.1, SW1.2, U2.9 (D6_PB0)
unnamed: BR1.1 (+), C1.1, C2.1, U1.1 (IN)
unnamed: BR1.2, T1.6, T1.8
unnamed: BR1.4, T1.5, T1.7
unnamed: D6.2 (A), K1.1, Q1.1 (C)
unnamed: D7.2 (A), K2.1, Q2.1 (C)
unnamed: F1.2, T1.1
unnamed: F1.1, J1.1 (Pin_1_1)
unnamed: J3.1 (Pin_1_1), T1.4
unnamed: J5.1 (Pin_1_1), K1.3, K1.6, R1.1
unnamed: J6.1 (Pin_1_1), K2.3, K2.6, R5.1
unnamed: J8.1 (Pin_1_1), K1.4, K1.5
unnamed: J10.1 (Pin_1_1), K2.4, K2.5
unnamed: LED1.2 (A), R17.2
unnamed: LED2.2 (A), R18.2
unnamed: LED3.2 (A), R19.2
unnamed: LED4.2 (A), R20.2
unnamed: LED5.2 (A), R21.2
unnamed: Q1.2 (B), R15.2
unnamed: Q2.2 (B), R16.2
unnamed: R1.2, R2.2, R3.1, R4.1
unnamed: R5.2, R6.2, R7.1, R8.1
unnamed: T1.2, T1.3
OVERHEAT_LED: R21.1, U2.15 (D12_PB4)
RELAY_L_CTRL: R15.1, U2.12 (D9_PA8)
RELAY_R_CTRL: R16.1, U2.8 (D5_PA9)
TEMP1_ADC: R9.2, R10.1, TH1.1, U2.27 (A0_PA0)
TEMP1_FAIL_LED: R18.1, U2.11 (D8_PB8)
TEMP2_ADC: R11.2, R12.1, TH2.1, U2.26 (A1_PA1)
TEMP2_FAIL_LED: R17.1, U2.13 (D10_PB9)
WAIT_LED: R20.1, U2.23 (A4_PA12)

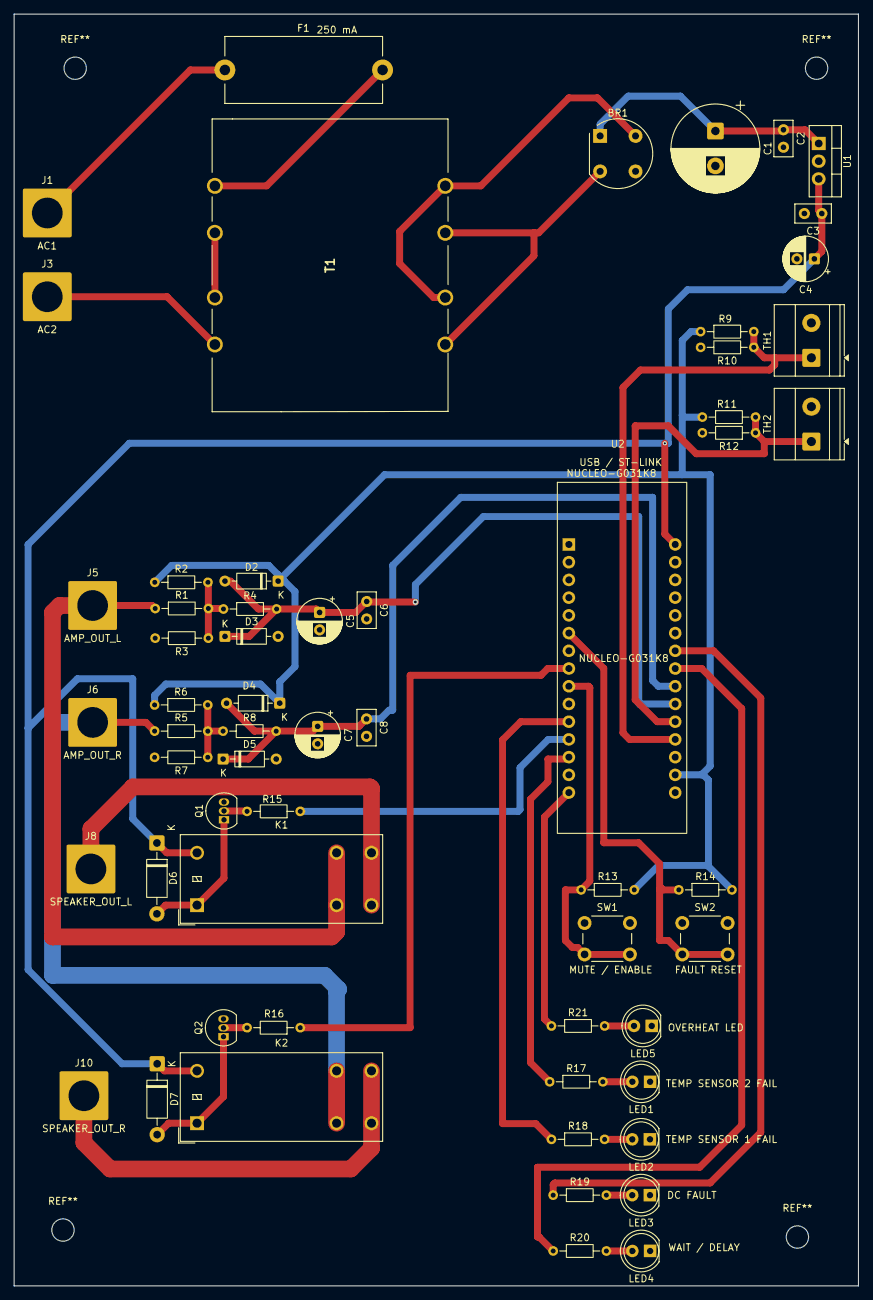
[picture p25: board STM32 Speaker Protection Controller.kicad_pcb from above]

Board: 2 copper layers, 121.0 x 182.2 mm, 59 parts (0 on the bottom side), 38 nets.

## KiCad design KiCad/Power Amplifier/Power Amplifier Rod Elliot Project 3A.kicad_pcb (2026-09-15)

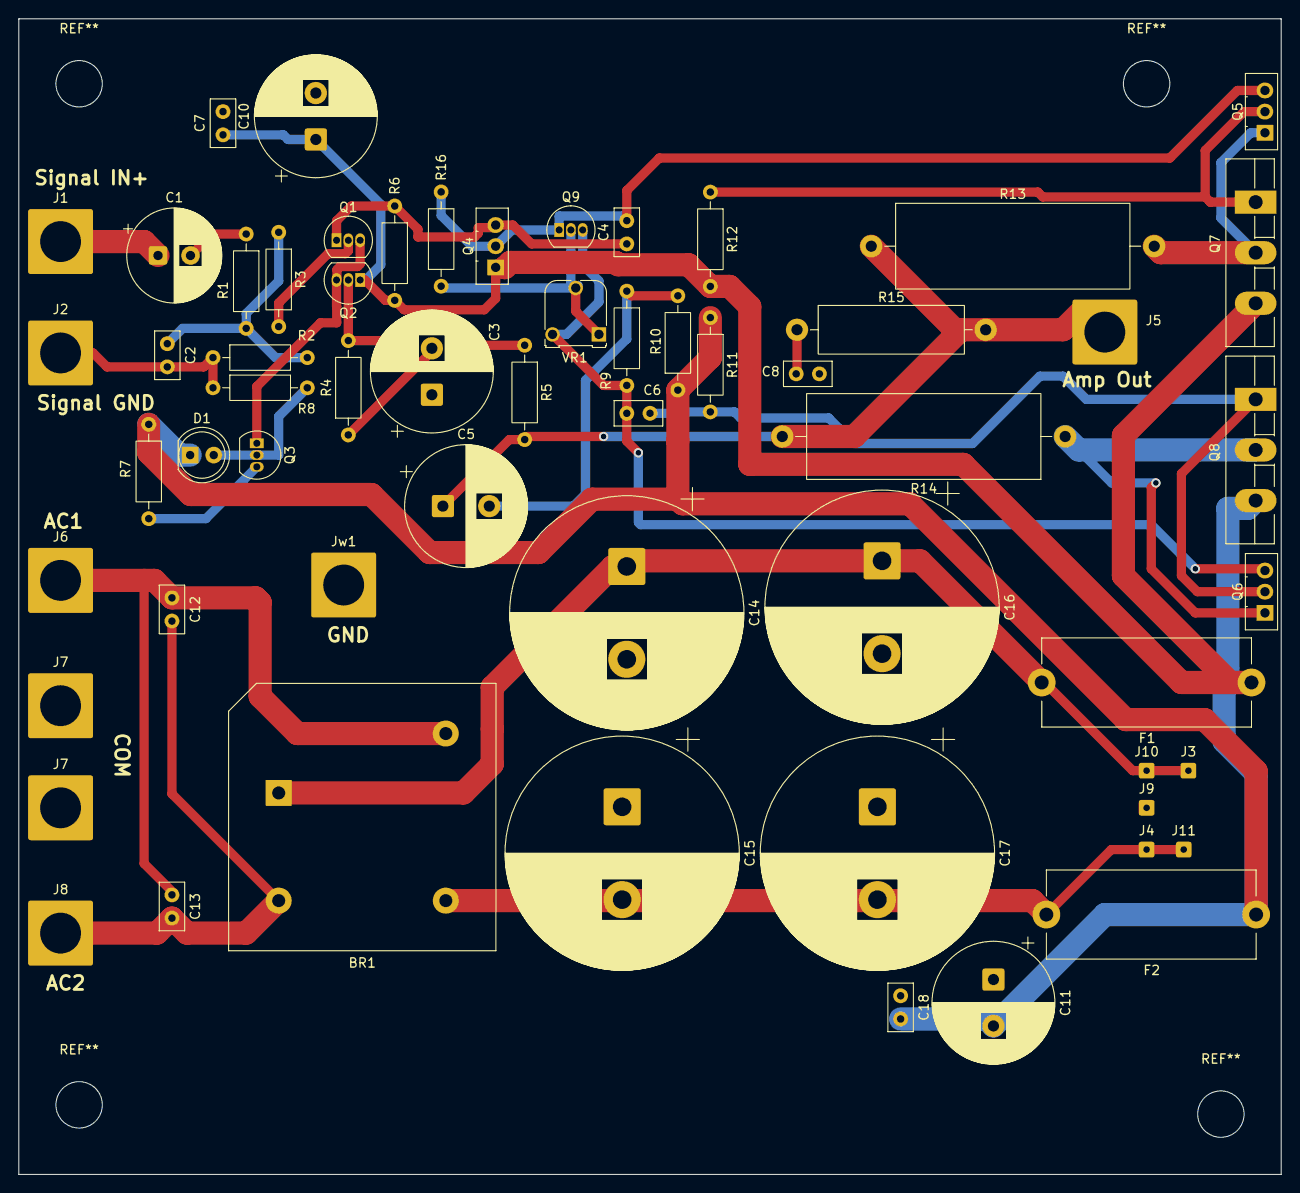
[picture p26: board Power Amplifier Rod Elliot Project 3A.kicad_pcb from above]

Board: 2 copper layers, 136.0 x 124.5 mm, 60 parts (0 on the bottom side), 28 nets.

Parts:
BR1: Diotec KBPC3506WP; Diode_Bridge_28.6x28.6x7.3mm_P18.0mm_P11.6mm
C1: 4.7u; CP_Radial_D10.0mm_P3.50mm
C2, C4, C6: 100p; C_Disc_D5.0mm_W2.5mm_P2.50mm
C3, C5, C10, C11: 100u; CP_Radial_D13.0mm_P5.00mm
C7, C8, C12, C13, C18: 100n; C_Disc_D5.0mm_W2.5mm_P2.50mm
C14, C15, C16, C17: 4700u; CP_Radial_D25.0mm_P10.00mm_SnapIn
D1: LED; LED_D5.0mm
F1, F2: 3A; Fuseholder_Cylinder-5x20mm_Stelvio-Kontek_PTF78_Horizontal_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
J1: AUDIO IN; SolderWire-6sqmm_1x01_D3.5mm_OD7mm
J2: GND; SolderWire-6sqmm_1x01_D3.5mm_OD7mm
J3, J10: +35V; SolderWire-0.127sqmm_1x01_D0.48mm_OD1mm
J4, J11: -35V; SolderWire-0.127sqmm_1x01_D0.48mm_OD1mm
J5: SPEAKER OUT; SolderWire-6sqmm_1x01_D3.5mm_OD7mm
J6: V+; SolderWire-6sqmm_1x01_D3.5mm_OD7mm
J7, J7#2: COM; SolderWire-6sqmm_1x01_D3.5mm_OD7mm
J8: V-; SolderWire-6sqmm_1x01_D3.5mm_OD7mm
J9: GND; SolderWire-0.127sqmm_1x01_D0.48mm_OD1mm
Jw1: GND; SolderWire-6sqmm_1x01_D3.5mm_OD7mm
Q1, Q2, Q3, Q9: BC546; TO-92_Inline
Q4, Q6: BD140 MJE15035; TO-126-3_Vertical
Q5: BD139 MJE15034; TO-126-3_Vertical
Q7: MJL21193G; TO-264-3_Vertical
Q8: MJL21194G; TO-264-3_Vertical
R1, R3, R4, R16: 1K; R_Axial_DIN0207_L6.3mm_D2.5mm_P10.16mm_Horizontal
R2, R5, R8: 22K; R_Axial_DIN0207_L6.3mm_D2.5mm_P10.16mm_Horizontal
R6, R7: 560; R_Axial_DIN0207_L6.3mm_D2.5mm_P10.16mm_Horizontal
R9, R10, R11: 3K3; R_Axial_DIN0207_L6.3mm_D2.5mm_P10.16mm_Horizontal
R12: 220; R_Axial_DIN0207_L6.3mm_D2.5mm_P10.16mm_Horizontal
R13, R14: 0R33; R_Axial_Power_L25.0mm_W9.0mm_P30.48mm
R15: 10; R_Axial_DIN0516_L15.5mm_D5.0mm_P20.32mm_Horizontal
VR1: 2K; Potentiometer_Runtron_RM-065_Vertical

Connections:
+35V: BR1.1 (+), C14.1, C16.1, F1.2, J3.1 (Pin_1_1), J10.1 (Pin_1_1)
-35V: BR1.3 (-), C15.2, C17.2, F2.2, J4.1 (Pin_1_1), J11.1 (Pin_1_1)
GND: C3.1, C7.2, C8.2, C10.2, C11.1, C14.2, C15.1, C16.2, C17.1, C18.1, J7.1 (Pin_1_1), J7#2.1 (Pin_1_1), J9.1 (Pin_1_1), Jw1.1 (Pin_1_1)
unnamed: C1.2, R1.1
unnamed: C2.1, R1.2, R2.2, R3.1
unnamed: C3.2, R4.1
unnamed: C5.2, R9.1, R10.2
unnamed: C8.1, R15.1
unnamed: D1.2 (A), Q3.2 (B), R8.2
unnamed: C11.2, C18.2, D1.1 (K), F2.1, Q8.3 (E), R7.1, R10.1, R11.1
unnamed: C1.1, J1.1 (Pin_1_1)
unnamed: C5.1, J5.1 (Pin_1_1), R5.2, R13.1, R14.2, R15.2
unnamed: BR1.4, C12.1, C13.1, J6.1 (Pin_1_1)
unnamed: BR1.2, C12.2, C13.2, J8.1 (Pin_1_1)
unnamed: Q1.2 (B), R3.2
unnamed: C4.1, Q1.1 (C), Q4.3 (B), R6.1
unnamed: Q1.3 (E), Q2.3 (E), Q3.1 (C)
unnamed: Q2.2 (B), R4.2, R5.1
unnamed: C7.1, C10.1, F1.1, Q2.1 (C), Q4.1 (E), Q7.3 (E), R6.2, R12.2
unnamed: Q3.3 (E), R7.2
unnamed: C4.2, Q4.2 (C), Q5.3 (B), Q9.1 (C), R16.2
unnamed: Q5.2 (C), Q7.1 (B), R12.1
unnamed: Q5.1 (E), Q7.2 (C), R13.2
unnamed: C6.1, Q6.3 (B), Q9.3 (E), R9.2, VR1.3
unnamed: C6.2, Q6.2 (C), Q8.1 (B), R11.2
unnamed: Q6.1 (E), Q8.2 (C), R14.1
unnamed: Q9.2 (B), R16.1, VR1.1, VR1.2
SIGNAL_GND: C2.2, J2.1 (Pin_1_1), R2.1, R8.1

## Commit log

2026-09-10 Rename Power Amplifier Rod Elltior Project 3A - first page removed.pdf to Power Amplifier Rod Elltior Project 3A.pdf
2026-09-16 Rename Manufacturing/BOM/Power Amplifier Rod Elliot 20Project 3A.csv to Manufacturing/BOM/BOM csv/Power Amplifier Rod Elliot 20Project 3A.csv
    [Power Amplifier Rod Elliot 20Project 3A.csv]
2026-09-16 Rename Manufacturing/BOM/STM32 Speaker Protection Controller.csv to Manufacturing/BOM/BOM csv/STM32 Speaker Protection Controller.csv
    [STM32 Speaker Protection Controller.csv]
2026-09-16 Rename Manufacturing/BOM/Power_Amplifier_BOM.md to Manufacturing/BOM/BOM md/Power_Amplifier_BOM.md
2026-09-16 Rename Manufacturing/BOM/Protection_Controller_BOM.md to Manufacturing/BOM/BOM md/Protection_Controller_BOM.md
